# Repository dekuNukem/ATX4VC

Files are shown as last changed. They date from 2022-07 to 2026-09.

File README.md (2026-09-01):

# ATX4VC: ATX Power on Retro Computers!

[Buy ATX4VC](https://www.tindie.com/products/dekuNukem/atx4vc-atx-power-on-retro-computers/) | [Discord](https://discord.gg/T9uuFudg7j) | [User Manual](#user-manual) | [Table of Contents](#Table-of-Contents)

ATX4VC lets you **use ATX power supply on vintage computers**.

* Plug in ATX PSU on one end
* Get 12V, 5V, 3.3V, -12V, -5V out the other!

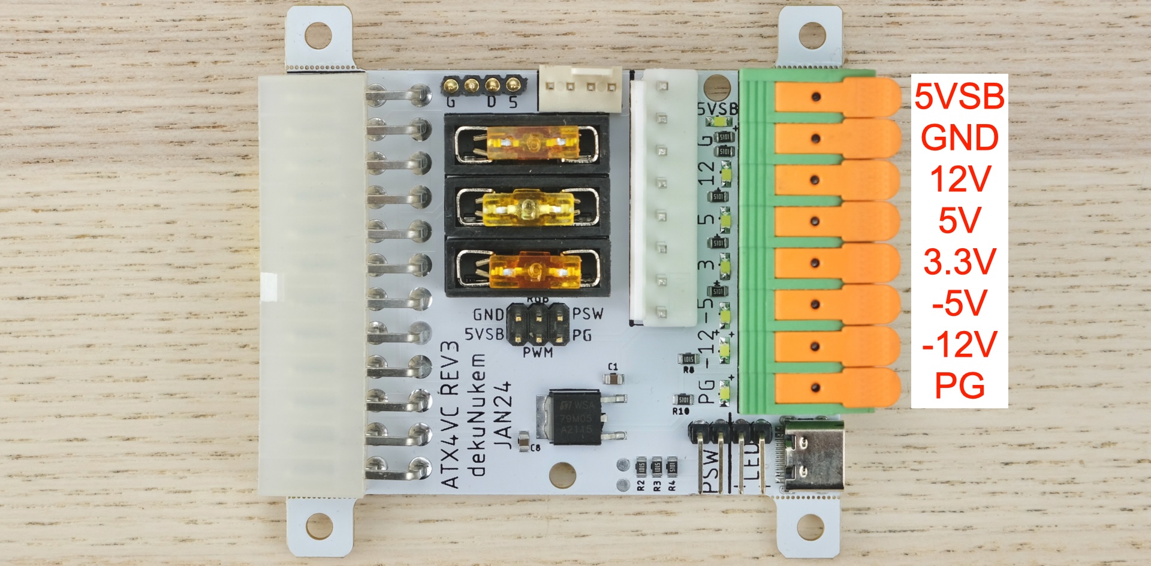
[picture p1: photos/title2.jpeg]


Features:

* All common voltage rails: +12V, +5V, +3.3V, -5V, -12V.
	* Also `5V Standby` and `Power-Good`
* Toolless Lever-Actuated Terminal Block
* USB-C Power Output
* 2x PC Fan Headers

You can use ATX4VC to:

* Replace retro computer PSUs
* Test and diagnose vintage hardware
* As general-purpose multi-voltage bench PSU

## Get ATX4VC

[Click me to get one!](https://www.tindie.com/products/dekuNukem/atx4vc-atx-power-on-retro-computers/)

## PicoRC

Also [check out PicoRC](https://picorc.com) for **device-specific** and **lower-cost** PicoPSU adaptors.

## Showcase

Here ATX4VC replaces the dead PSU in my IBM 5155 Portable PC, providing +12, +5, -12, and -5V.

Note the significant simplification and space/weight saving.

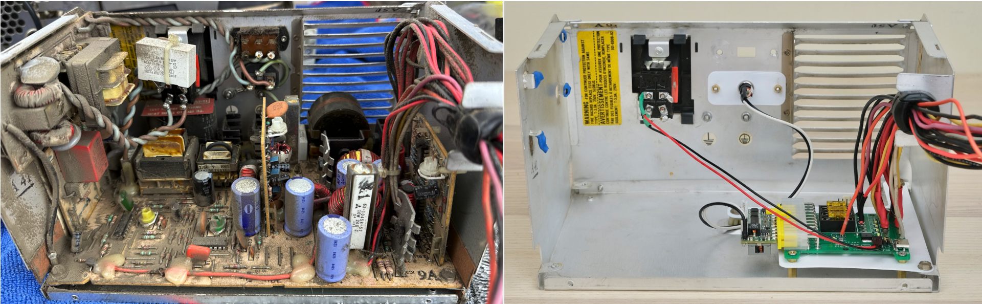
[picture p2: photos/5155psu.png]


It also works as a **multi-voltage bench PSU** for testing and diagnostics.

Here it powers a Macintosh Plus motherboard with +12, +5, and -12V.

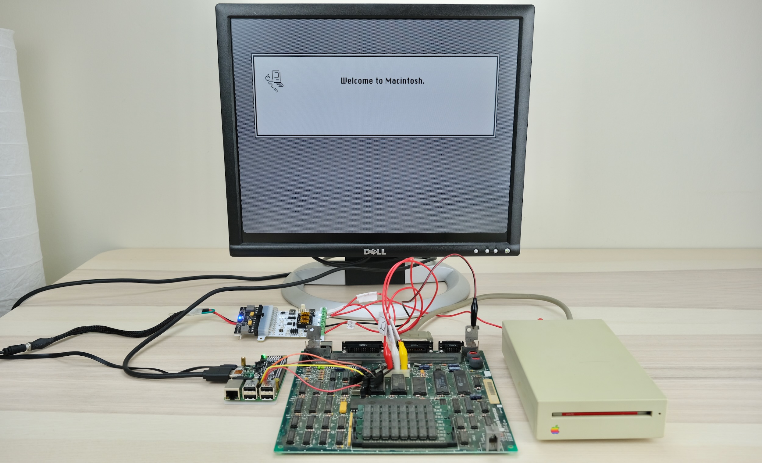
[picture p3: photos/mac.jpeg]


## Why

Power supplies are a major failure point of old computers today.

Those early PSUs are heavy, inefficient, and (slightly) explosive! After 40 odd years, many are not working, or worse might cause damage with out-of-spec voltages.

ATX4VC is designed to replace them with much more reliable modern ATX PSUs, and help test and diagnose vintage computers.

## User Manual

### ATX vs Pico PSU

ATX4VC works with **any ATX PSU**.

Although for **permanent retrofitting**, a **PicoPSU** is recommended due to its compact size.

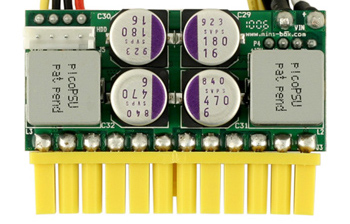
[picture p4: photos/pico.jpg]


* [Official website](https://www.mini-box.com/DC-DC) and [distributors](https://www.mini-box.com/site/resellers.html)
    * The cheapest **80W** one should be plenty for most
    * The **160W** variant is recommended if using many expansion cards and/or **spinning hard drive**
* Avoid **generic clones**
    * They over-rate and are of low quality
* A power brick with **12V DC** and **center positive** 5.5x2.5mm barrel jack is also needed.
    * They are very popular and you might already have one
    * Make sure it has enough wattage

### Quick Start

* Don't connect any load yet!

1. Plug in ATX connector
2. On **Power Mode** switch, select **Soft Power** (left position).
3. Press the button

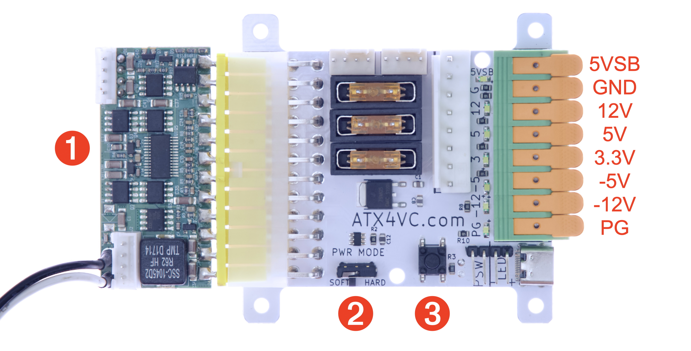
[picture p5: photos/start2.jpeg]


PSU should turn on, voltage rail LEDs should light up. 

That's the gist of it! **Please do keep reading** for more info.

### Power Modes

* Soft Power
    * **Short press** once to turn on
    * Short press again to turn off
    * Suitable for **momentary push buttons**
* Hard Power
    * **Hold down** to power on
    * **Release** to power off
    * Suitable for **latching buttons / flip switches**
    * Connected directly to ATX **PS_ON** Signal

### External Power Button and Power LED

You can also attach an **external power button** and **power LED** to the headers below:

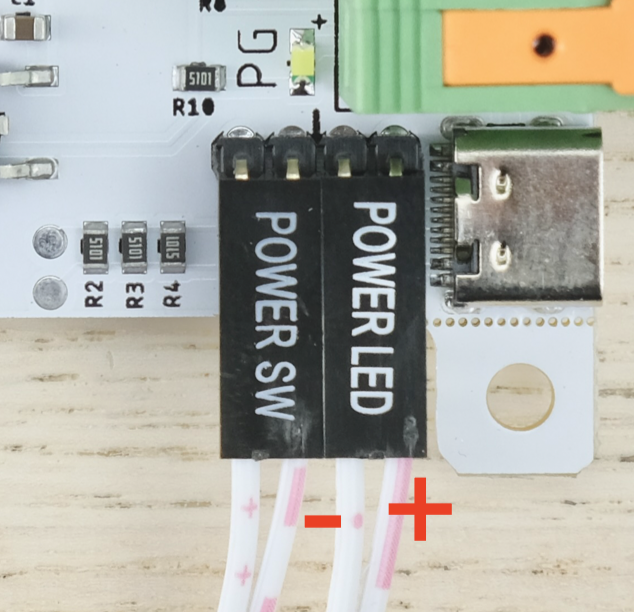
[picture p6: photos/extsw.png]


* Note LED polarity
* LED header has built-in **330 Ohm** resistor 
* Select suitable power mode
    * Soft Power: Momentary Pushbuttons
    * Hard Power: Latching Buttons / Flip Switches

### Power Connection

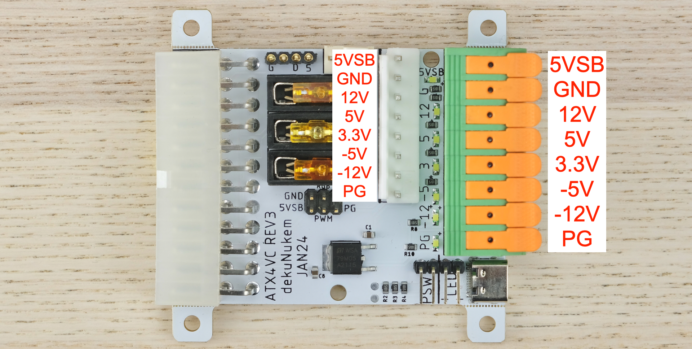
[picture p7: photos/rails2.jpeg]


* See photo for power rails
    * For aux output harness, use **8P JST VH 3.96** female connector.
* 5VSB = 5V Standby
    * Available even when PSU is off
* Power Good Signal
    * 5V when all rails are stable
    * 0V otherwise

To connect a wire:

* Strip the insulation about 12mm / 0.5in.
* Lift handle, insert, push back down.

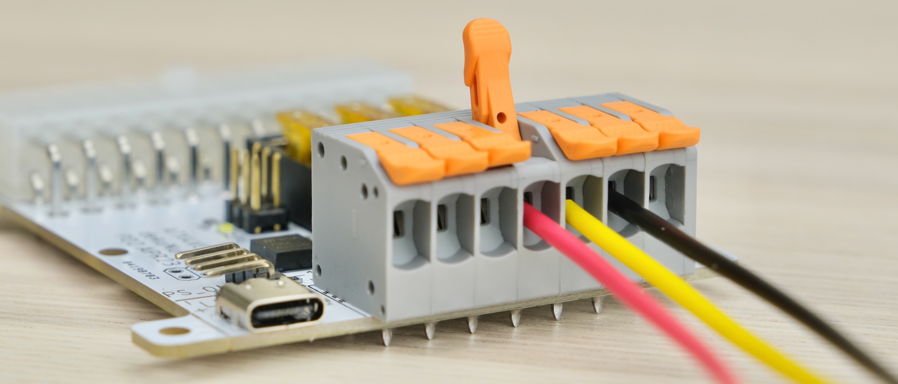
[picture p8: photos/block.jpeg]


Also, make sure the conductor is thick enough!

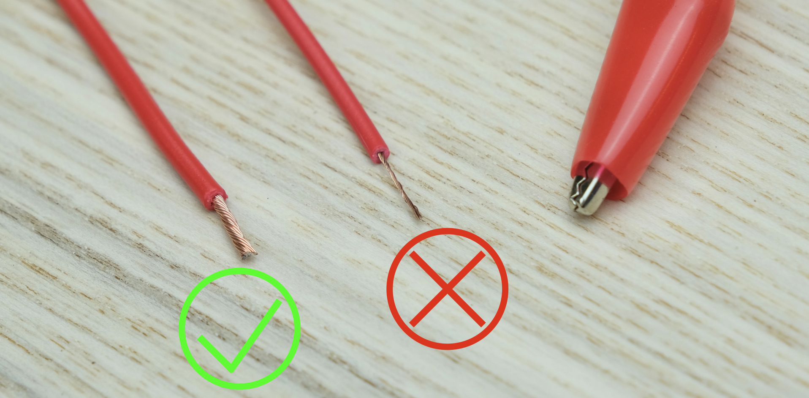
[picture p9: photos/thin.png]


Label the rails, vinyl stickers are available on the [product page](https://www.tindie.com/products/dekuNukem/atx4vc-atx-power-on-retro-computers/):

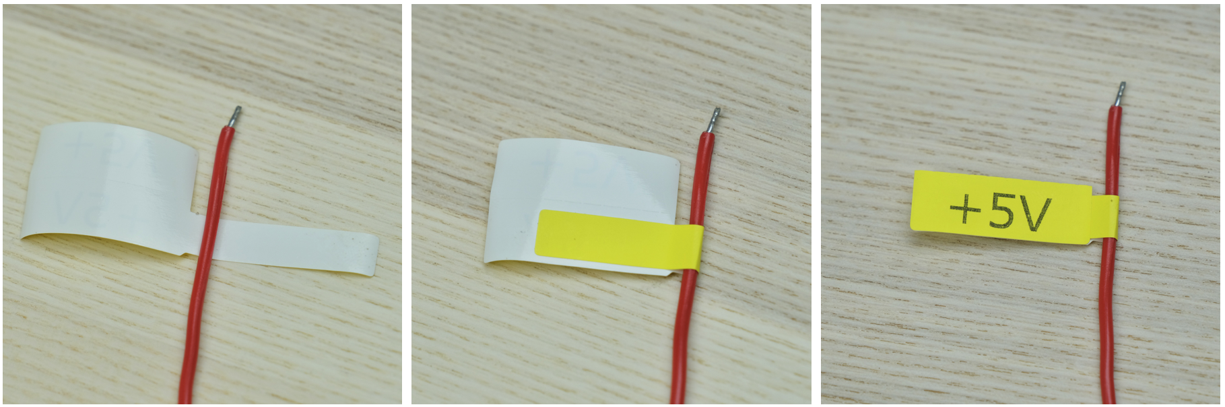
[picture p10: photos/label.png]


### Pre-flight Checks

Before powering up:

* Double check the **correct voltage terminal** is used
* Check for **dead shorts** between each voltage rail and GND, and between themselves!

Once powered up:

* Check voltage readings on each rail

Remember that ATX4VC **DOES NOT** monitor or condition voltage rails, so ensure the PSU itself is of good quality and trustworthy!

### Current Limit

* **`5 AMPS MAX`** OVER **ANY SINGLE RAIL**
* **`7 AMPS MAX`** **TOTAL CURRENT** OVER ALL RAILS

If more is needed, **tap the power directly** from a Molex connector.

See your PSU label or datasheet to see how much current it can provide:

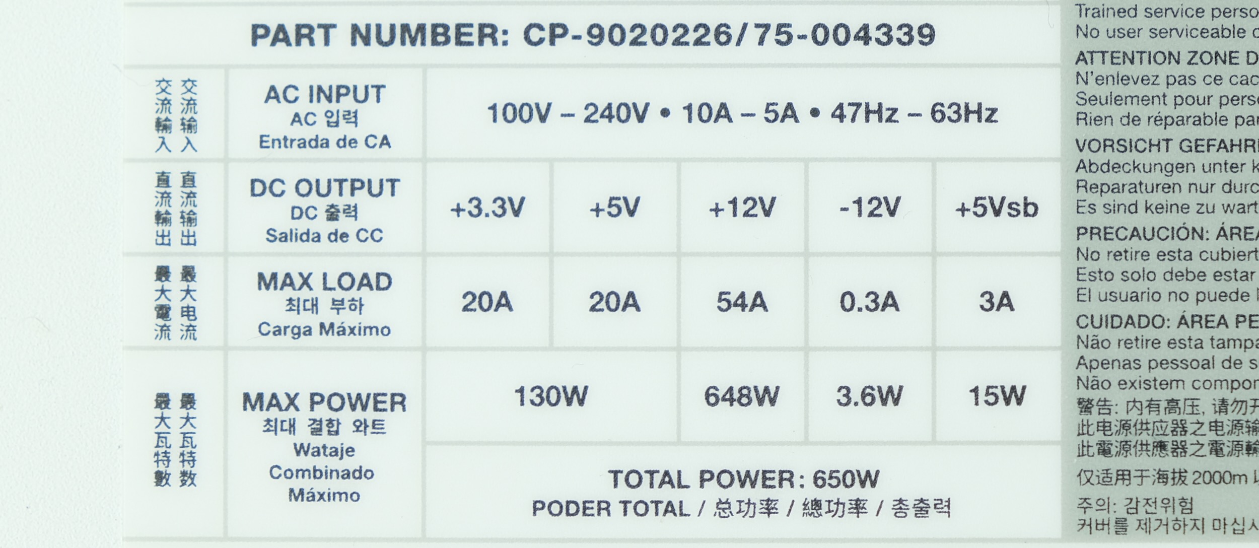
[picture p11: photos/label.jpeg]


### Fuses

* USE FUSES RATED **5A OR LESS**
* **DO NOT BYPASS FUSES**

ATX4VC uses common **automotive fuses**.

Regular, Mini, and Low-profile Mini all work.

Simply push into the holder.

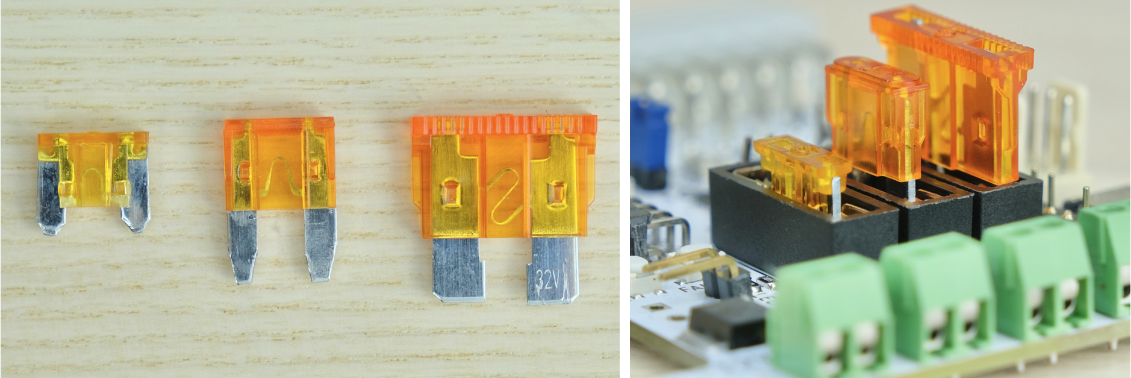
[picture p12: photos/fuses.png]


### Fan Headers

Two PC Fan headers are available. You can plug in any regular **12V PC fan**, both 3-Pin and 4-Pin.

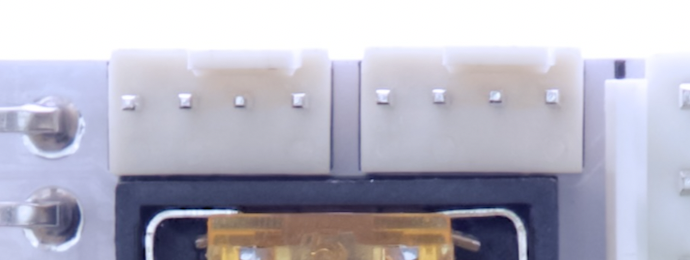
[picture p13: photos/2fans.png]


### USB-C Power Output

An USB-C port is available for **powering external devices**.

* **OUTPUT ONLY**, **DO NOT BACKFEED** with another powered device.

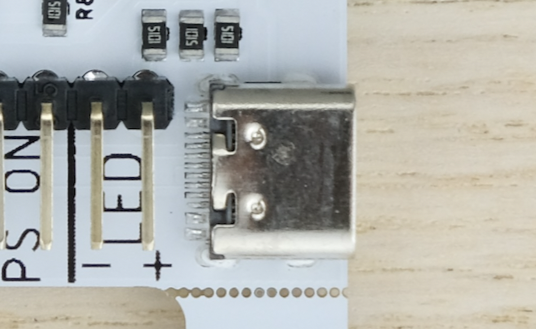
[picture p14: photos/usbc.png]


## Questions or Comments?

Feel free to ask in official [Discord Chatroom](https://discord.gg/T9uuFudg7j), raise a [Github issue](https://github.com/dekuNukem/ATX4VC/issues), or email `dekunukem` `gmail.com`!

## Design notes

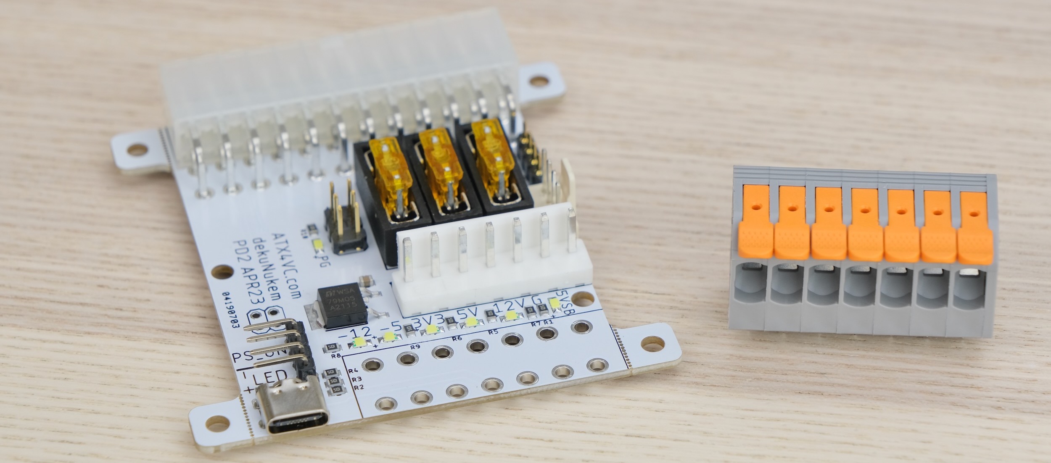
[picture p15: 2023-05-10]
photos/noblock.jpeg

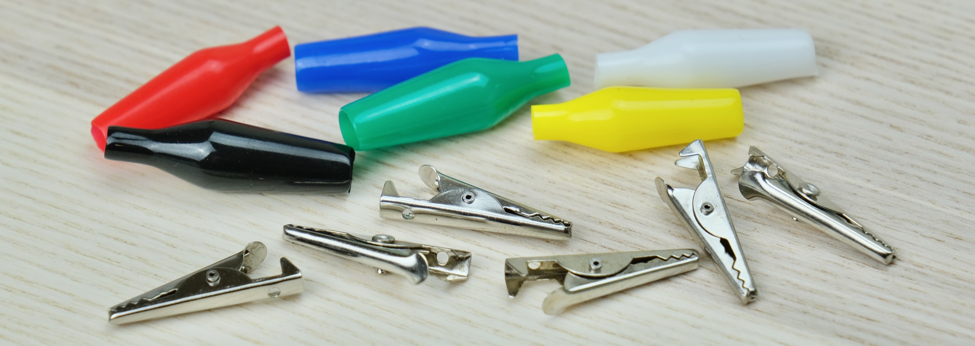
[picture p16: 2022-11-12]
photos/clips.jpeg

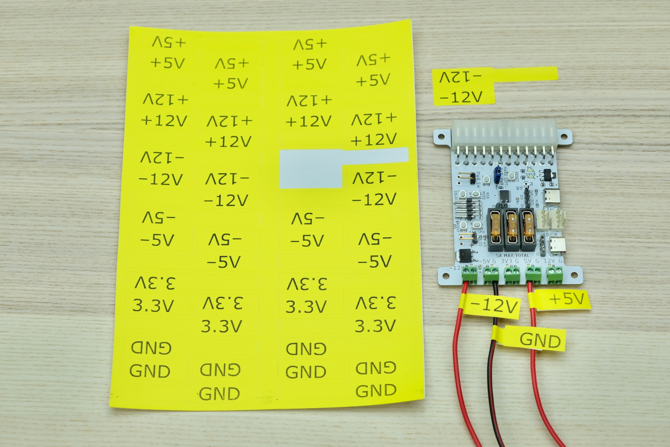
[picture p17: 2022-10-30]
photos/stickers.jpeg

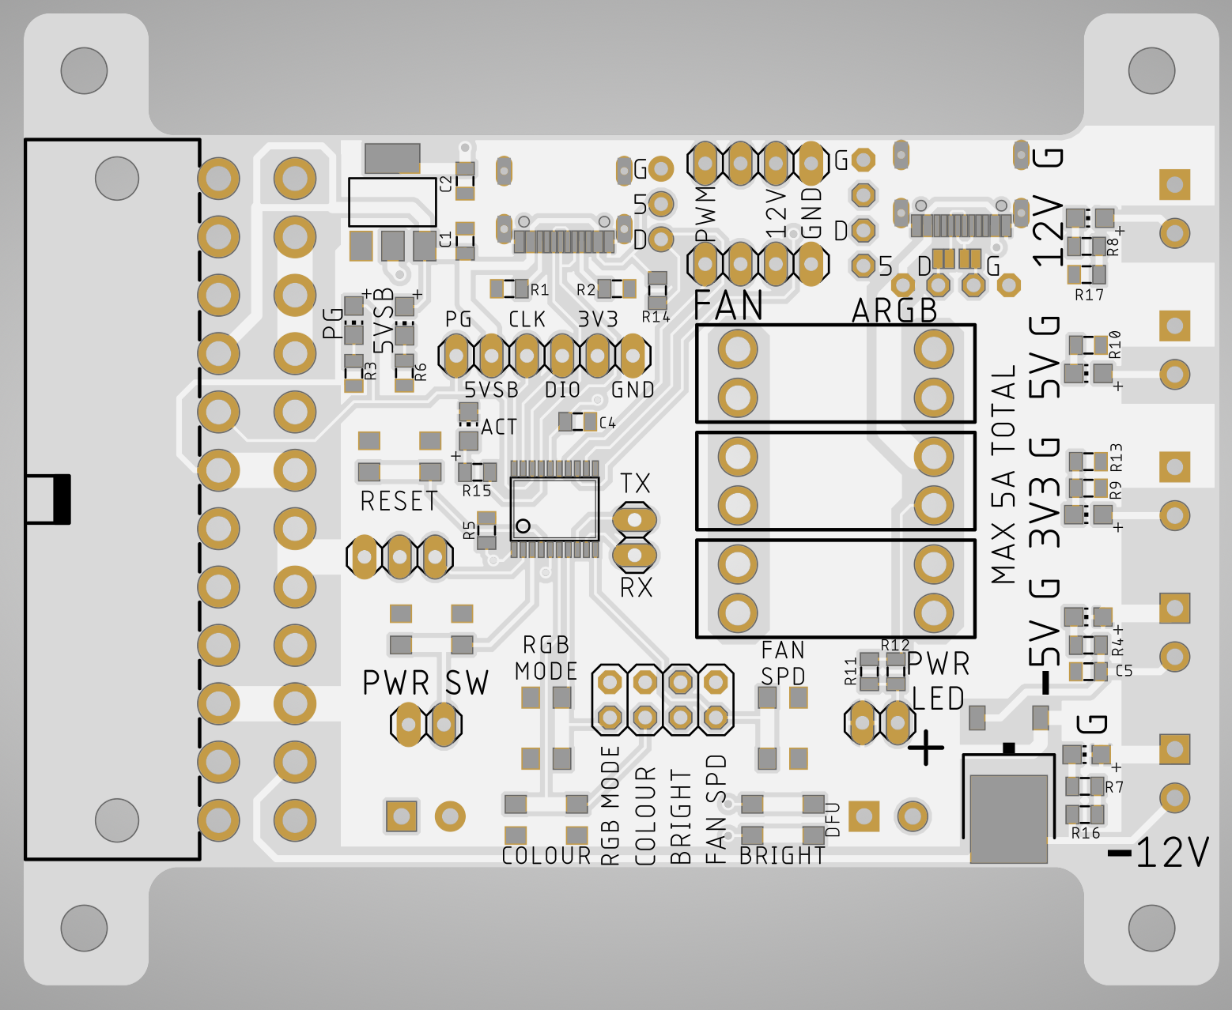
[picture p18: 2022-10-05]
photos/dp.png

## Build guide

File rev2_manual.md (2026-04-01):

# ATX4VC: ATX Power on Retro Computers!

[Buy ATX4VC](https://www.tindie.com/products/dekuNukem/atx4vc-atx-power-on-retro-computers/) | [Discord](https://discord.gg/T9uuFudg7j) | [User Manual](#user-manual) | [Table of Contents](#Table-of-Contents)

ATX4VC lets you **use ATX power supply on vintage computers**.

* Plug in ATX PSU on one end
* Get 12V, 5V, 3.3V, -12V, -5V out the other!



Features:

* All common voltage rails: +12V, +5V, +3.3V, -5V, -12V.
	* Also `5V Standby` and `Power-Good`
* Tool-less Lever-Actuated Terminal Block
* USB-C and Auxiliary Power Output
* PC Fan Header

You can use ATX4VC to:

* Replace retro computer PSUs
* Test and diagnose vintage hardware
* As general-purpose multi-voltage bench PSU

## Get ATX4VC

[Click me to get one!](https://www.tindie.com/products/dekuNukem/atx4vc-atx-power-on-retro-computers/)

## PicoRC

Also [Check out PicoRC](https://github.com/dekuNukem/PicoRC) for **device-specific** and **lower-cost** PicoPSU adaptors.

## Showcase

Here ATX4VC replaces the dead PSU in my IBM 5155 Portable PC, providing +12, +5, -12, and -5V.

Note the significant simplification and space/weight saving.



It also works as a multi-voltage bench PSU for testing and diagnostics.

Here it powers a Macintosh Plus motherboard with +12, +5, and -12V.



## Why / Project Goals

Power supplies are a major failure point of old computers today.

Those early PSUs are heavy, inefficient, hot, and (slightly) explosive! After 40 odd years, many are not working, or worse might cause damage with out-of-spec voltages.

ATX4VC is designed to replace them with much more reliable modern ATX PSUs, and help test and diagnose vintage computers.

## Table of Contents

- [Pico PSU](#get-a-pico-psu)
- [Quick Start](#quick-start)
- [Power Button](#power-button)
- [Power Connection](#power-connection)
- [Pre-flight Checks](#pre-flight-checks)
- [Current Limit](#current-limit)
- [Fuses](#fuses)
- [Fan Headers](#fan-headers)
- [USB-C Power Output](#usb-c-power-output)

## User Manual

### ATX vs Pico PSU

ATX4VC works with **any ATX PSU**.

Although for **permanent retrofitting**, a **PicoPSU** is recommended due to its compact size.



* [Official website](https://www.mini-box.com/DC-DC) and [distributors](https://www.mini-box.com/site/resellers.html)
    * The cheapest **80W** one should be plenty for most
    * The **160W** variant is recommended if using many expansion cards and/or **spinning hard drive**
* Avoid **generic clones**
    * They over-rate and are of low quality
* A power brick with **12V DC** and **center positive** 5.5x2.5mm barrel jack is also needed.
    * They are very popular and you might already have one
    * Make sure it has enough wattage

### Quick Start

* Plug in ATX connector
* Plug in Power Button (left two pins)



Press the button. PSU should turn on, voltage rail LEDs should light up. 

That's the gist of it! **Please do keep reading** for more info.

### Power Button and LED

The power button should be latching type (aka NOT momentary).

You can also hook up a Power LED (right two pins, note polarity, resistor NOT needed).

### Power Connection



* Pinout is the same on terminal block and auxiliary connector.
    * For aux output harness, use **8P VH 3.96** female connector.
* 5VSB = 5V Standby
    * Available even when PSU is off
* Power Good Signal
    * 5V when all rails are stable
    * 0V otherwise

To connect a wire:

* Strip the insulation about 12mm / 0.5in.
* Lift handle, insert, push back down.



Also, make sure the conductor is thick enough!



Label the rails, vinyl stickers are available on the [product page](https://www.tindie.com/products/dekuNukem/atx4vc-atx-power-on-retro-computers/):



### Pre-flight Checks

Before powering up:

* Double check the **correct voltage terminal** is used
* Check for **dead shorts** between each voltage rail and GND, and between themselves!

Once powered up:

* Check voltage readings on each rail

Remember that ATX4VC **DOES NOT** monitor or condition PSU voltage outputs, ensure the PSU itself is of good quality and trustworthy!

### Current Limit

* **`5 AMPS MAX`** OVER **ANY SINGLE RAIL**
* **`7 AMPS MAX`** **TOTAL CURRENT** OVER ALL RAILS

If more is needed, **tap the power directly** from a Molex connector.

See your PSU label or datasheet to see how much current it can provide:



### Fuses

* USE FUSES RATED **5A OR LESS**
* **DO NOT BYPASS FUSES**

ATX4VC uses common **automotive fuses**.

Regular, Mini, and Low-profile Mini all work.

Simply push into the holder.



### Fan Headers

A PC Fan header is available. You can plug in any standard 12V PC fan, both 3-Pin and 4-Pin.

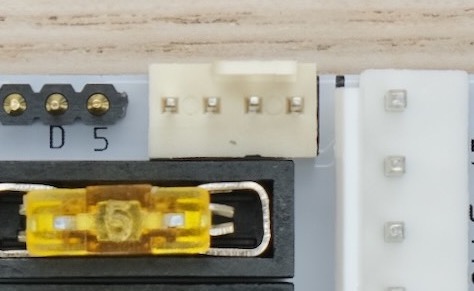
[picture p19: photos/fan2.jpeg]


By default it will run at full speed.

PWM speed control and temperature probe is supported on optional [MCU daughterboard](#mcu-daughterboard).

### USB-C Power Output

USB-C connectors are available for powering external devices.

The port on ATX4VC itself is on regular 5V rail.

The port on MCU daughterboard is on 5V standby. Lower current but always available.

Those ports are **output only**, don't try to backfeed with another powered device.

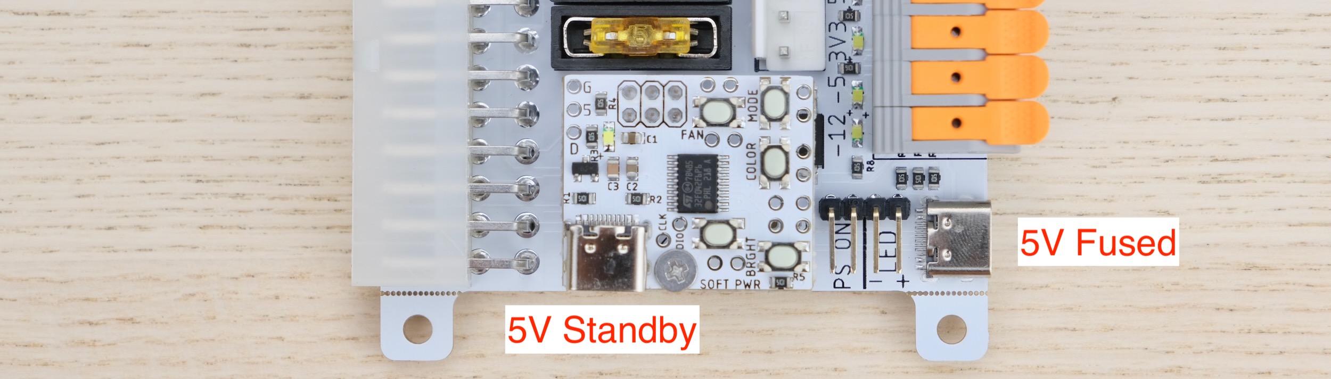
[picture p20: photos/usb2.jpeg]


## MCU Daughterboard

The optional MCU daughterboard adds many new features:

* **Soft power** with momentary buttons
* Addressable RGB (**ARGB**) lighting. Adjustable brightness, animation, and color.
* DS18B20 **Temperature Probe** support
* PWM **fan speed control**
* 5V Standby USB-C power output

### Installation

The MCU board should come with two screws and a standoff:

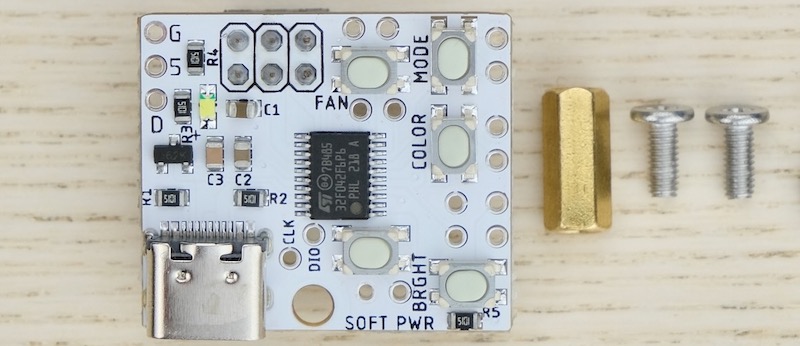
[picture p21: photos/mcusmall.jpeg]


* Put one screw from bottom side
* Install and tighten the standoff
* Plug in the MCU board
* Secure it in place with the other screw

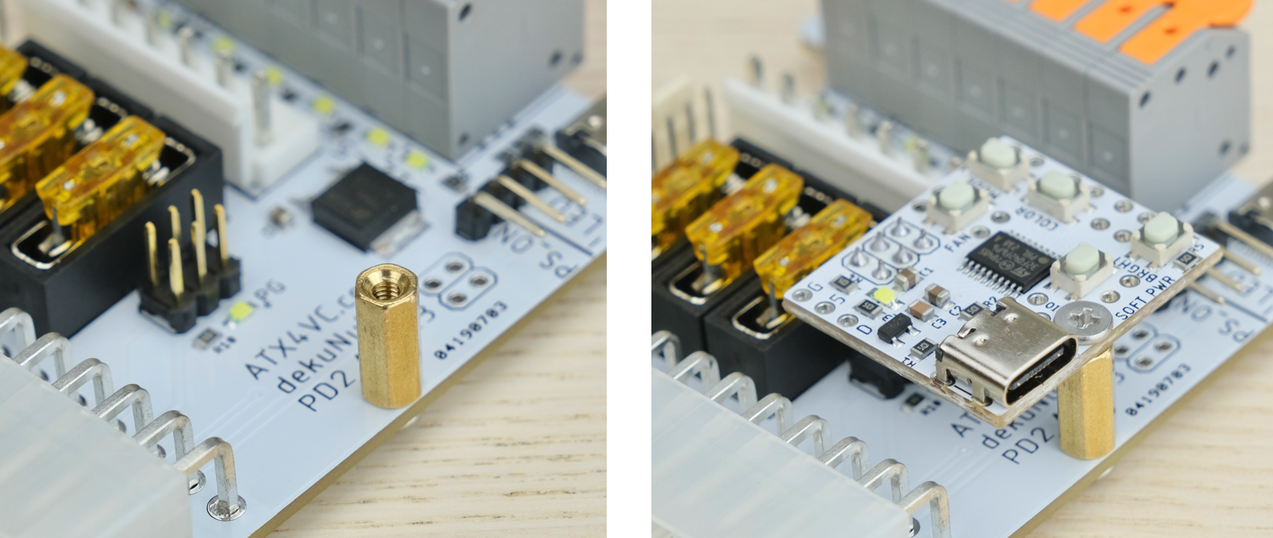
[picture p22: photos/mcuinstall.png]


### Soft Power

Press the soft power button to turn on, press again to turn off.

You can also solder a header for an external button.

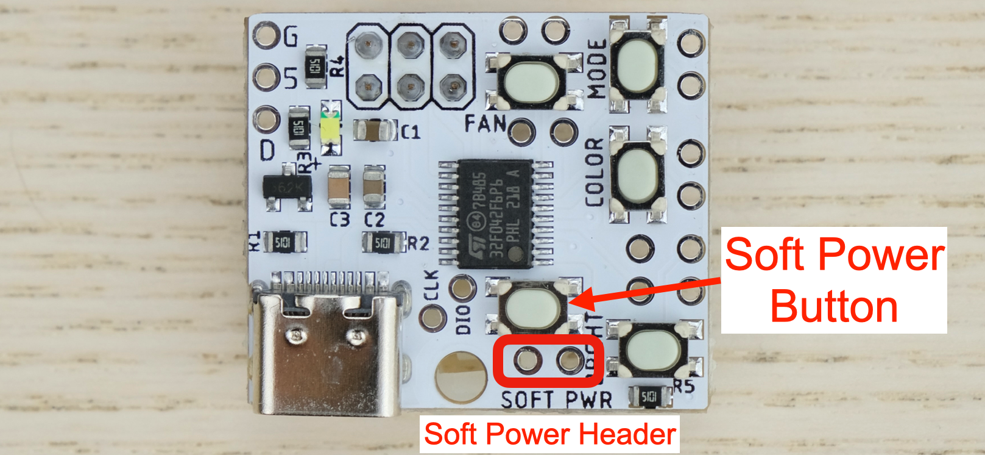
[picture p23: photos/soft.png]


### ARGB animation

Plug device into the ARGB header.

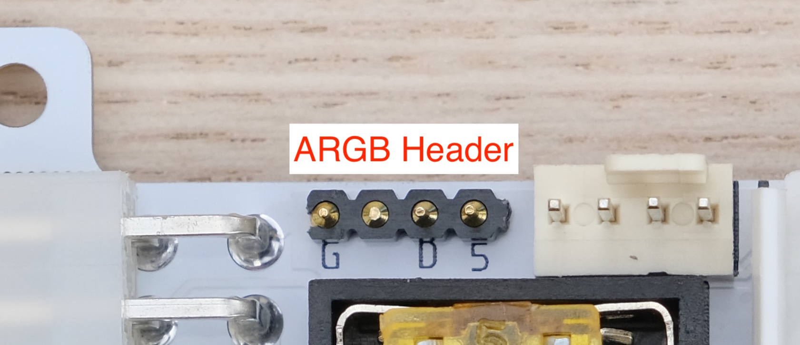
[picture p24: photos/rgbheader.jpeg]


Use **RGB Mode**, **Color**, and **Brightness** button to adjust settings. Headers are available for external buttons.

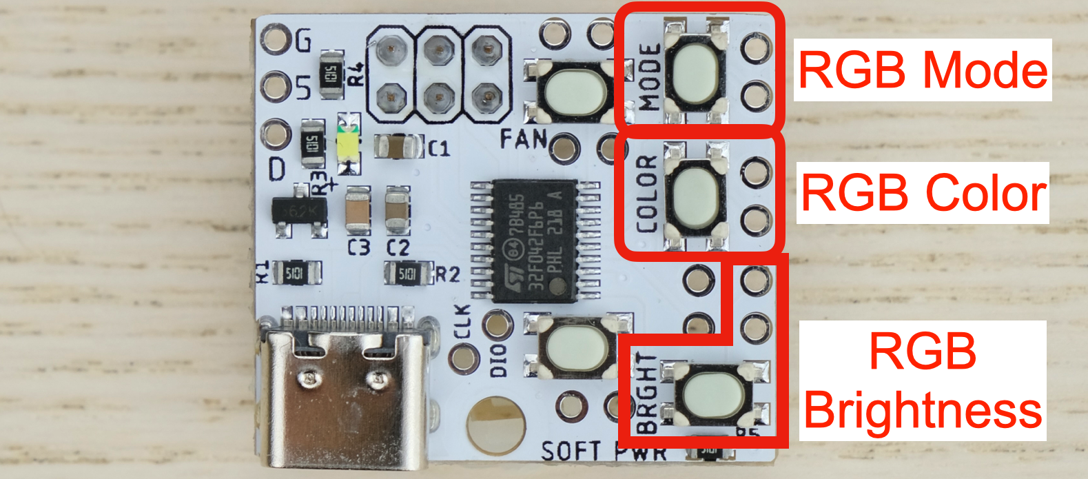
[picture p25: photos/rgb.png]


### Fan Speed

Press `FAN SPD` button to cycle through different speeds:

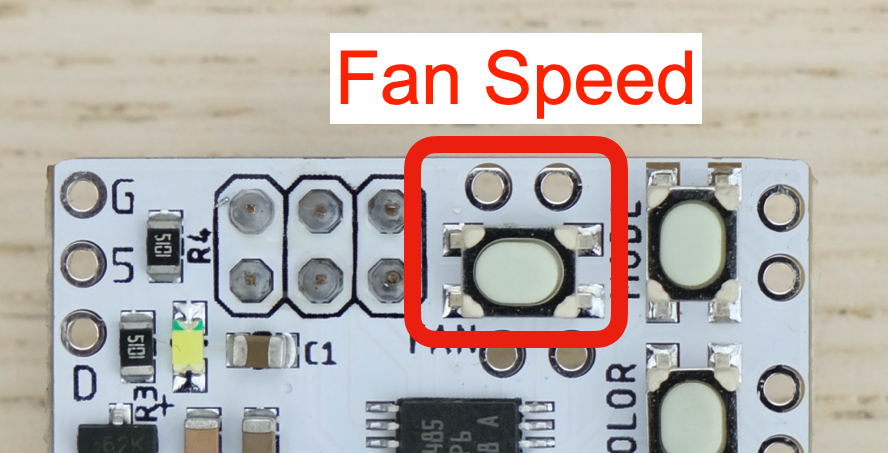
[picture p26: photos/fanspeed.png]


### Temperature Probe

ATX4VC supports the DS18B20 temperature sensor. They are inexpensive and very popular in Arduino projects.

The cheap ones are almost certainly counterfeits! They'll still work, but readings are noisier and less accurate.

Try a reputable distributor like [Sparkfun](https://www.sparkfun.com/products/11050), [Adafruit](https://www.adafruit.com/product/381), Mouser, or Digikey.

Connect the headers. Usually VCC is red, GND is black, DATA is yellow.

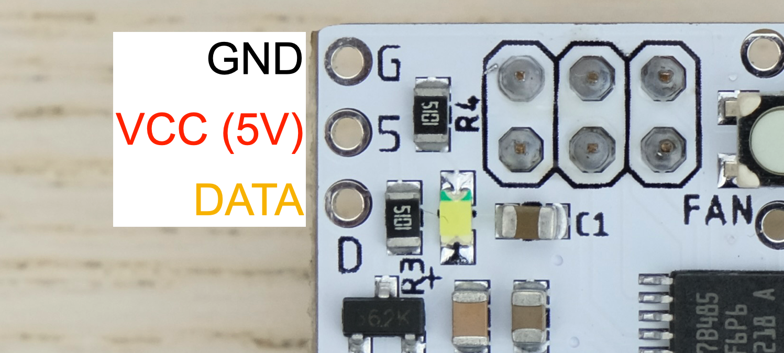
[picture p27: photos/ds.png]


Press **FAN SPD** button until the user LED `slowly blinks 5 times`. Now fan speed will depend on the temperature reading.

The fan starts to speed up at 25°C, and reaches full speed at 50°C. If probe is not detected, it will run at full speed.

You can use a heat gun and air duster to test it.

## Questions or Comments?

Feel free to ask in official [Discord Chatroom](https://discord.gg/T9uuFudg7j), raise a [Github issue](https://github.com/dekuNukem/ATX4VC/issues), or email `dekunukem` `gmail.com`!

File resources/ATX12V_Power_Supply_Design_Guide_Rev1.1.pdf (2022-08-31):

# ATX / ATX12V Power Supply Design Guide

Version 1.1

ATX/ATX12V Power Supply Design Guide
Version 1.1

IMPORTANT INFORMATION AND DISCLAIMERS

1. INTEL CORPORATION (AND ANY CONTRIBUTOR) MAKES NO WARRANTIES WITH REGARD TO THIS DOCUMENT AND IN PARTICULAR DOES NOT WARRANT OR REPRESENT THAT THIS DOCUMENT OR ANY PRODUCTS MADE IN CONFORMANCE WITH IT WILL WORK IN THE INTENDED MANNER. NOR DOES INTEL (OR ANY CONTRIBUTOR) ASSUME RESPONSIBILITY FOR ANY ERRORS THAT THE DOCUMENT MAY CONTAIN OR HAVE ANY LIABILITIES OR OBLIGATIONS FOR DAMAGES INCLUDING, BUT NOT LIMITED TO, SPECIAL, INCIDENTAL, INDIRECT, PUNITIVE, OR CONSEQUENTIAL DAMAGES WHETHER ARISING FROM OR IN CONNECTION WITH THE USE OF THIS DOCUMENT IN ANY WAY.
2. NO REPRESENTATIONS OR WARRANTIES ARE MADE THAT ANY PRODUCT BASED IN WHOLE OR IN PART ON THE ABOVE DOCUMENT WILL BE FREE FROM DEFECTS OR SAFE FOR USE FOR ITS INTENDED PURPOSE. ANY PERSON MAKING, USING OR SELLING SUCH PRODUCT DOES SO AT HIS OR HER OWN RISK.
3. THE USER OF THIS DOCUMENT HEREBY EXPRESSLY ACKNOWLEDGES THAT THE DOCUMENT IS PROVIDED AS IS, AND THAT INTEL CORPORATION (AND ANY CONTRIBUTOR) MAKES NO REPRESENTATIONS, EXTENDS NO WARRANTIES OF ANY KIND, EITHER EXPRESS OR IMPLIED, ORAL OR WRITTEN, INCLUDING ANY WARRANTY OF MERCHANTABILITY OR FITNESS FOR A PARTICULAR PURPOSE, OR WARRANTY OR REPRESENTATION THAT THE DOCUMENT OR ANY PRODUCT OR TECHNOLOGY UTILIZING THE DOCUMENT OR ANY SUBSET OF THE DOCUMENT WILL BE FREE FROM ANY CLAIMS OF INFRINGEMENT OF ANY INTELLECTUAL PROPERTY, INCLUDING PATENTS, COPYRIGHT AND TRADE SECRETS NOR DOES INTEL (OR ANY CONTRIBUTOR) ASSUME ANY OTHER RESPONSIBILITIES WHATSOEVER WITH RESPECT TO THE DOCUMENT OR SUCH PRODUCTS.
4. NO LICENSE, EXPRESS OR IMPLIED, BY ESTOPPEL OR OTHERWISE, TO ANY INTELLECTUAL PROPERTY RIGHTS IS GRANTED HEREIN.

Copyright 2000 Intel Corporation. All rights reserved.

Version 1.1
† Third-party brands and names are the property of their respective owners.

Revision History

Version | Summary of Changes | Date
1.0 | Initial Release | Feb. 2000
1.1 | Increase 3.3 V current; add more explanation for power sharing; do minor edits and format fixes | Aug. 2000

# Contents

4.5.3. Auxiliary Power Connector for Configurations with +3.3 VDC Output > 18 A
6.2. Input Line Current Harmonic Content and Line Flicker Required for Sales

### Figures

Figure 1. Differential Noise Test Setup | | 15
Figure 2. Power Supply Timing | | 17
Figure 3. PS_ON# Signal Characteristics | | 19
Figure 4. Power Supply Dimensions for Chassis in Which the P/S Does Not Cool Processor | | 23
Figure 5. Power Supply Dimensions for Chassis in Which the P/S Cools the Processor | | 24
Figure 6. ATX and ATX12V Power Supply Connectors | | 27

### Tables

Table 1. Power Supply Feature Summary, ATX versus ATX12V | | 7
Table 2. AC Input Line Requirements | | 9
Table 3. DC Output Voltage Regulation | | 10
Table 4. Typical Power Distribution for a 160 W ATX Configuration | | 11
Table 5. Typical Power Distribution for a 200 W ATX Configuration | | 12
Table 6. Typical Power Distribution for a 250 W ATX Configuration | | 12
Table 7. Typical Power Distribution for a 300 W ATX Configuration | | 12
Table 8. Typical Power Distribution for a 200 W ATX12V Configuration | | 13
Table 9. Typical Power Distribution for a 250 W ATX12V Configuration | | 13
Table 10. Typical Power Distribution for a 300 W ATX12V Configuration | | 14
Table 11. DC Output Noise/Ripple | | 15
Table 12. DC Output Transient Step Sizes | | 16
Table 13. Output Capacitive Loads | | 16
Table 14. PWR_OK Signal Characteristics | | 18
Table 15. PS_ON# Signal Characteristics | | 18
Table 16. Overvoltage Protection | | 20

# 1. Introduction

## 1.1. Scope

This document provides design suggestions and reference specifications for a family of power supplies that comply with the ATX Specification, Version 2.03*
for motherboards
and chassis. It includes supplementary information not expressly detailed in the ATX Specification, such as information about the physical form factor of the power supply, cooling requirements, connector configuration, and pertinent electrical and signal timing specifications.
This document is provided as a convenience only and is not intended to replace the user’s independent design and validation activity. It should not be inferred that all ATX or ATX12V power supplies must conform exactly to the content of this document. Neither are the design specifics described herein intended to support all possible system configurations, because system power supply needs vary widely depending on factors such as the application (that is, for desktop, workstation, or server), intended ambient environment (temperature, line voltage), or motherboard power requirements.

## 1.2. New for ATX12V as Compared with ATX Power Supply

This section briefly summarizes the major changes made to this document that now includes the ATX12V power supply. An earlier design guide covered only the ATX power supply. There are also a few changes from Version 1.0 to 1.1 (increased 3.3 V current, more explanation for power sharing).

### 1.2.1. ATX12V

A new superset of the original ATX power supply has been defined. Named “ATX12V,” this new power supply is comprised of a standard ATX unit plus the following enhancements:
- Increased +12 VDC output capability. Motherboard components with unique voltage requirements are increasingly expected to be powered via DC/DC converters off the +12 VDC power supply output. This trend is due primarily to the higher power conversion and transmission efficiencies of +12 VDC relative to +5 VDC or +3.3 VDC. ATX12V power supplies should be designed to accommodate these increased +12 VDC current requirements and to address associated issues such as cross-regulation, capacitive loading, transient surge tolerance, cable voltage drop, and cooling.

*
2.03 is the current version of the ATX Specification as of this writing. Future references to the ATX Specification in this document imply version 2.03 or later, as applicable.

- Power Connectors. To enable the delivery of more +12 VDC current to the motherboard, a new 4-pin receptacle/header combination—the +12 V power connector—has been defined. The presence of the +12 V power connector indicates that a power supply is ATX12V; the absence of the +12 V power connector indicates that a supply is ATX. To allow for greater than 3.3 V current, the Aux Power Connector is recommended for ATX and ATX12V power supplies with 3.3 V current > 18 A. See Sections 3.2.3.2 and 4.5 for details on the +12 V and AUX power connector.
ATX12V power supplies are intended to be downward compatible with ATX power supplies. Consequently, it is required that an ATX12V power supply be able to provide the same typical +5 VDC and +3.3 VDC maximum continuous output currents as an ATX supply of the same total output power. To minimize cost, this may be accomplished via a load sharing arrangement, whereby the individual +12 VDC, +5 VDC, and +3.3 VDC output currents may trade off against each other but the combined total output power is constrained to not exceed a limit specified by the power supply designer. Such an approach can effectively support both +5 VDC- or +12 VDC-centric motherboards.
The standard ATX power supply definition will be maintained in parallel with ATX12V— despite the downward compatibility of ATX12V—because both offer distinct advantages to the industry:
- An ATX power supply supports motherboards that rely on DC/DC conversion from +5 VDC or +3.3 VDC only. This limitation and an initial volume advantage make it more attractive for focussed, cost-sensitive system platforms.
- An ATX12V power supply supports motherboards that rely on DC/DC conversion from either +12 VDC, +5 VDC, or +3.3 VDC, yielding more application flexibility for future platforms.

### 1.2.2. Increased +5 VSB Current

Trends in PC system power management solutions (for example, “Instantly Available PC,” “Suspend-to-RAM”) are driving a need for increased +5 VSB current capability for all ATX-family power supplies. The previous +5 VSB output requirement is being raised to 1.0 amps minimum, with 2.0 amps preferred. Recommendations for momentary peak current have also been added to enable USB "wake on" devices. See Section 3.3.3 for details.
Table 1. Power Supply Feature Summary, ATX versus ATX12V
ATX | ATX12V
+12 V power connector No | Yes
+5 VSB current | 1.0 amps 1.5 Peak (required)
2.0 amps 2.5 Peak (recommended)

1.0 amps 1.5 Peak (required)
2.0 amps 2.5 Peak (recommended)

# 2. Applicable Documents

The latest revision in effect of the following documents forms a part of this document to the extent specified.

Document title | Description
AB13-94-146 | European Association of Consumer Electronics Manufacturers (EACEM) Hazardous Substance List / Certification
ANSI C62.41-1991 | IEEE Recommended Practice on Surge Voltages in Low-Voltage AC Circuits
ANSI C62.45-1992 | IEEE Guide on Surge Testing for Equipment Connected to Low-Voltage AC Power Circuits
MIL-STD-105K | Quality Control
MIL-STD-217F | Reliability Predictions for Electronic Equipment
MIL-C-5541 | Chemical Conversion Coatings on Aluminum and Aluminum Alloys
CSA C22.2 No.234, Level 3 | Safety of Component Power Supplies (Intended for use with Electronic Data Processing Equipment and Office Machines)
CAN/CSA C22.2 No.950-95, 3rd edition | Safety of Information Technology Equipment Including Electrical Business Equipment
UL 1950, 3rd edition, without D3 Deviation | Safety of Information Technology Equipment Including Electrical Business Equipment
IEC 60950 plus A1, A2, A3, A4 | Safety of Information Technology Equipment Including Business Equipment
EN 60950 plus A1, A2, A3, A4 | Safety of Information Technology Equipment Including Business Equipment
EMKO-TSE (74-SEC) 207/94 | Nordic national requirement in addition to EN 60950
CISPR 22:1997 3rd edition EN 55022:1998 | Limits and Methods of Measurements of Radio Interference Characteristics of Information Technology Equipment, Class B
ANSI C63.4 – 1992 | American National Standard for Methods of Measurement of Radio-Noise Emissions from Low-Voltage Electrical and Electronic Equipment in the Range of 9 kHz to 40 GHz for EMI testing
EN 55024:1998 | Information technology equipment—Immunity characteristics—Limits and methods of measurement
EN 61000-3-2 | Electromagnetic compatibility (EMC)—Part 3: Limits—Section 2: Limits for harmonic current emissions, Class D
IEC 61000-4- | Electromagnetic compatibility (EMC) for industrial-process measurement and control equipment—Part 4: Testing and measurement techniques Section -2: Electrostatic discharge Section -3: Radiated, radio-frequency, electromagnetic field Section -4: Electrical fast transient / burst Section -5: Surge Section -6: Conducted disturbances, induced by radio-frequency fields Section -8: Power frequency magnetic fields Section -11: Voltage dips, short interruptions, and voltage variations
Japan Electric Association | Guidelines for the Suppression of Harmonics in Appliances and General Use Equipment
IEC Publication 417 | International Graphic Symbol Standard
ISO Standard 7000 | Graphic Symbols for Use on Equipment
CFR 47, Part 15, Subpart B | FCC Rules

# 3. Electrical

The electrical requirements that follow are to be met over the environmental ranges specified in Section 5 unless otherwise noted.

## 3.1. AC Input

Table 2 lists AC input voltage and frequency requirements for continuous operation. The power supply shall be capable of supplying full-rated output power over two input voltage ranges rated 100-127 VAC and 200-240 VAC rms nominal. The correct input range for use in a given environment may be either switch-selectable or autoranging. The power supply shall automatically recover from AC power loss. The power supply must be able to start up under peak loading at 90 VAC.
Table 2. AC Input Line Requirements
Parameter | Min. | Nom. ⁽¹⁾ | Max. | Unit
Vin (115 VAC) | 90 | 115 | 135 | VACrms
Vin (230 VAC) | 180 | 230 | 265 | VACrms
Vin Frequency | 47 | -- | 63 | Hz
(1) Nominal voltages for test purposes are considered to be within ±1.0 V of nominal.

### 3.1.1. Input Overcurrent Protection

The power supply shall incorporate primary fusing for input overcurrent protection to prevent damage to the power supply and meet product safety requirements. Fuses should be slow-blow–type or equivalent to prevent nuisance trips.

### 3.1.2. Inrush Current Limiting

Maximum inrush current from power-on (with power on at any point on the AC sine) and including, but not limited to, three line cycles, shall be limited to a level below the surge rating of the input line cord, AC switch if present, bridge rectifier, fuse, and EMI filter components. Repetitive ON/OFF cycling of the AC input voltage should not damage the power supply or cause the input fuse to blow.

### 3.1.3. Input Undervoltage

The power supply shall contain protection circuitry such that the application of an input voltage below the minimum specified in Section 3.1, Table 2, shall not cause damage to the power supply.

### 3.1.4. Immunity

At a minimum, a system and power supply typically must pass testing per the limits and methods described in EN 55024 prior to sale in many parts of the world. Additional requirements may depend on the design, product end use, target geography, customer, and other variables. Consult your company’s Product Safety and Regulations department for more details.

### 3.1.5. Catastrophic Failure Protection

Should a component failure occur, the power supply should not exhibit any of the following:
- Flame
- Excessive smoke
- Charred PCB
- Fused PCB conductor
- Startling noise
- Emission of molten material

## 3.2. DC Output

### 3.2.1. DC Voltage Regulation

The DC output voltages shall remain within the regulation ranges shown in Table 3 when measured at the load end of the output connectors under all line, load, and environmental conditions. The voltage regulation limits shall be maintained under continuous operation for a period of time equal to or greater than the MTBF specified in Section 7.2 at any steady state temperature and operating conditions specified in Section 5.
Table 3. DC Output Voltage Regulation
Output | Range | Min. | Nom. | Max. | Unit
+12VDC (1) | ±5% | +11.40 | +12.00 | +12.60 | Volts
+5VDC | ±5% | +4.75 | +5.00 | +5.25 | Volts
+3.3VDC | ±5% | +3.14 | +3.30 | +3.47 | Volts
-5VDC | ±10% | -4.50 | -5.00 | -5.50 | Volts
-12VDC | ±10% | -10.80 | -12.00 | -13.20 | Volts
+5VSB | ±5% | +4.75 | +5.00 | +5.25 | Volts
(1) At +12 VDC peak loading, regulation at the +12 VDC output can go to ± 10%.

### 3.2.2. Remote Sensing

The +3.3 VDC output should have provisions for remote sensing to compensate for excessive cable drops. The default sense should be connected to pin 11 of the main power connector. The power supply should draw no more than 10 mA through the remote sense line to keep DC offset voltages to a minimum.

### 3.2.3. Typical Power Distribution

DC output power requirements and distributions will vary widely based on specific system options and implementation. Significant dependencies include the quantity and types of processors, memory, add-in card slots, and peripheral bays, as well as support for advanced graphics or other features. It is ultimately the responsibility of the designer to derive a power budget for a given target product and market.
Tables 4 through 10 provide sample power distributions and cross-loading diagrams as a reference only. The tabular data summarizes maximum and minimum loadings on each output, regardless of cross-regulation. The diagrams show typical assumptions for cross-loading: The area within each plotted perimeter represents the power usage of a motherboard and system platform. At a minimum, the power supply must have the capability to provide power for the area inside the plotted area. The power supply may provide additional margin for the area outside the perimeter. In each graph, the vertical line on the right side shows the recomended combined power from 3.3 V and 5 V; the upper horizontal line is the recommended 12 V power; and the total power is the power expected from all rails for any system configuration. The power supply will share power between the 5 V, 3.3 V, and 12 V to provide the maximum rated power under the possible loading conditions shown in each graph. It should not be inferred that all power supplies must conform to these tables, nor that a power supply designed to meet the information in the tables will work in all system configurations.

### 3.2.3.1. ATX Configurations

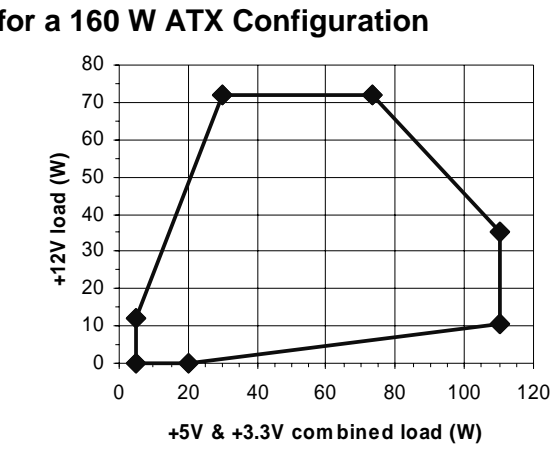
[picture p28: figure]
+5V & +3.3V com bined load (W); +12V load (W)

Table 4. Typical Power Distribution for a 160 W ATX Configuration

Output

Min.
Current
(amps)

Max.
Current
(amps)

Peak
Current
(amps)
+12 VDC | 0.0 | 6.0 | 8.0
+5 VDC | 1.0 | 18.0
+3.3 VDC | 0.3 | 14.0
-5 VDC | 0.0 | 0.3
-12 VDC | 0.0 | 0.8
+5 VSB | 0.0 | 1.5 | 2.5

See graph at right for power sharing.

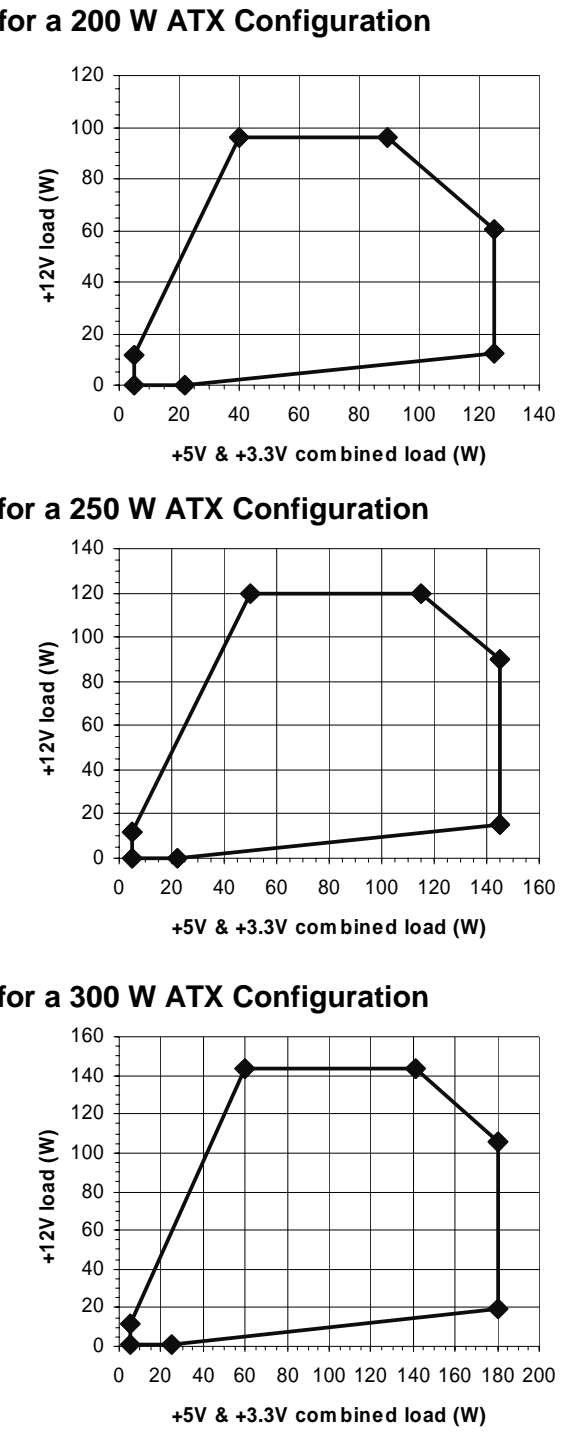
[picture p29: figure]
+5V & +3.3V com bined load (W); +12V load (W)

Table 5. Typical Power Distribution for a 200 W ATX Configuration

Output

Min.
Current
(amps)

Max.
Current
(amps)

Peak
Current
(amps)
+12 VDC | 0.0 | 8.0 | 10.0
+5 VDC | 1.0 | 21.0
+3.3 VDC | 0.3 | 14.0
-5 VDC | 0.0 | 0.3
-12 VDC | 0.0 | 0.8
+5 VSB | 0.0 | 1.5 | 2.5

See graph at right for power sharing.
Table 6. Typical Power Distribution for a 250 W ATX Configuration

Output

Min.
Current
(amps)

Max.
Current
(amps)

Peak
Current
(amps)
+12 VDC | 0.0 | 10.0 | 12.0
+5 VDC | 1.0 | 25.0
+3.3 VDC | 0.3 | 16.0
-5 VDC | 0.0 | 0.3
-12 VDC | 0.0 | 0.8
+5 VSB | 0.0 | 1.5 | 2.5

See graph at right for power sharing.
Table 7. Typical Power Distribution for a 300 W ATX Configuration

Output

Min.
Current
(amps)

Max.
Current
(amps)

Peak
Current
(amps)
+12 VDC | 0.0 | 12.0 | 14.0
+5 VDC | 1.0 | 30.0
+3.3 VDC | 0.3 | 20.0
-5 VDC | 0.0 | 0.3
-12 VDC | 0.0 | 0.8
+5 VSB | 0.0 | 1.5 | 2.5

See graph at right for power sharing.

### 3.2.3.2. ATX12V Configurations

ATX12V power supplies—with their additional 2x2 +12V & Aux power connectors—are intended for applications where the motherboard demand for current exceeds the ATX main power connector capability of ~6 A per contact. In general, the +12 V power connector should not be implemented on any power supply with a total +12 VDC continuous output capability of less than 10 A.

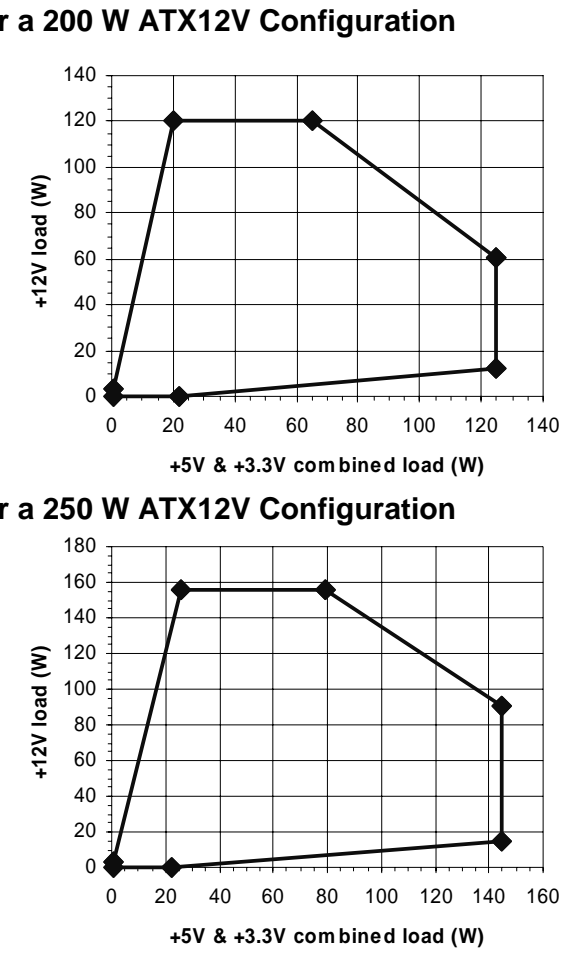
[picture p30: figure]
+5V & +3.3V com bined load (W); +12V load (W)

Table 8. Typical Power Distribution for a 200 W ATX12V Configuration

Output

Min.
Current
(amps)

Max.
Current
(amps)

Peak
Current
(amps)
+12 VDC | 0.0 | 10.0 | 12.0
+5 VDC | 0.1 | 21.0
+3.3 VDC | 0.3 | 14.0
-5 VDC | 0.0 | 0.3
-12 VDC | 0.0 | 0.8
+5 VSB | 0.0 | 1.5 | 2.5

See graph at right for power sharing.
Table 9. Typical Power Distribution for a 250 W ATX12V Configuration

Output

Min.
Current
(amps)

Max.
Current
(amps)

Peak
Current
(amps)
+12 VDC | 0.0 | 13.0 | 16.0
+5 VDC | 0.1 | 25.0
+3.3 VDC | 0.3 | 20.0
-5 VDC | 0.0 | 0.3
-12 VDC | 0.0 | 0.8
+5 VSB | 0.0 | 1.5 | 2.5

See graph at right for power sharing.

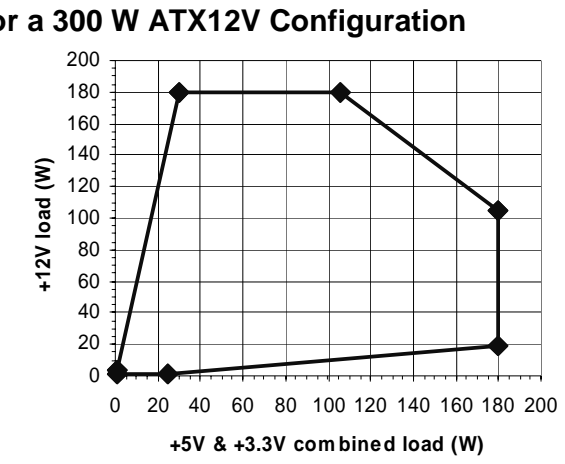
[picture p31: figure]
+5V & +3.3V com bined load (W); +12V load (W)

Table 10. Typical Power Distribution for a 300 W ATX12V Configuration

Output

Min.
Current
(amps)

Max.
Current
(amps)

Peak
Current
(amps)
+12 VDC | 0.0 | 15.0 | 18.0
+5 VDC | 0.1 | 30.0
+3.3 VDC | 0.3 | 28.0
-5 VDC | 0.0 | 0.3
-12 VDC | 0.0 | 0.8
+5 VSB | 0.0 | 2.0 | 2.5

See graph at right for power sharing.

### 3.2.4. Power Limit

Under short-circuit or overload conditions, no output shall exceed 240 VA under any conditions including single component fault conditions, per IEC 60950 requirements.

### 3.2.5. Efficiency

### 3.2.5.1. General

The power supply should be a minimum of 68% efficient under maximum rated load. The efficiency of the power supply should be met over the AC input range defined in Table 2, under the load conditions defined in Section 3.2.3, and under the temperature and operating conditions defined in Section 5.

### 3.2.5.2. Energy Star

The “Energy Star” efficiency requirements of the power supply depend on the intended system configuration. In the low-power Energy Star state, the AC input power is limited to 30 W or 15% of the rated maximum DC output power for the configuration, whichever is greater. For example, in a 160 W system configuration, the Energy Star input power limit is 160 W × 0.15 = 24 W ⇒ 30 W; for a 300 W configuration, 300 W × 0.15 = 45 W. While a minimum power supply efficiency of 56% is often recommended at Energy Star operating levels, compliance to the guideline will also depend on the system’s DC power consumption. In cases where the system Energy Star power consumption for each DC output is known, the system designer should provide this information to assist the power supply designer.

### 3.2.5.3. Blue Angel, RAL-UZ 78

The +5VSB standby supply efficiency should be a minimum of 50% at 500 mA output. Standby efficiency is measured with the main outputs off and with PS_ON# high. To meet Blue Angel requirements, the AC input power shall not exceed 5 W when the main outputs are in the “DC disabled” state with 500 mA load on +5VSB and a 230 VAC/50 Hz input.

### 3.2.6. Output Ripple/Noise

The output ripple/noise requirements listed in Table 11 should be met throughout the load ranges specified in Section 3.2.3 and under all input voltage conditions as specified in Section 3.1.
Ripple and noise are defined as periodic or random signals over a frequency band of 10 Hz to 20 MHz. Measurements shall be made with an oscilloscope with 20 MHz bandwidth. Outputs should be bypassed at the connector with a 0.1 µF ceramic disk capacitor and a 10 µF electrolytic capacitor to simulate system loading. See Figure 1.
Table 11. DC Output Noise/Ripple

Output

Max. Ripple & Noise
(mVpp)
+12 VDC | 120
+5 VDC | 50
+3.3 VDC | 50
-5 VDC | 100

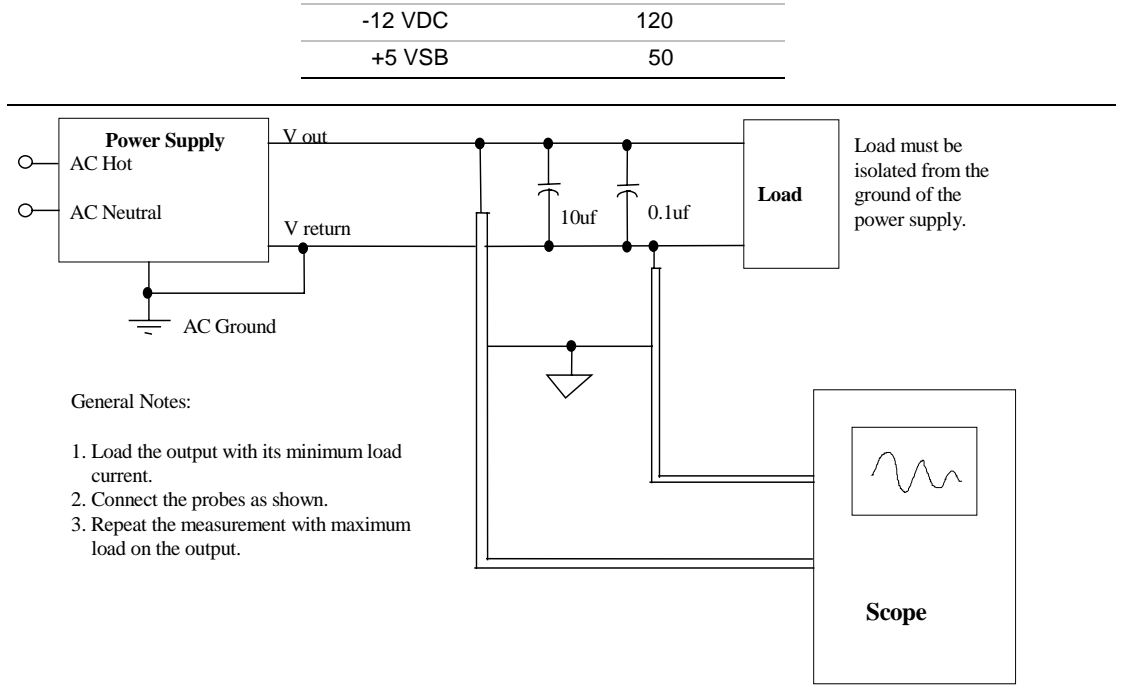
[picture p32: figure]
-12 VDC; +5 VSB; Scope; Load; V out; V return; Power Supply AC Hot; AC Neutral; AC Ground; General Notes:; current. 2. Connect the probes as shown. 3. Repeat the measurement with maximum load on the output.; Load must be isolated from the ground of the; power supply. 10uf

Scope Note:

Use Tektronix TDS460 Oscilloscope or equivalent and a P6046 probe or equivalent.

Filter Note:

0.1uf - Kemet, C1206C104K5RAC or equivalent 10uf - United Chemi-con, 293D106X0025D2T or equivalent

1. Load the output with its minimum load

Figure 1. Differential Noise Test Setup

### 3.2.7. Output Transient Response

Table 12 summarizes the expected output transient step sizes for each output. The transient load slew rate is = 1.0 A/µs.
Table 12. DC Output Transient Step Sizes

Output

Max. step size
(% of rated output amps per Sec 3.2.3) ⁽¹⁾

Max. step size
(amps)
+12 VDC | 50%
+5 VDC | 30%
+3.3 VDC | 30%
-5 VDC | 0.1 A
-12 VDC | 0.1 A
+5 VSB | 0.1 A
(1) For example, for a rated +5 VDC output of 18 A, the transient step would be 30% × 18 A = 5.4 A
Output voltages should remain within the regulation limits of Section 3.2.1, and the power supply should be stable when subjected to load transients per Table 12 from any steady state load, including any or all of the following conditions:
- Simultaneous load steps on the +12 VDC, +5 VDC, and +3.3 VDC outputs
(all steps occurring in the same direction)
- Load-changing repetition rate of 50 Hz to 10 kHz
- AC input range per Section 3.1
- Capacitive loading per Table 13

### 3.2.8. Capacitive Load

The power supply should be able to power up and operate normally with the following capacitances simultaneously present on the DC outputs.
Table 13. Output Capacitive Loads
Output | ATX Capacitive load (µF) | ATX12V Capacitive load (µF)
+12 VDC | 1,000 | 20,000
+5 VDC | 10,000 | 10,000
+3.3 VDC | 6,000 | 6,000
-5 VDC | 350 | 350
-12 VDC | 350 | 350
+5 VSB | 350 | 350

### 3.2.9. Closed-loop Stability

The power supply shall be unconditionally stable under all line/load/transient load conditions including capacitive loads specified in Section 3.2.8. A minimum of 45 degrees phase margin and 10 dB gain margin is recommended at both the maximum and minimum loads.

### 3.2.10. +5 VDC / +3.3 VDC Power Sequencing

The +12 VDC and +5 VDC output levels must be equal to or greater than the +3.3 VDC output at all times during power-up and normal operation. The time between the +12 VDC or +5 VDC output reaching its minimum in-regulation level and +3.3 VDC reaching its minimum in-regulation level must be ≤ 20 ms.

### 3.2.11. Voltage Hold-up Time

The power supply should maintain output regulation per Section 3.2.1 despite a loss of input power at the low-end nominal range—115 VAC / 57 Hz or 230 VAC / 47 Hz—at maximum continuous output load as applicable for a minimum of 17 ms.

## 3.3. Timing / Housekeeping / Control

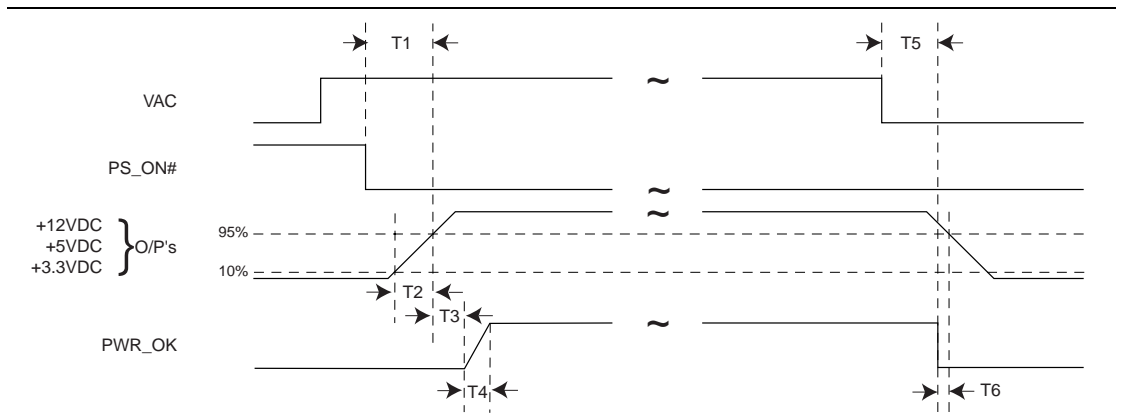
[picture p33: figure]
PWR_OK; +12VDC +5VDC; +3.3VDC }O/P's; VAC

PWR_OK Sense Level = 95% of nominal timing_3_5_12b
Figure 2. Power Supply Timing

Notes: T1 is defined in Section 3.3.4. T2 is defined in Section 3.3.5. T3, T4, T5, and T6 are defined in Table 14

### 3.3.1. PWR_OK

PWR_OK is a “power good” signal. It should be asserted high by the power supply to indicate that the +12 VDC, +5VDC, and +3.3VDC outputs are above the undervoltage thresholds listed in Section 3.2.1 and that sufficient mains energy is stored by the converter to guarantee continuous power operation within specification for at least the duration specified in Section 3.2.11, “Voltage Hold-up Time.” Conversely, PWR_OK should be deasserted to a low state when any of the +12 VDC, +5 VDC, or +3.3 VDC output voltages falls below its undervoltage threshold, or when mains power has been removed for a time sufficiently long such that power supply operation cannot be guaranteed beyond the power-down warning time. The electrical and timing characteristics of the PWR_OK signal are given in Table 14 and in Figure 2.

Table 14. PWR_OK Signal Characteristics

Signal Type | +5 V TTL compatible
Logic level low | < 0.4 V while sinking 4 mA
Logic level high | Between 2.4 V and 5 V output while sourcing 200 µA
High-state output impedance | 1 kΩ from output to common
PWR_OK delay | 100 ms < T3 < 500 ms
PWR_OK risetime | T4 ≤ 10 ms
AC loss to PWR_OK hold-up time T5 ≥ 16 ms
Power-down warning | T6 ≥ 1 ms

### 3.3.2. PS_ON#

PS_ON# is an active-low, TTL-compatible signal that allows a motherboard to remotely control the power supply in conjunction with features such as soft on/off, Wake on LAN†, or wake-on-modem. When PS_ON# is pulled to TTL low, the power supply should turn on the five main DC output rails: +12VDC, +5VDC, +3.3VDC, -5VDC, and -12VDC. When PS_ON# is pulled to TTL high or open-circuited, the DC output rails should not deliver current and should be held at zero potential with respect to ground. PS_ON# has no effect on the +5VSB output, which is always enabled whenever the AC power is present. Table 15 lists PS_ON# signal characteristics.
The power supply shall provide an internal pull-up to TTL high. The power supply shall also provide debounce circuitry on PS_ON# to prevent it from oscillating on/off at startup when activated by a mechanical switch. The DC output enable circuitry must be SELV-compliant.
Table 15. PS_ON# Signal Characteristics
| Min. | Max.
VIL, Input Low Voltage | 0.0 V | 0.8 V
IIL, Input Low Current (Vin = 0.4 V) | | -1.6 mA
VIH, Input High Voltage (Iin = -200 µA) | 2.0 V
VIH open circuit, Iin = 0 | | 5.25 V

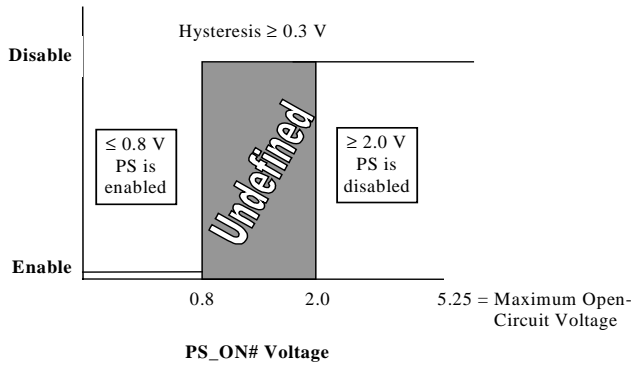
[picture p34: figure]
Enable; Disable; PS_ON# Voltage; 5.25 = Maximum Open-; Circuit Voltage; ≥ 2.0 V PS is disabled; ≤ 0.8 V PS is enabled; Hysteresis ≥ 0.3 V

Figure 3. PS_ON# Signal Characteristics

### 3.3.3. +5 VSB

+5 VSB is a standby supply output that is active whenever the AC power is present. It provides a power source for circuits that must remain operational when the five main DC output rails are in a disabled state. Example uses include soft power control, Wake on LAN, wake-on-modem, intrusion detection, or suspend state activities.
The +5 VSB output should be capable of delivering a minimum of 1.0 A at +5 V ± 5% to external circuits. Because trends indicate a growing demand for standby power, it is recommended that designs be scalable to 2.0 A to meet future needs. The power supply must be able to provide the required power during a "wake up" event. If an external USB device generates the event, there may be peak currents as high as 2.5A lasting no more than 500mS.
Overcurrent protection is required on the +5 VSB output regardless of the output current rating. This ensures the power supply will not be damaged if external circuits draw more current than the supply can provide.

### 3.3.4. Power-on Time

The power-on time is defined as the time from when PS_ON# is pulled low to when the +12 VDC, +5 VDC, and +3.3 VDC outputs are within the regulation ranges specified in Section 3.2.1. The power-on time shall be less than 500 ms (T1 < 500 ms).
+5 VSB shall have a power-on time of two seconds maximum after application of valid AC voltages.

### 3.3.5. Risetime

The output voltages shall rise from ≤10% of nominal to within the regulation ranges specified in Section 3.2.1 within 0.1 ms to 20 ms (0.1 ms ≤ T2 ≤ 20 ms).
There must be a smooth and continuous ramp of each DC output voltage from 10% to 90% of its final set-point within the regulation band, while loaded as specified in Section 3.2.3.

The smooth turn-on requires that, during the 10% to 90% portion of the rise time, the slope of the turn-on waveform must be positive and have a value of between 0 V/ms and [Vout,nominal / 0.1] V/ms. Also, for any 5 ms segment of the 10% to 90% risetime waveform, a straight line drawn between the end points of the waveform segment must have a slope ≥ [Vout,nominal / 20] V/ms.

### 3.3.6. Overshoot at Turn-on / Turn-off

The output voltage overshoot upon the application or removal of the input voltage, or the assertion/deassertion of PS_ON#, under the conditions specified in Section 3.1, shall be less than 10% above the nominal voltage. No voltage of opposite polarity shall be present on any output during turn-on or turn-off.

### 3.3.7. Reset after Shutdown

If the power supply latches into a shutdown state because of a fault condition on its outputs, the power supply shall return to normal operation only after the fault has been removed and the PS_ON# (or AC input) has been cycled OFF/ON with a minimum OFF time of
1 second.

### 3.3.8. +5 VSB at AC Power-down

After AC power is removed, the +5 VSB standby voltage output should remain at its steady state value for the minimum hold-up time specified in Section 3.2.11 until the output begins to decrease in voltage. The decrease shall be monotonic in nature, dropping to
0.0 V. There shall be no other perturbations of this voltage at or following removal of AC power.

## 3.4. Output Protection

### 3.4.1. Overvoltage Protection

The overvoltage sense circuitry and reference shall reside in packages that are separate and distinct from the regulator control circuitry and reference. No single point fault shall be able to cause a sustained overvoltage condition on any or all outputs. The supply shall provide latch-mode overvoltage protection as defined in Table 16.
Table 16. Overvoltage Protection
Output | Min. | Nom. | Max. | Unit
+12 VDC | 13.4 | 15.0 | 15.6 | Volts
+5 VDC | 5.74 | 6.3 | 7.0 | Volts
+3.3 VDC | 3.76 | 4.2 | 4.3 | Volts

### 3.4.2. Short-circuit Protection

An output short circuit is defined as any output impedance of less than 0.1 ohms. The power supply shall shut down and latch off for shorting the +3.3 VDC, +5 VDC, or
+12 VDC rails to return or any other rail. Shorts between main output rails and +5 VSB shall not cause any damage to the power supply. The power supply shall either shut down and latch off or fold back for shorting the negative rails. +5 VSB must be capable of being shorted indefinitely, but when the short is removed, the power supply shall recover automatically or by cycling PS_ON#. The power supply shall be capable of withstanding a continuous short-circuit to the output without damage or overstress to the unit (for example, to components, PCB traces, connectors) under the input conditions specified in Section 3.1. The maximum short-circuit energy in any output shall not exceed 240 VA, per IEC 60950 requirements.

### 3.4.3. No-load Operation

No damage or hazardous condition should occur with all the DC output connectors disconnected from the load. The power supply may latch into the shutdown state.

### 3.4.4. Overcurrent Protection

Overload currents applied to each tested output rail will cause the output to trip before reaching or exceeding 240 VA. For testing purposes, the overload currents should be ramped at a minimum rate of 10 A/s starting from full load.

### 3.4.5. Overtemperature Protection

The power supply may include an overtemperature protection sensor, which can trip and shut down the power supply at a preset temperature point. Such an overheated condition is typically the result of internal current overloading or a cooling fan failure. If the protection circuit is nonlatching, then it should have hysteresis built in to avoid intermittent tripping.

### 3.4.6. Output Bypass

The output return may be connected to the power supply chassis. The return will be connected to the system chassis by the system components.

# 4. Mechanical

## 4.1. Labeling / Marking

The following is a noninclusive list of suggested markings for each power supply unit. Product regulation stipulations for sale into various geographies may impose additional labeling requirements.
- Manufacturer information: manufacturer’s name, part number, and lot date code, etc., in human-readable text and/or bar code formats
- Nominal AC input operating voltages (100-127 VAC and 200-240 VAC) and current rating certified by all applicable safety agencies (Section 8)
- DC output voltages and current ratings
- Access warning text (“Do not remove this cover. Trained service personnel only. No user serviceable components inside.”) in English, German, Spanish, French, Chinese, and Japanese with universal warning markings

## 4.2. Physical Dimensions

The supply shall be enclosed and meet the physical outline shown in either Figure 4 or 5, as applicable.

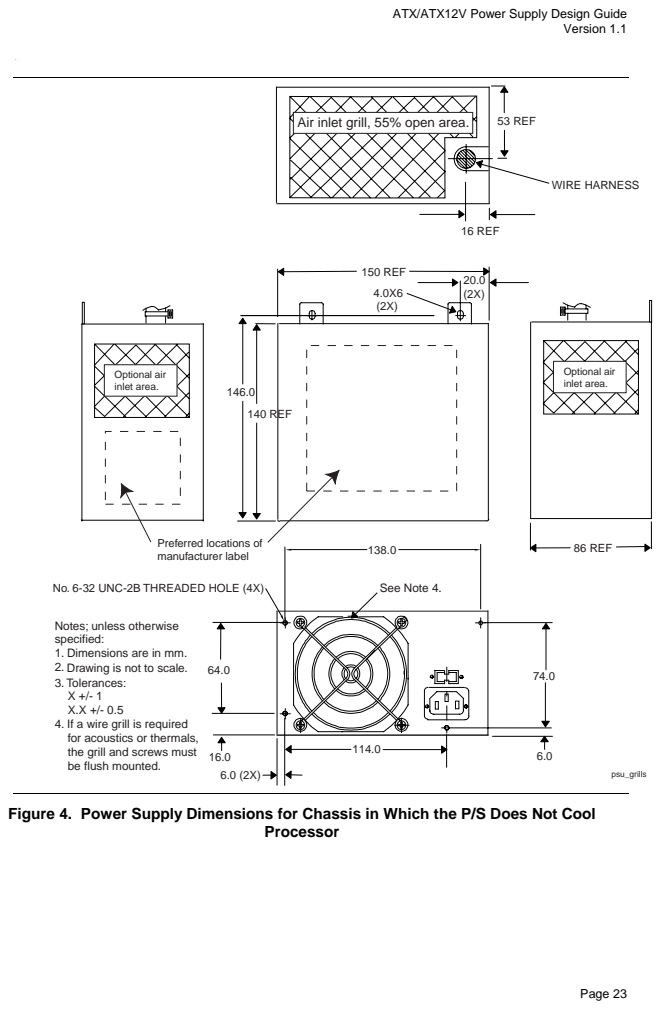
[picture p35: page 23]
Optional air inlet area.; 53 REF; WIRE HARNESS; 16 REF; 150 REF; 140 REF; 86 REF; See Note 4.; psu_grills; Processor

Air inlet grill, 55% open area.

Preferred locations of
manufacturer label

No. 6-32 UNC-2B THREADED HOLE (4X)

Notes; unless otherwise
specified:
1. Dimensions are in mm.
2. Drawing is not to scale.
3. Tolerances:
4. If a wire grill is required
for acoustics or thermals,
the grill and screws must
be flush mounted.

Figure 4. Power Supply Dimensions for Chassis in Which the P/S Does Not Cool

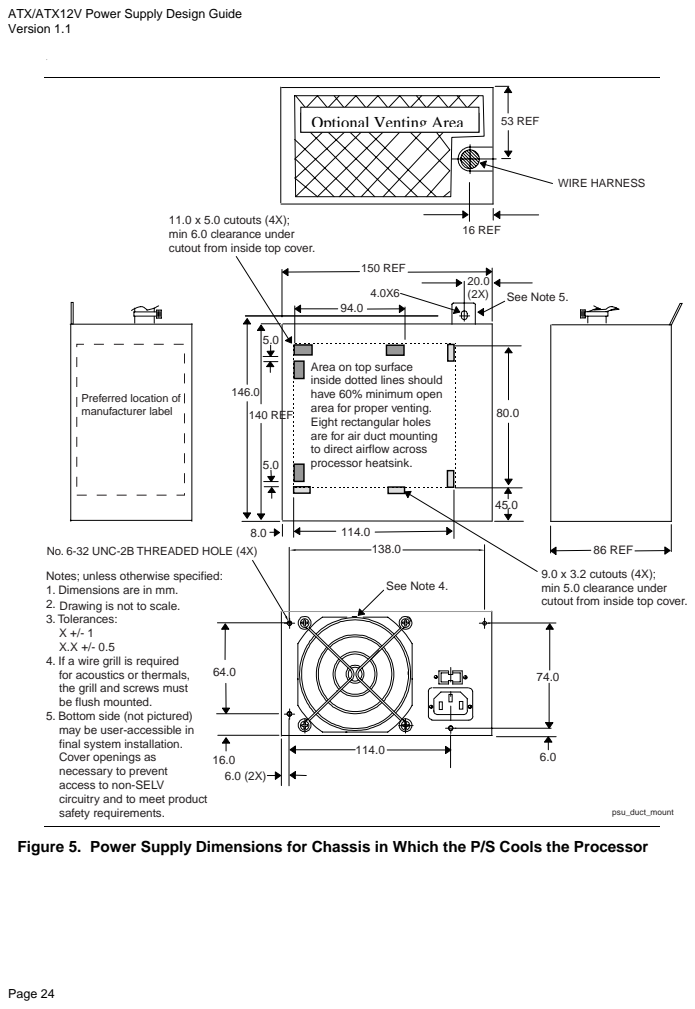
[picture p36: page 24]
53 REF; WIRE HARNESS; 16 REF; 150 REF; See Note 5.; 140 REF; 86 REF; See Note 4.; psu_duct_mount

Optional Venting Area

11.0 x 5.0 cutouts (4X);
min 6.0 clearance under
cutout from inside top cover.

Area on top surface
inside dotted lines should
have 60% minimum open
area for proper venting.
Eight rectangular holes
are for air duct mounting
to direct airflow across
processor heatsink.

Preferred location of
manufacturer label

No. 6-32 UNC-2B THREADED HOLE (4X)
Notes; unless otherwise specified:
1. Dimensions are in mm.
2. Drawing is not to scale.
3. Tolerances:
4. If a wire grill is required
for acoustics or thermals,
the grill and screws must
be flush mounted.
5. Bottom side (not pictured)
may be user-accessible in
final system installation.
Cover openings as
necessary to prevent
access to non-SELV
circuitry and to meet product
safety requirements.
Figure 5. Power Supply Dimensions for Chassis in Which the P/S Cools the Processor

9.0 x 3.2 cutouts (4X);
min 5.0 clearance under

## 4.3. Airflow / Fan

The ATX Specification allows for numerous (and often confusing) possibilities for power supply fan location, direction, speed, and venting. The designer’s choice of a power supply cooling solution depends in part on the targeted end-use system application(s). At a minimum, the power supply design must ensure its own reliable and safe operation.
Fan location/direction. In general, exhausting air from the system chassis enclosure via a power supply fan at the rear panel is the preferred, most common, and most widely applicable system-level airflow solution. Other solutions are permitted, however, and some system/chassis designers may choose to use other solutions to meet specific system cooling requirements.
Fan size/speed. An 80 mm or larger axial fan is typically needed to provide enough cooling airflow through an average ATX system. Exact CFM requirements vary by application and end-use environment, but 25-35 CFM is typical for the fan itself.
For consumer or other noise-sensitive applications, it is recommended that a thermally sensitive fan speed control circuit be used to balance system-level thermal and acoustic performance. The circuit typically senses the temperature of the secondary heatsink and/or incoming ambient air and adjusts the fan speed as necessary to keep power supply and system component temperatures within specification. Both the power supply and system designers should be aware of the dependencies of the power supply and system temperatures on the control circuit response curve and fan size and should specify them very carefully.
The power supply fan should be turned off when PS_ON# is deasserted (high). In this state, any remaining active power supply circuitry must rely only on passive convection for cooling.
Venting. In general, more venting in a power supply case yields reduced airflow impedance and improved cooling performance. Intake and exhaust vents should be as large, open, and unobstructed as possible so as not to impede airflow or generate excessive acoustic noise. In particular, avoid placing objects within 0.5 inches of the intake or exhaust of the fan itself. A flush-mount wire fan grill can be used instead of a stamped metal vent for improved airflow and reduced acoustic noise.
There are three caveats to the venting guidelines above:
- Openings must be sufficiently designed to meet the safety requirements described in Section 8.
- Larger openings yield decreased EMI-shielding performance (see Section 6).
- Venting in inappropriate locations can detrimentally allow airflow to bypass those areas where it is needed.

The ATX Specification offers two options for venting between the power supply and the system interior:
- The venting shown in Figure 4 provides the most effective channeled airflow for the power supply itself, with little regard for directly cooling any system components. This venting method is nearly always used in conjunction with a fan that exhausts out the rear of the power supply.
- The venting shown in Figure 5 allows designers to more directly couple the power supply airflow to system components such as the processor or motherboard core, potentially cooling all critical components with a single fan. Both the power supply fan location and direction may vary in this case. The trade-off is usually one of reduced system cost versus narrower design applicability.

## 4.4. AC Connector

The AC input receptacle should be an IEC 320 type or equivalent. In lieu of a dedicated switch, the IEC 320 receptacle may be considered the mains disconnect.

## 4.5. DC Connectors

Figure 6 shows pinouts and profiles for typical ATX power supply DC harness connectors. Listed or recognized component appliance wiring material (AVLV2), CN, rated min 85 °C, 300 VDC shall be used for all output wiring.
There are no specific requirements for output wire harness lengths, as these are largely a function of the intended end-use chassis, motherboard, and peripherals. Ideally, wires should be short to minimize electrical/airflow impedance and simplify manufacturing, yet they should be long enough to make all necessary connections without any wire tension (which can cause disconnections during shipping and handling). Recommended minimum harness lengths for general-use power supplies are 280 mm for the +12 V power connector and 250 mm for all other wire harnesses. Measurements are made from the exit port of the power supply case to the wire side of the first connector on the harness.

NOTE
Details of the 2x3 “Optional Power Connector” mentioned in the ATX 2.03 Specification are omitted from this design guide until such time as the signals on that connector are more rigidly defined.

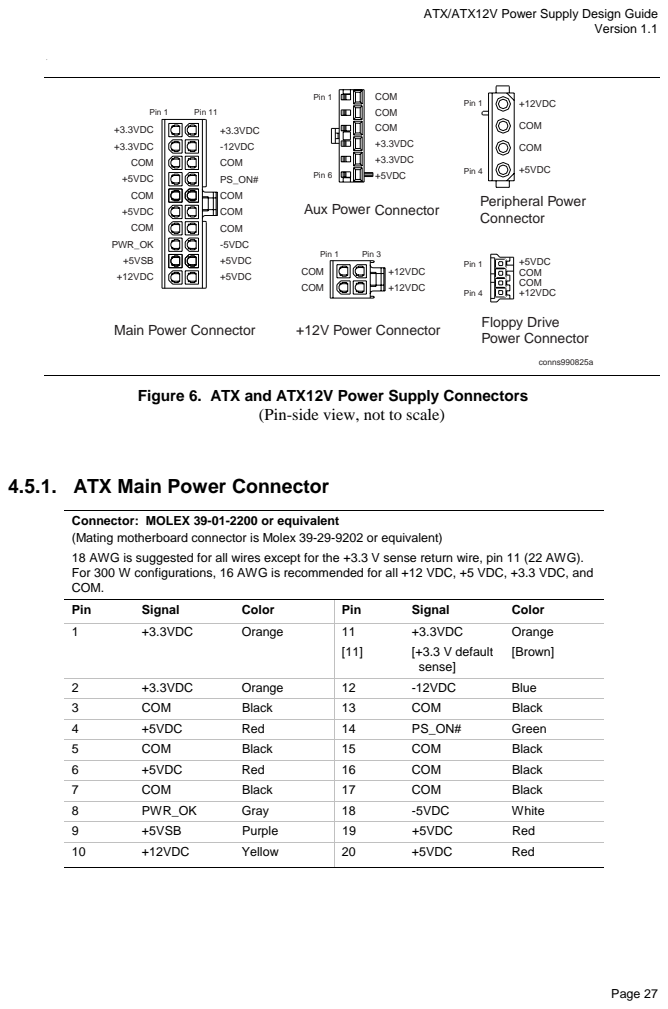
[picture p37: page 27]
+3.3VDC; COM +5VDC COM +5VDC COM PWR_OK +5VSB +12VDC; +3.3VDC -12VDC COM PS_ON# COM COM COM -5VDC +5VDC +5VDC; Pin 1; Pin 11; COM COM COM +3.3VDC +3.3VDC; Pin 6; +5VDC; +12VDC; COM; Peripheral Power Connector; Floppy Drive Power Connector; +5VDC COM COM +12VDC; Pin 4; conns990825a; +12V Power Connector; Pin 3; Pin; Signal; Color; Orange; +3.3VDC [+3.3 V default sense]; Orange [Brown]; -12VDC; Blue; Black; Red; Green; PWR_OK; Gray; -5VDC; White; +5VSB; Purple; Yellow

Aux Power Connector

Main Power Connector

Figure 6. ATX and ATX12V Power Supply Connectors

(Pin-side view, not to scale)

4.5.1. ATX Main Power Connector

Connector: MOLEX 39-01-2200 or equivalent
(Mating motherboard connector is Molex 39-29-9202 or equivalent)
18 AWG is suggested for all wires except for the +3.3 V sense return wire, pin 11 (22 AWG).
For 300 W configurations, 16 AWG is recommended for all +12 VDC, +5 VDC, +3.3 VDC, and
COM.

### 4.5.2. +12 V Power Connector (for ATX12V Configurations Only)

Connector: MOLEX 39-01-2040 or equivalent
(Mating motherboard connector is Molex 39-29-9042 or equivalent)
Pin | Signal | 20 AWG Wire | Pin | Signal | 20 AWG Wire
1 | COM | Black | 3 | +12VDC | Yellow
2 | COM | Black | 4 | +12VDC | Yellow

### 4.5.3. Auxiliary Power Connector for Configurations with +3.3 VDC Output > 18 A or +5 V Output > 24 A

Connector: MOLEX 90331-0010 (keyed pin
6) or equivalent
Pin | Signal | 16 AWG Wire
1 | COM | Black
2 | COM | Black
3 | COM | Black
4 | +3.3VDC | Orange
5 | +3.3VDC | Orange
6 | +5VDC | Red

### 4.5.4. Peripheral Connector(s)

Connector: AMP 1-480424-0 or MOLEX 8981-04P or equivalent.
Contacts: AMP 61314-1 or equivalent.
Pin | Signal | 18 AWG Wire
1 | +12VDC | Yellow
2 | COM | Black
3 | COM | Black
4 | +5VDC | Red

### 4.5.5. Floppy Drive Connector

Connector: AMP 171822-4 or equivalent
Pin | Signal | 20 AWG Wire
1 | +5VDC | Red
2 | COM | Black
3 | COM | Black
4 | +12VDC | Yellow

# 5. Environmental

The following subsections define recommended environmental specifications and test parameters, based on the typical conditions to which an ATX and ATX12V power supply may be subjected during operation or shipment.

## 5.1. Temperature

Operating ambient | +10 °C to +50 °C
| (At full load, with a maximum temperature rate of change of 5 °C/10 minutes, but no more than 10 °C/hr.)
Nonoperating ambient | -40 °C to +70 °C
| (Maximum temperature rate of change of 20 °C/hr.)

## 5.2. Thermal Shock (Shipping)

Nonoperating | -40 °C to +70 °C 15 °C/min ≤ dT/dt ≤ 30 °C/min Tested for 50 cycles; Duration of exposure to temperature extremes for each half cycle shall be 30 minutes.

## 5.3. Humidity

Operating | To 85% relative humidity (noncondensing)
Nonoperating | To 95% relative humidity (noncondensing)
| Note: 95% RH is achieved with a dry bulb temperature of 55 °C and a wet bulb temperature of 54 °C.

## 5.4. Altitude

Operating | To 10,000 ft
Nonoperating | To 50,000 ft

## 5.5. Mechanical Shock

Nonoperating | 50 g, trapezoidal input; velocity change ≥ 170 in/s
| Three drops on each of six faces are applied to each sample.

## 5.6. Random Vibration

Nonoperating | 0.01 g²/Hz at 5 Hz, sloping to 0.02 g²/Hz at 20 Hz, and maintaining 0.02 g²/Hz from 20 Hz to 500 Hz. The area under the PSD curve is 3.13 gRMS. The duration shall be 10 minutes per axis for all three axes on all samples.

## 5.7. Acoustics

Acoustic requirements will be set by the final computer OEM system-level requirements.

# 6. Electromagnetic Compatibility

The following subsections outline sample product regulations requirements for a typical power supply. Actual requirements will depend on the design, product end use, target geography, and other variables. Consult your company’s Product Safety and Regulations department for more details.

## 6.1. EMI

The power supply shall comply with CISPR 22, Class B, for both conducted and radiated emissions with a 4 dB margin. Tests shall be conducted using a shielded DC output cable to a shielded load. The load shall be adjusted as follows for three tests: No load on each output; 50% load on each output; and 100% load on each output. Tests will be performed at 100 VAC 50 Hz, 120 VAC 60 Hz, and 220 VAC 50 Hz power.

## 6.2. Input Line Current Harmonic Content and Line Flicker Required for Sales in Europe and Japan

For sales in Japan or Europe, the power supply shall meet the requirements of EN 61000-3-2 Class D, and EN 61000-3-3, and the Guidelines for the Suppression of Harmonics in Appliances and General Use Equipment Class D for harmonic line current content at full-rated power.

## 6.3. Magnetic Leakage Fields

A PFC choke magnetic leakage field should not cause any interference with a high-resolution computer monitor placed next to or on top of the end-use chassis.

# 7. Reliability

## 7.1. Component Derating

The following component derating guidelines are recommended:
- Semiconductor junction temperatures shall not exceed 110 °C with an ambient of 50 °C.
- Inductor case temperature shall not exceed safety agency requirements.
- Capacitor case temperature shall not exceed 95% of rated temperature.
- Component voltage and current derating shall be > 10% at 50 °C.
- Magnetic saturation of any transformer will not be allowed under any line, load, startup, or transient condition including 100% transients on the five main outputs or +5 VSB.

## 7.2. Mean Time Between Failures (MTBF)

The MTBF of the power supply can be calculated with the Part-Stress Analysis method of MIL-HDBK-217F using the quality factors listed in MIL-HDBK-217F. A target calculated MTBF of the power supply is greater than 100,000 hours under the following conditions:
- Full-rated load
- 120 VAC input
- Ground benign
- 25 °C ambient
A target calculated MTBF of the power supply is greater than 30,000 hours under the following conditions:
- Full-rated load
- 120 VAC input
- Ground benign
- 50 °C ambient

# 8. Safety

The following subsections outline sample product regulations requirements for a typical power supply. Actual requirements will depend on the design, product end use, target geography, and other variables. Consult your company’s Product Safety and Regulations department for more details.

## 8.1. North America

The power supply must be certified by an NRTL (Nationally Recognized Testing Laboratory) for use in the USA and Canada under the following conditions:
- The supply must be Recognized for use in Information Technology Equipment including Electrical Business Equipment per UL 1950 / CAN/CSA C22.2 No. 950-95, 3rd edition, without D3 deviations. The certification must include external enclosure testing for the AC receptacle side of the power supply (see Figures 4 and 5).
- The supply must have a full complement of tests conducted as part of the certification, such as input current, leakage current, hi-pot, temperature, energy discharge test, transformer output characterization test (open-circuit voltage, short-circuit current, and maximum VA output), and abnormal testing (to include stalled-fan tests and voltage-select–switch mismatch).
- The enclosure must meet fire enclosure mechanical test requirements per clauses 2.9.1 and 4.2 of the above-mentioned standard.
Production hi-pot testing must be included as a part of the certification and indicated as such in the certification report.
There must not be unusual or difficult conditions of acceptability such as mandatory additional cooling or power derating. The insulation system shall not have temperatures exceeding their rating when tested in the end product.
The certification mark shall be marked on each power supply.
The power supply must be evaluated for operator-accessible secondary outputs (reinforced insulation) that meet the requirements for SELV and do not exceed 240 VA under any condition of loading.
The proper polarity between the AC input receptacle and any printed wiring boards connections must be maintained (that is, brown=line, blue=neutral, green=earth/chassis). Failure of any single component in the fan-speed control circuit shall not cause the internal component temperatures to exceed the abnormal fault condition temperatures per IEC 60950.

## 8.2. International

The vendor must provide a complete CB certificate and test report to IEC 950, 2nd edition + A1, A2, A3, and A4. The CB report must include ALL CB member country national deviations. CB report must include evaluation to EN60 950, + A1, A2, A3, A4 and EMKO-TSE (74-SEC) 207/94.
All evaluations and certifications must be for reinforced insulation between primary and secondary circuits.

## 8.3. Proscribed Materials

Cadmium should not be used in painting or plating.
No quaternary salt electrolytic capacitors shall be used.
Mercury shall not be used.
The use of CFCs or HFCs shall not be used in the design or manufacturing process.

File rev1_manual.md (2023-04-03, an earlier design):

# ATX4VC: ATX Power on Retro Computers!

[Buy ATX4VC](https://www.tindie.com/products/dekuNukem/atx4vc-atx-power-on-retro-computers/) | [Discord](https://discord.gg/T9uuFudg7j) | [User Manual](#user-manual) | [Table of Contents](#Table-of-Contents)

ATX4VC lets you **use ATX power supply on vintage computers**.

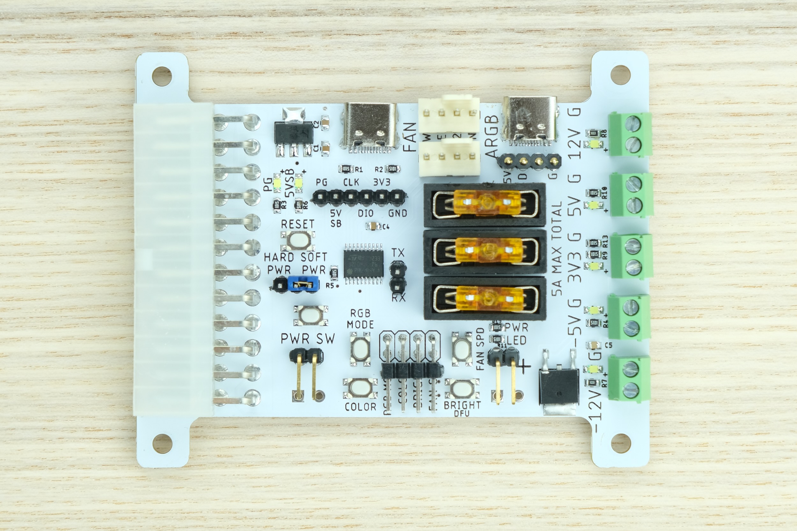
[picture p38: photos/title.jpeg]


It has:

* All common voltages: +12V, +5V, +3.3V, -5V, -12V.

* Power button and LED headers

* PC fan headers with PWM and temp probe support

* Addressable RGB (ARGB) header

* USB-C power output

ATX4VC can be used to:

* Replace retro computer PSUs

* Add cooling and lighting upgrades

* Test and diagnose vintage hardware

* As general-purpose multi-voltage bench PSU

## Get ATX4VC

[Click me to get one on Tindie!](https://www.tindie.com/products/dekuNukem/atx4vc-atx-power-on-retro-computers/)

## PicoRC

Also [Check out PicoRC](https://github.com/dekuNukem/PicoRC) for **device-specific** and **lower-cost** PicoPSU adaptors.

Available for Apple II, Macintosh 128K/Plus, Macintosh SE SE/30, and more.

## Showcase

**Pico ATX PSU** is a perfect match due to its compact size. 

Here it replaces the failed PSU in my Osborne 1, providing +12 and +5V.

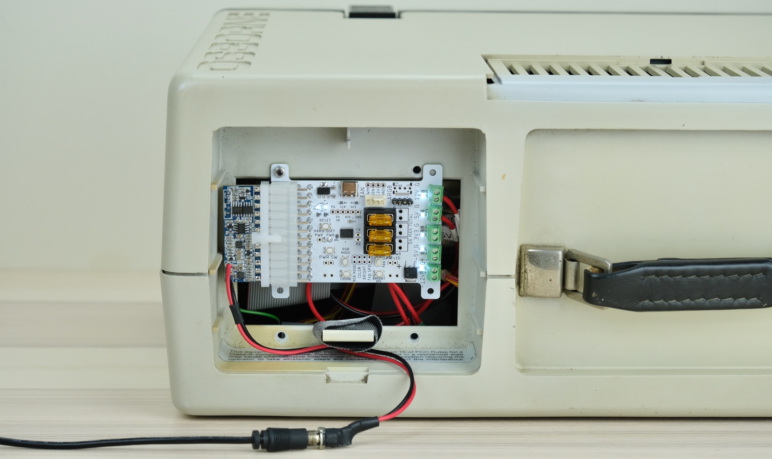
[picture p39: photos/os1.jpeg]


It also works as a multi-voltage bench PSU for testing and diagnostics.

Here it powers a Macintosh Plus motherboard with +12, +5, and -12V.



## Why / Project Goals

Power supplies are a major failure point of old computers today. Those early PSUs are heavy, inefficient, hot, and (slightly) explosive! After 40 odd years, many are not working, or worse might cause damage with out-of-spec voltages.

ATX4VC is designed to replace them with much more reliable modern ATX PSUs, and help test and diagnose vintage computers.

## Table of Contents

[Quick Start Guide](#Quick-Start)

[Power Button and Power LED](#Power-Button-and-Power-LED)

[Power Connection](#Power-Connection)

[Current Limit](#Current-Limit)

[Fuses](#Fuses)

[Fan Headers](#Fan-Headers)

[Temperature Probe](#Temperature-Probe)

[Addressable RGB (ARGB)](#Addressable-RGB-ARGB)

[USB-C Power Output](#USB-C-Power-Output)

[Dimension Drawings](#Dimension-Drawings)

[Hard Power](#Hard-Power)

[RGBA over USB](#RGBA-over-USB)

[Additional Headers](#Additional-Headers)

[USB Firmware Update](#USB-Firmware-Update)

## User Manual

### Get a Pico PSU

ATX4VC works with **any standard ATX PSU**, but a PicoPSU is recommended due to its compact size.



* [Official website](https://www.mini-box.com/DC-DC) and [distributors](https://www.mini-box.com/site/resellers.html). Even the cheapest 80W one should be plenty.

* You can also find generic ones on eBay/Amazon/Aliexpress by searching `Pico ATX`. They are *not that* cheap, so I strongly suggest supporting the high-quality official products.

* A power brick with **12V DC** and **center positive** 5.5x2.5mm barrel jack is needed.

* They are very popular and you might already have one. Make sure it has enough wattage.

Remember that this solution is **only as good as your PicoPSU and 12V Brick**, so don't skimp on them!

### Quick Start

* Make sure the jumper is in "soft power" setting (right 2 pins), or no jumper at all.

* Plug in ATX connector

* Press the power button

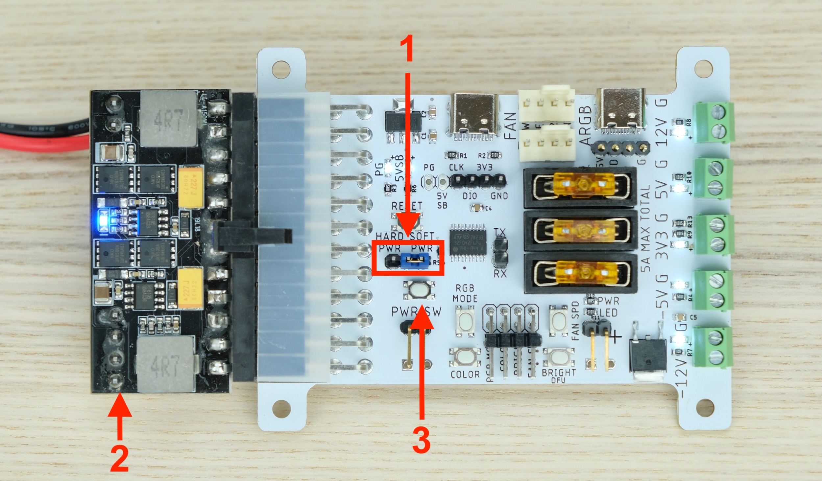
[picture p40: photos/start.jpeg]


The PSU should turn on, all voltage rail LEDs should light up. 

That's the gist of it! But **please do keep reading** for the complete info.

### Power Button and Power LED

You can use the built-in power button, or connect an external button to the header.

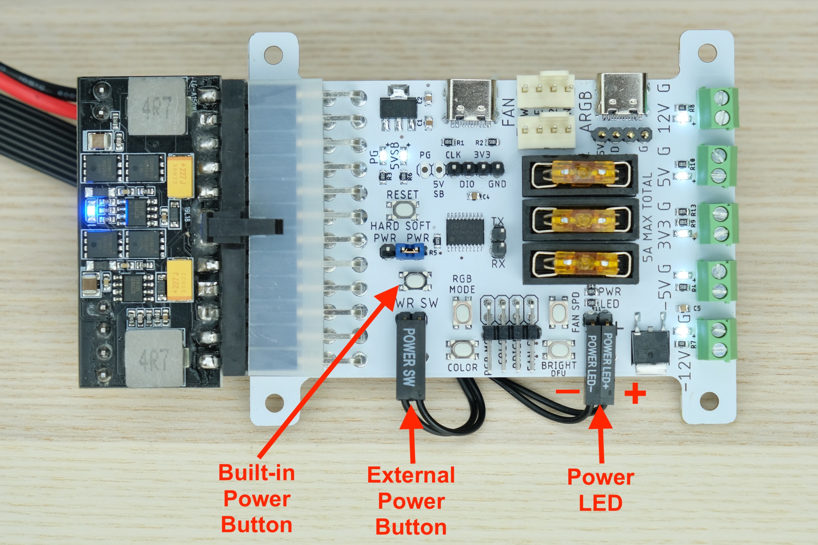
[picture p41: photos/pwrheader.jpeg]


You can also add an external power LED. Be ware of polarity. **No need for external resistors**. A 2.5K resistor is built-in.

### Power Connection

Observe the voltage on each terminal block.

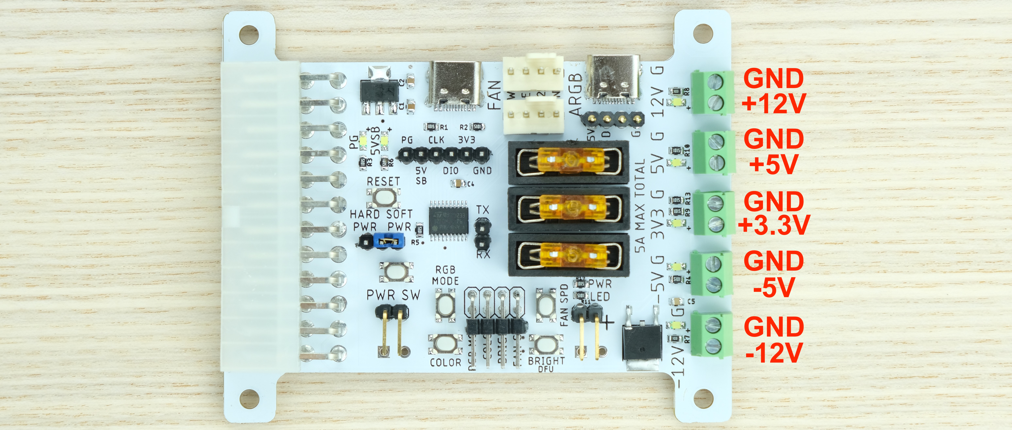
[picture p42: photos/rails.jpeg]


* Strip the insulation

* Loosen screw

* Insert into hole

* **Hold the terminal block steady** while tightening it back up

* Don't leave conductor exposed to prevent shorts.

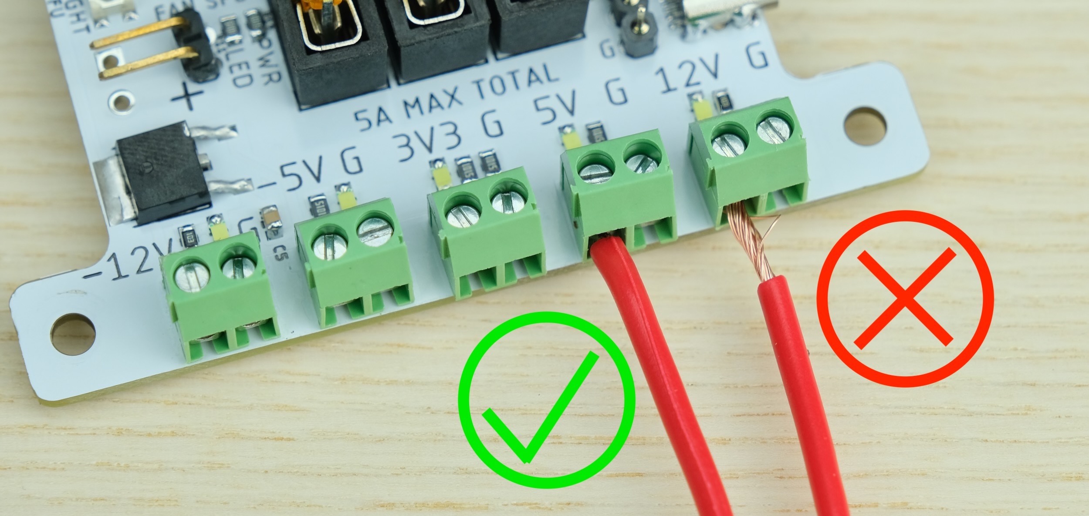
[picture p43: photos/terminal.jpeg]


Also, make sure the conductor is thick enough!



Label the rails, vinyl stickers are available in the [product page](https://www.tindie.com/products/dekuNukem/atx4vc-atx-power-on-retro-computers/):



### Pre-flight Checks

Before powering up:

* Double check the **correct voltage terminal** is used

* Check for **dead shorts** between each voltage rail and GND, and between themselves!

Once powered up:

* Check voltage readings on each rail

Remember that ATX4VC **DOES NOT** monitor or condition PSU voltage outputs, so make sure the PSU itself is of good quality and trustworthy!

### Current Limit

* **`5 AMPS MAX`** OVER **ANY SINGLE RAIL**

* **`7 AMPS MAX`** **TOTAL CURRENT** OVER ALL RAILS

If more is needed, **tap the power directly** from a Molex connector.

See your PSU label or datasheet to see how much current it can provide:



### Fuses

+12V, +5V, and +3.3V are fused.

* USE FUSES RATED **5A OR LESS**

* **DO NOT BYPASS FUSES**

ATX4VC uses common car fuses. Regular, Mini, and low-profile Mini all will work. Simply push into the holder.



Negative rails are not fused because they are low-current (around 200mA), and built-in protection is adequate.

### Fan Headers

Two PWM Fan headers are available. You can plug in standard 12V PC fans, both 3-Pin and 4-Pin.

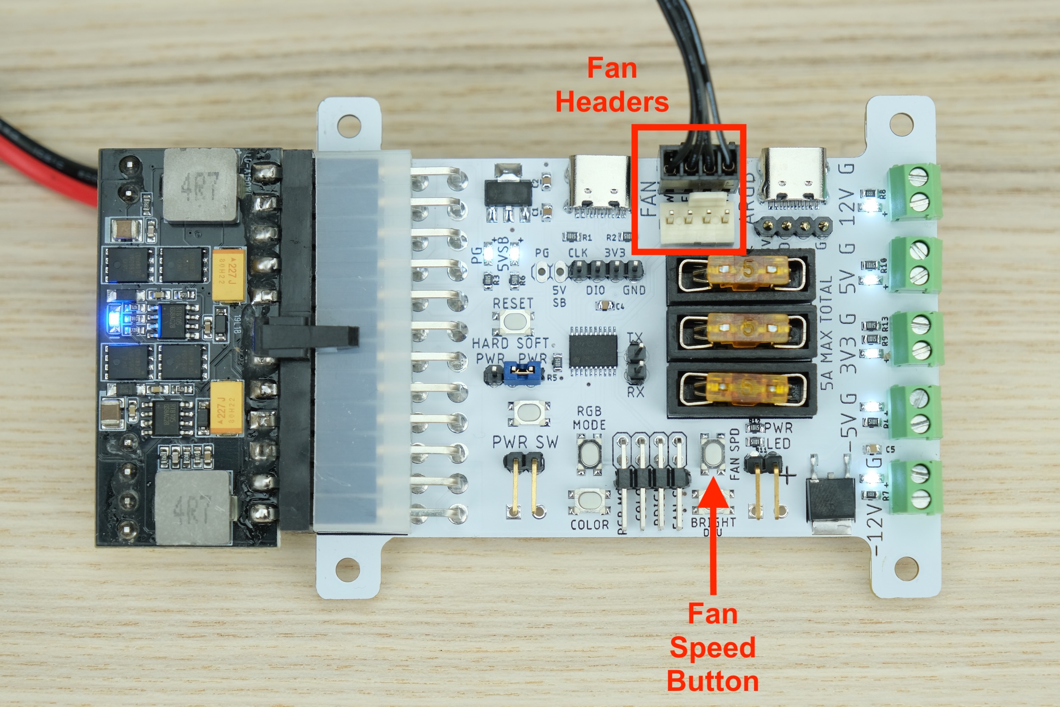
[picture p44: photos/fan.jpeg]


Press `FAN SPD` button to cycle through different speeds:

| Fan Speed (%) | Note |
|:---:|:---:|
| 0 | May or may not stop depending on fan itself |
| 20 | |
| 40 | |
| 55 | |
| 65 | |
| 80 | |
| 90 | |
| 100 | 3 fast blinks |
| Auto | 5 slow blinks |

Speed control only available on 4-Pin fans. 3-Pin fan will always run at full speed.

### Temperature Probe

ATX4VC supports the DS18B20 temperature sensor. They are inexpensive and very popular in Arduino projects.

The cheap ones on ebay are almost certainly counterfeits! They'll still work, but readings are noisier and less accurate.

Try a reputable distributor like [Sparkfun](https://www.sparkfun.com/products/11050), [Adafruit](https://www.adafruit.com/product/381), Mouser, or Digikey.

Connect the headers. Usually VCC is red, GND is black, DATA is yellow.

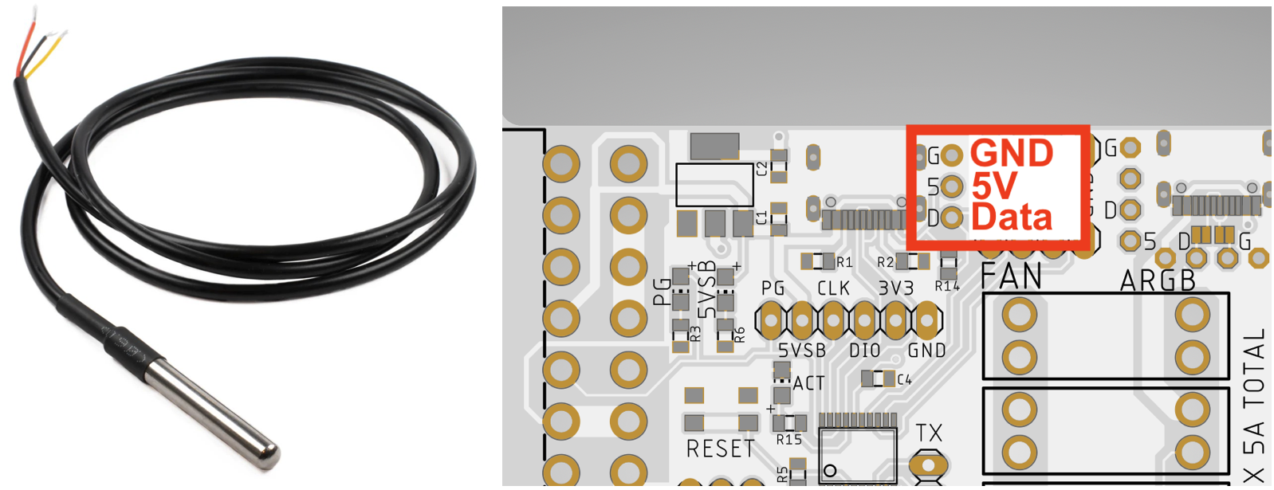
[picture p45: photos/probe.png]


Press **FAN SPD** button until the user LED `slowly blinks 5 times`. Now fan speed will depend on the temperature reading.

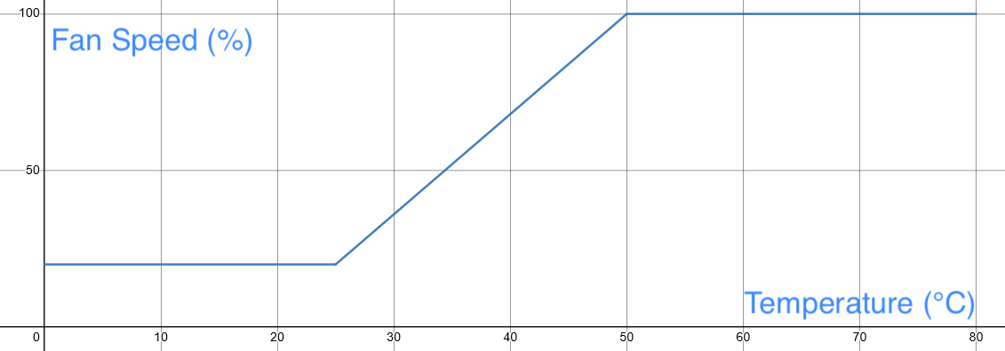
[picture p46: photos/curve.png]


The fan starts to speed up at 25°C, and reaches full speed at 50°C. If probe is not detected, it will run at full speed.

You can use a heat gun and air duster to test out the probe.

### Addressable RGB (ARGB)

Two standard ARGB headers are available. Simply plug them in. Up to 100 ARGB LEDs are supported.

Use **RGB MODE** button to change animation type, **BRIGHT** and **COLOUR** button to adjust brightness and colour.

Hold the button to cycle through faster.

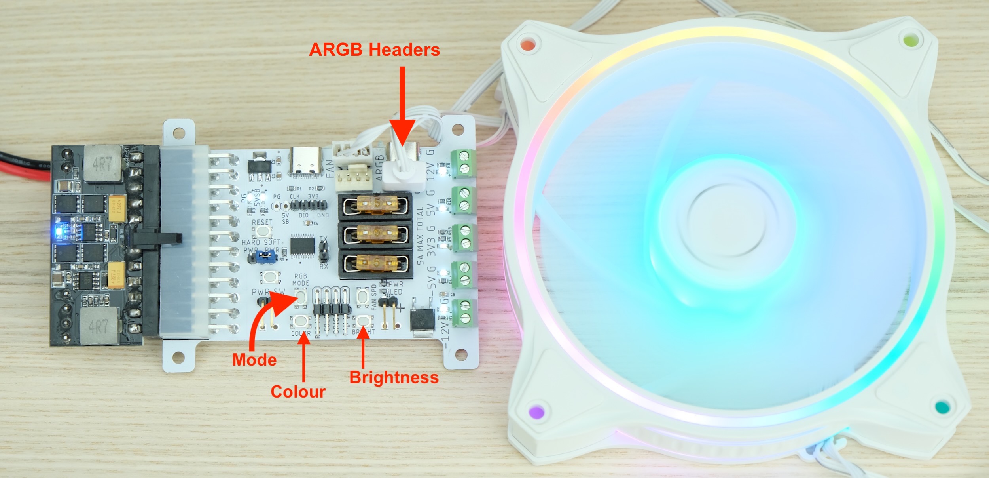
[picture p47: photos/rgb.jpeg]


### USB-C Power Output

Two USB-C connectors are available for powering external devices.

The left port provides 5V Standby, which is active even when PSU is off. Although max current is limited (typically 1 to 2 Amps)

The right port is on regular 5V rail. It can provide more current, but only available when PSU is on.

Those ports are **output only**, don't try to backfeed them with another powered device.

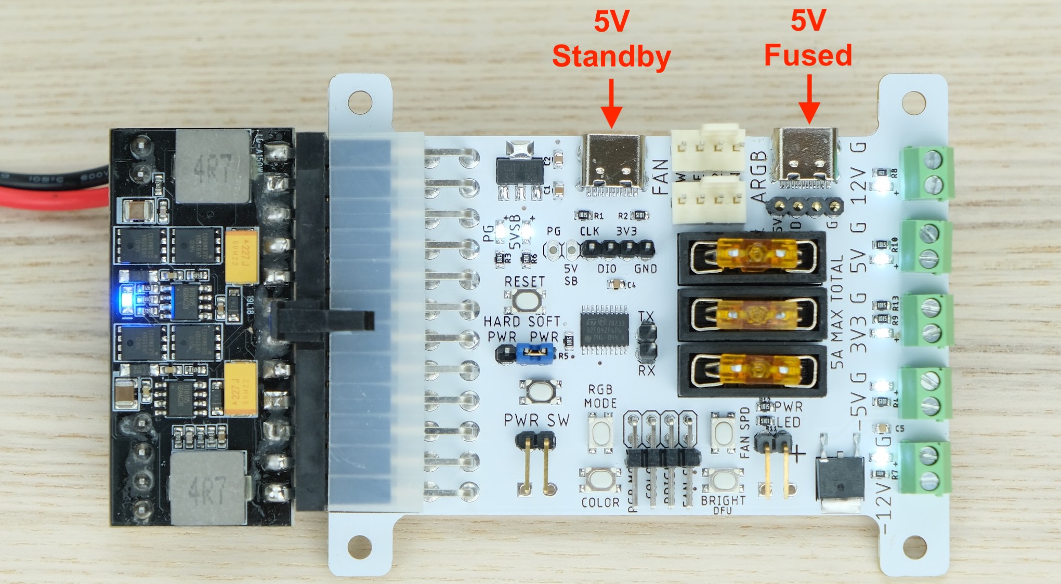
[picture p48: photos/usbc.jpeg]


### Dimension Drawings

ATX4VC is compatible with **2.5 inch PC drive bay**, and is compact enough to fit in most vintage computers.

Use M3 screws and nuts. Dimension drawing below:

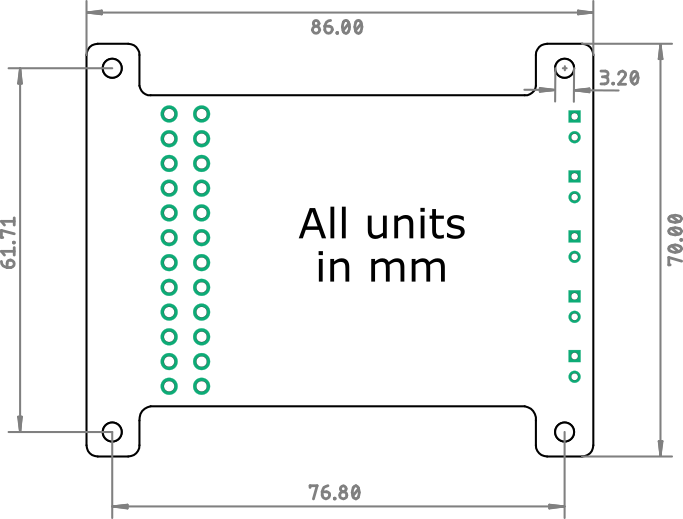
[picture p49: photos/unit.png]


## Additional Features

### Hard Power

Move the jumper to the left for hard power.

This shorts PS_ON pin to GND, and turns on PSU immediately when plugged in.

You can also wire up a toggle / latching switch to the left two pins to control the PSU directly.

### Button Header

External momentary buttons can be connected to adjust various settings:

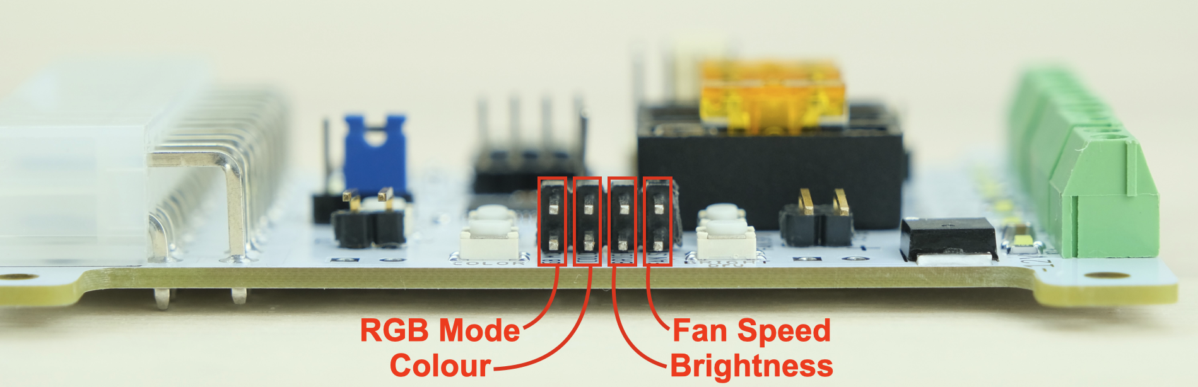
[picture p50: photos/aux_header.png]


### Additional Headers

A few more signals are available on headers.

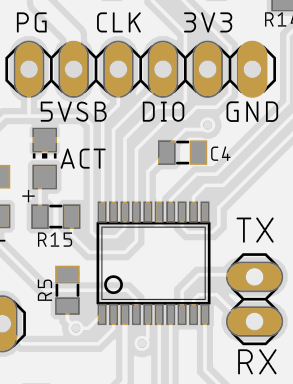
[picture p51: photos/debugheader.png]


|  Pin | Function | Note |
|:----:|:---:|---|
|  PG  | Power Good  | High (+5V) when output is correct and stable |
| 5VSB | 5V Standby  | Available when PSU is off, max current 2A usually|
|  CLK | SWCLK | For microcontroller (MCU) programming |
|  DIO | SWDIO | For MCU programming 			  |
|  3V3 | 3.3V Power  | Regulated from 5VSB for MCU power, 500mA max |
|  GND | Ground | |
|  TX  | UART Transmit | Prints some debugging messages @ 115200bps |
|  RX  | Unused | |

## USB Firmware Update

TURN OFF AND UNPLUG ATX PSU BEFORE STARTING.

Under construction ...

## Table of Contents (again)

[Quick Start Guide](#Quick-Start)

[Power Button and Power LED](#Power-Button-and-Power-LED)

[Power Connection](#Power-Connection)

[Current Limit](#Current-Limit)

[Fuses](#Fuses)

[Fan Headers](#Fan-Headers)

[Temperature Probe](#Temperature-Probe)

[Addressable RGB (ARGB)](#Addressable-RGB-ARGB)

[USB-C Power Output](#USB-C-Power-Output)

[Dimension Drawings](#Dimension-Drawings)

[Hard Power](#Hard-Power)

[RGBA over USB](#RGBA-over-USB)

[Additional Headers](#Additional-Headers)

[USB Firmware Update](#USB-Firmware-Update)

## Questions or Comments?

Feel free to ask in official [Discord Chatroom](https://discord.gg/T9uuFudg7j), raise a [Github issue](https://github.com/dekuNukem/ATX4VC/issues), or email `dekunukem` `gmail.com`!

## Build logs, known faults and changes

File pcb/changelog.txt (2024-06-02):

PT0
July 18 2022
Initial release

PT1
July 25 2022
added labels on debug header
cleaned up power OK and power on header

PT2
reduced footprint while keeping the screw holes location, so it will still fit into a 2.5 inch bay with openings for cables
changed to having one fan header and one ARGB header
added pots for changing fan speed, rgb brightness and rgb colour/speed

PT3
added terminal blocks for power LED and power button
moved on-board power button
adjusted silkscreen
removed pots and added buttons and headers instead
added restrict over 7905
added USB-C connector for ARGB

PT4
removed copper pour near terminals
power sense now uses PG signal
brightness button is shared with DFU button
added UART TX and RX header
added restrict under the fuse holder
rerouted signals around fuse holder
increased space between fuses
moved fan and ARGB header closer to edge
increased ARGB trace width
removed pullups on ARGB USB port
moved reset button slightly
power LED now runs on 5V
adjusted power LED and 3V3 LED resistance
big overhaul on current carrying trace, increased width, removed copper pour to improve isolation, added more restrict near fuses, rearranged top layer to allow max return current
added dual headers for fan and ARGB
switched fuse to car fuse, more modular and commonly available

PT5

fixed 3-in-1 fuse holder footprint
removed mini fuse holder
cleaned up PCB

PD1

Added header for DS18b21 1-wire temperature sensor 
added a indicator LED
moved ARGB header outside USBC footprint
removed thermals on GND
adjusted trace width
added jumper pad on 5V USBC data lines
double checked component values
wired to soft power by default, no need for header

PD1 V2
made more space for 2nd ARGB header
changed amp rating silkscreen
moved soft power and hard power silkscreen back to top

PD2

added additional 3.69mm power connector
moved power rail LED to the side
added fuse blow detect with 74lvc chip
rearranged components

PT6 20230404
added breakoff tabs
added in-board mounting holes
moved MCU to its own daughterboard
reduced PCB size
new lever terminal block
added 5VSB to terminal block

PT7 upcoming

Power Good in its own terminal block?
use 8 position terminal block and aux connector?

2024 revision
removed daughterboard
on-board soft power IC
voltage rail marking on bottom silkscreen

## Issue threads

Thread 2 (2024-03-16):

Can't use MCU daughterboard with MOLEX auxiliary power connector.

JohnDCartwright, 2024-03-16:
I was disappointed to find that on the 2 ATX4VCs that I have purchased the MCU daughter board overlaps the MOLEX auxiliary power connector, so both can not be used at the same time.
I had to mount the MCU daughterboards away from the ATX4VCs using a six pin extender cable.
Looking at the photo in the user manual, the MCU daughterboard does not overlap the auxiliary connector, so something has changed on the latest production!

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

dekuNukem, 2024-03-16:
Yeah the new revision of ATX4VC added POWER_GOOD signal to the terminal block, but I didnt notice that the daughterboard is now blocking the header!

I'm planning to design a new matching daughterboard as well, but in the meantime I'm happy to give you a refund for the daughterboard. Feel free to let me know the tindie order number.

JohnDCartwright, 2024-03-16:
My Tinder order number is Order #460717, but refund not necessary thanks, I have got round the problem by mounting the daughterboard separately. Just wanted to let you know about the problem.
Would be interested to learn about the new daughterboard when it arrives. 🙂

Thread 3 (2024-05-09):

Request:  have a look at adapting the ATX4VC for the Powermac G4

someyob, 2024-05-09:
The power supply in these Powermacs are known to fail, so I expect there will be a market for them.  They are non-standard ATX-style.

There are a few wrinkles regarding Standby/Trickle power, as described here:  http://atxg4.com/gige-da.html

I have the ATX4VC, recently received, with the daughter board that gives you the soft power button.

I have built a wiring harness as described there, with the two diodes, and wired it to the ATX4VC, and so far haven't had the luck to get a rise out of the machine.  There may still be something else wrong with my G4, or in the manner I'm hooking up the ATX4VC, or in the manner of soft-powering.

If you would like more detail about my setup, I will happily oblige.

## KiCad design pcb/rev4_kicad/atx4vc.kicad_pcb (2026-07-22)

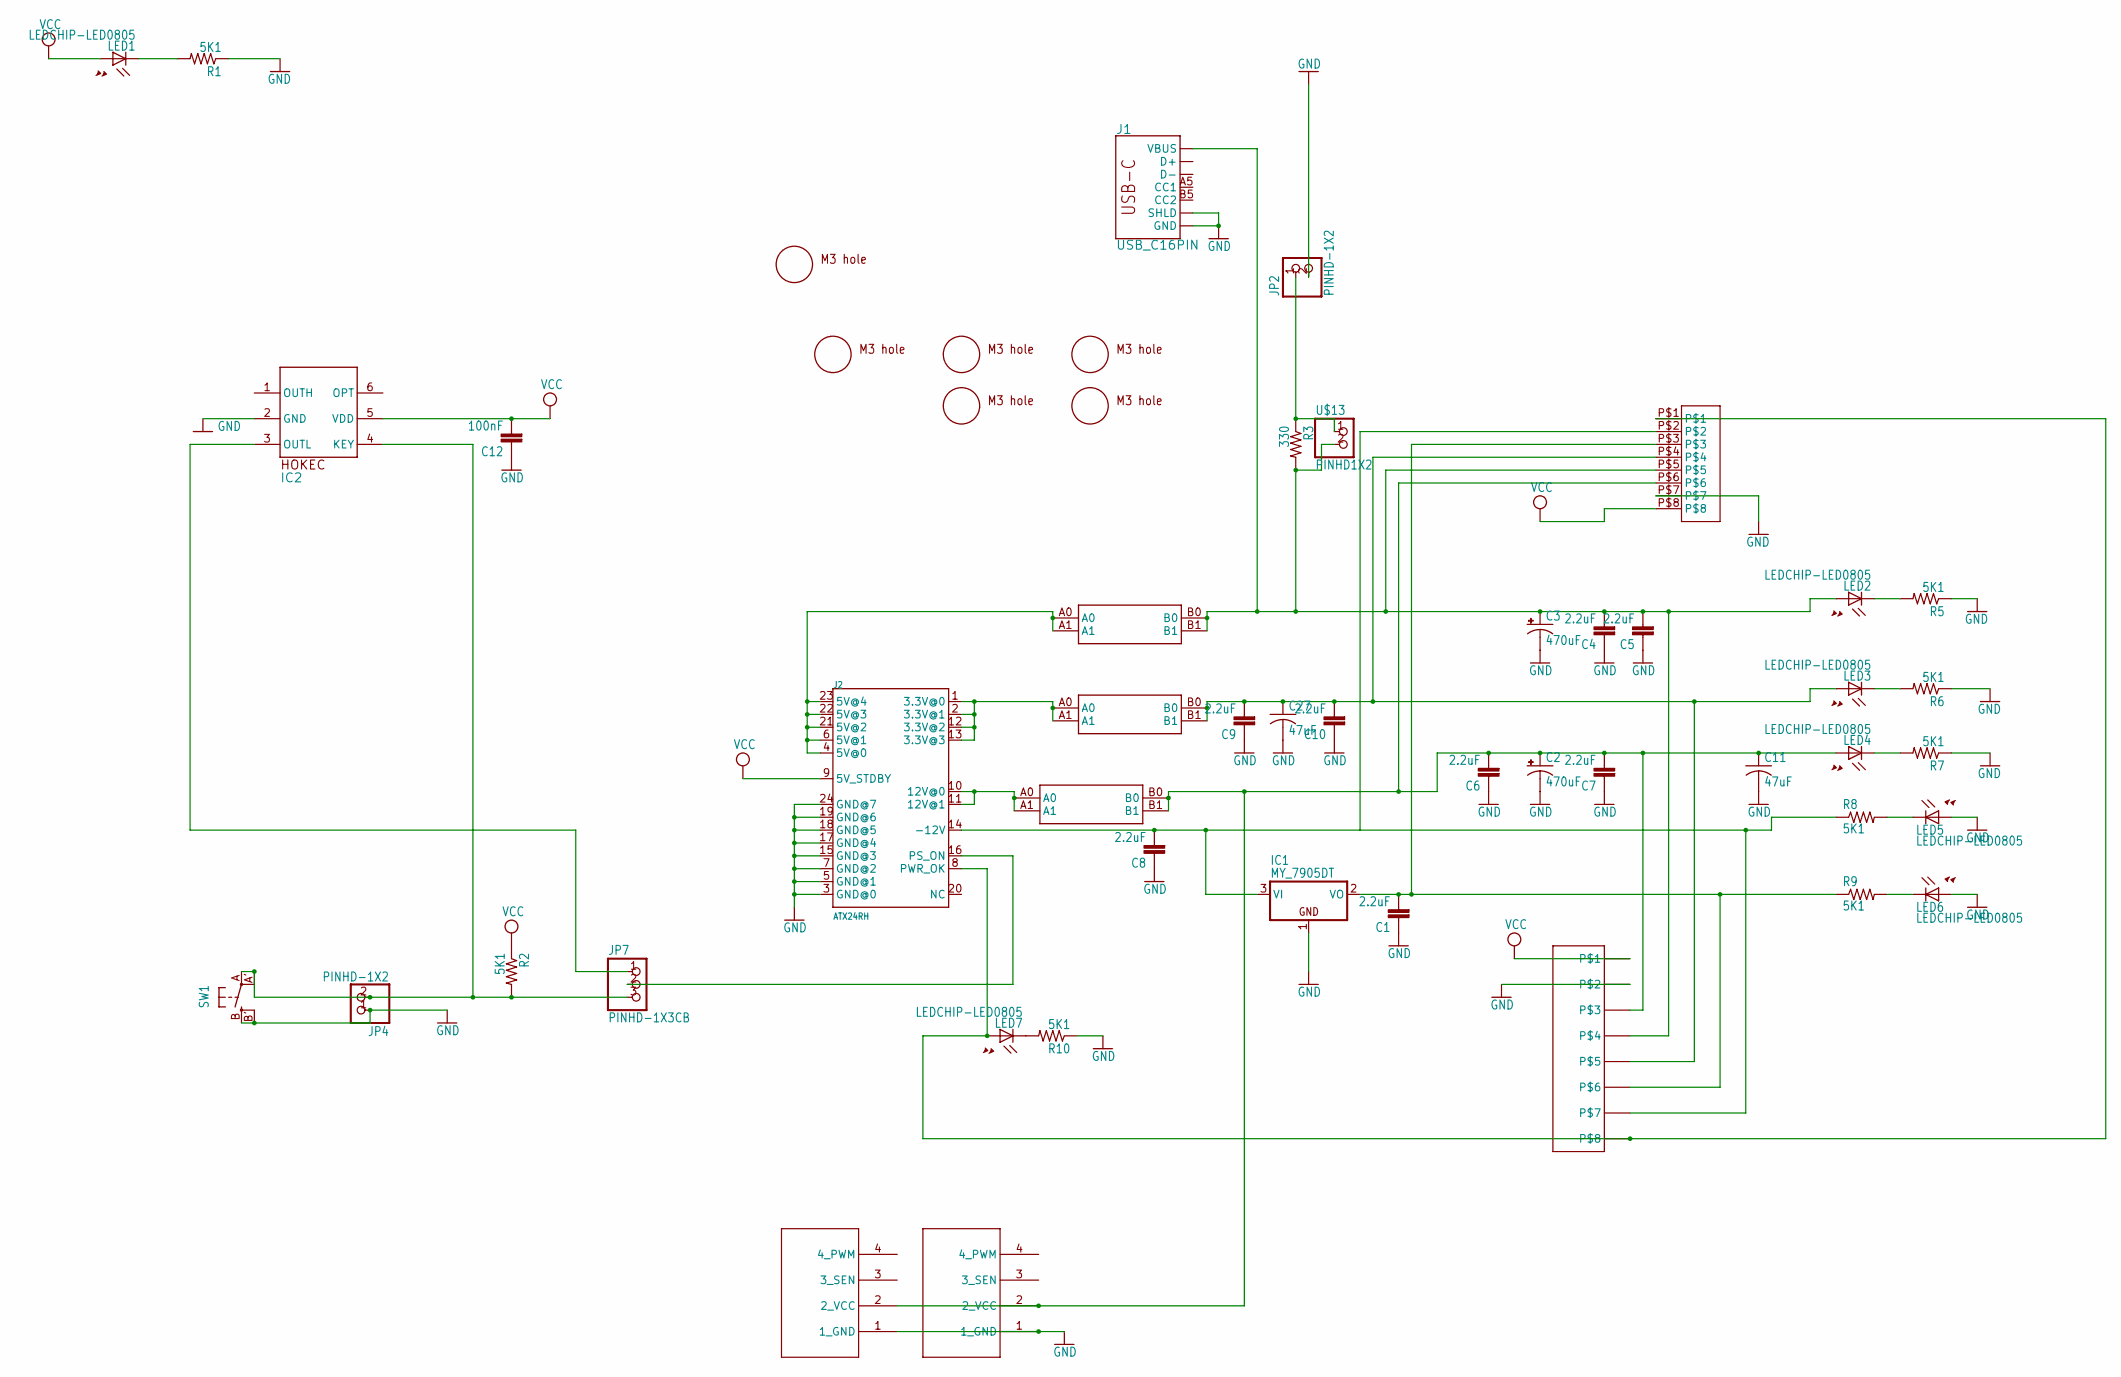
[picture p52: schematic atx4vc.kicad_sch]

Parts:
C1, C4, C5, C6, C7, C8, C9, C10: 2.2uF; 0805$1
C2, C3: 470uF; SMC_D
C11, C27: 47uF; C1210
C12: 100nF; 0805$1
IC1: MY_7905DT; ADAFRUIT_TO252
IC2: MAX486X/SOT; SOT23-6
J1: USB_C16PIN; USB-C-16P
J2: ATX24RH; ATX24_RIGHT_ANGLE
JP1, JP5: 4PIN_FAN; 1X04
JP2, JP4: PINHD-1X2; 1X02
JP7: PINHD-1X3CB; 1X03-CLEANBIG
LED1, LED2, LED3, LED4, LED5, LED6, LED7: LEDCHIP-LED0805; CHIP-LED0805
R1, R2, R5, R6, R7, R8, R9, R10: 5K1; 0805
R3: 330; 0805
SW1: SPST_TACT-EVQQ2; EVQ-Q2
U$1, U$2, U$3, U$4, U$5, U$6: M3_MOUNTING_HOLE; M3_MOUNTING_HOLE_PACK
U$7: 396_CONN_VH396_8P; 396_CONN_396_8P
U$9, U$10, U$11: CAR_FUSE_HOLDER3IN1; FUSE_HOLDER_3IN1
U$12: DG2204R-5.0-8DG2204-8; DG2204R-8
U$13: PINHD1X2; 1X02

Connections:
GND: C1.1, C2.-, C3.-, C4.1, C5.1, C6.1, C7.1, C8.1, C9.1, C10.1, C11.2, C12.1, C27.2, IC1.1 (GND), IC2.2 (GND), J1.GND, J1.GND2 (GND), J1.SHLD1 (SHLD), J1.SHLD2 (SHLD), J1.SHLD3 (SHLD), J1.SHLD4 (SHLD), J1.SHLD5 (SHLD), J1.SHLD6 (SHLD), J1.SHLD7 (SHLD), J1.SHLD8 (SHLD), J2.3 (GND@0), J2.5 (GND@1), J2.7 (GND@2), J2.15 (GND@3), J2.17 (GND@4), J2.18 (GND@5), J2.19 (GND@6), J2.24 (GND@7), JP1.1 (1_GND), JP2.2, JP4.1, JP5.1 (1_GND), LED5.A, LED6.A, R1.1, R5.1, R6.1, R7.1, R10.1, SW1.B (S), SW1.B' (S1), U$7.P$7, U$12.P$3, U$12.P$4
unnamed: C3.+, C4.2, C5.2, J1.VBUS1 (VBUS), J1.VBUS2 (VBUS), LED2.A, R3.2, U$7.P$5, U$9.B0, U$9.B1, U$12.P$7, U$12.P$8, U$13.2
unnamed: C9.2, C10.2, C27.1, LED3.A, U$7.P$4, U$10.B0, U$10.B1, U$12.P$9, U$12.P$10
unnamed: C8.2, IC1.3 (VI), J2.14 (-12V), R8.1, U$7.P$2, U$12.P$13, U$12.P$14
unnamed: C1.2, IC1.2 (VO), R9.1, U$7.P$3, U$12.P$11, U$12.P$12
unnamed: IC2.4 (KEY), JP4.2, JP7.3, R2.2, SW1.A, SW1.A' (P1)
unnamed: IC2.3 (OUTL), JP7.1
unnamed: J1.A6 (D+), J1.B6 (D+)
unnamed: J1.A7 (D-), J1.B7 (D-)
unnamed: J2.1 (3.3V@0), J2.2 (3.3V@1), J2.12 (3.3V@2), J2.13 (3.3V@3), U$10.A0, U$10.A1
unnamed: J2.4 (5V@0), J2.6 (5V@1), J2.21 (5V@2), J2.22 (5V@3), J2.23 (5V@4), U$9.A0, U$9.A1
unnamed: J2.10 (12V@0), J2.11 (12V@1), U$11.A0, U$11.A1
unnamed: J2.16 (PS_ON), JP7.2
unnamed: J2.8 (PWR_OK), LED7.A, U$7.P$1, U$12.P$15, U$12.P$16
unnamed: C2.+, C6.2, C7.2, C11.1, JP1.2 (2_VCC), JP5.2 (2_VCC), LED4.A, U$7.P$6, U$11.B0, U$11.B1, U$12.P$5, U$12.P$6
unnamed: JP2.1, R3.1, U$13.1
unnamed: LED1.C, R1.2
unnamed: LED2.C, R5.2
unnamed: LED3.C, R6.2
unnamed: LED4.C, R7.2
unnamed: LED5.C, R8.2
unnamed: LED6.C, R9.2
unnamed: LED7.C, R10.2
VCC: C12.2, IC2.5 (VDD), J2.9 (5V_STDBY), LED1.A, R2.1, U$7.P$8, U$12.P$1, U$12.P$2

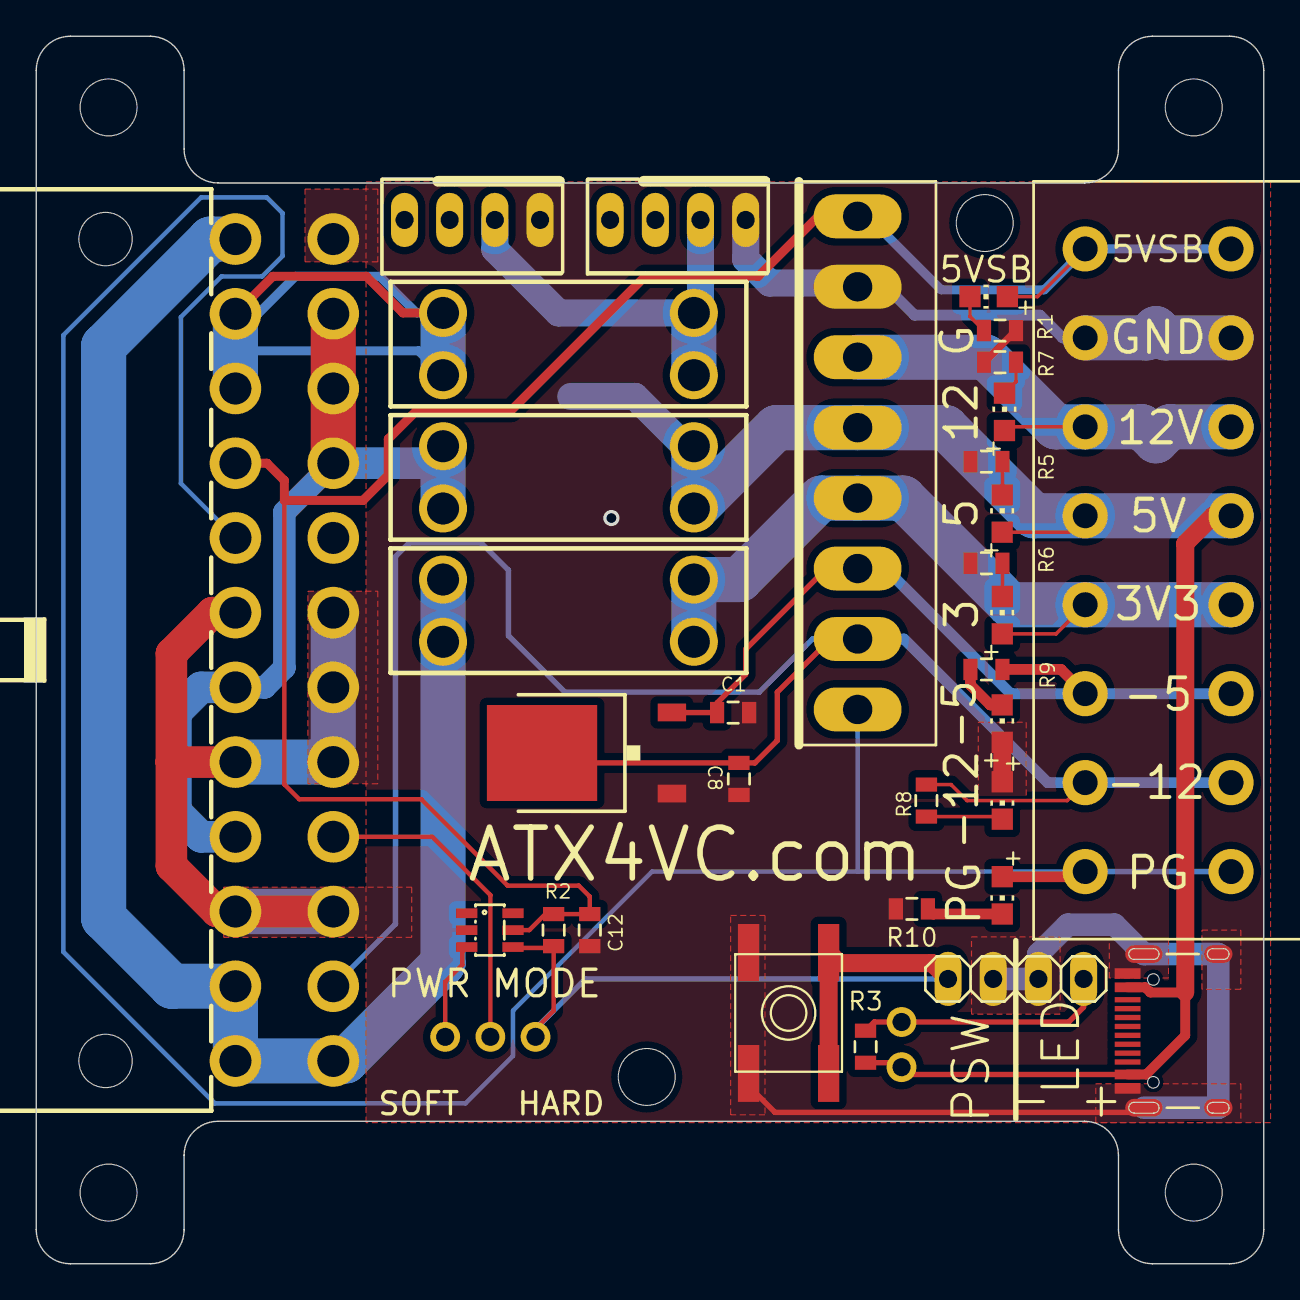
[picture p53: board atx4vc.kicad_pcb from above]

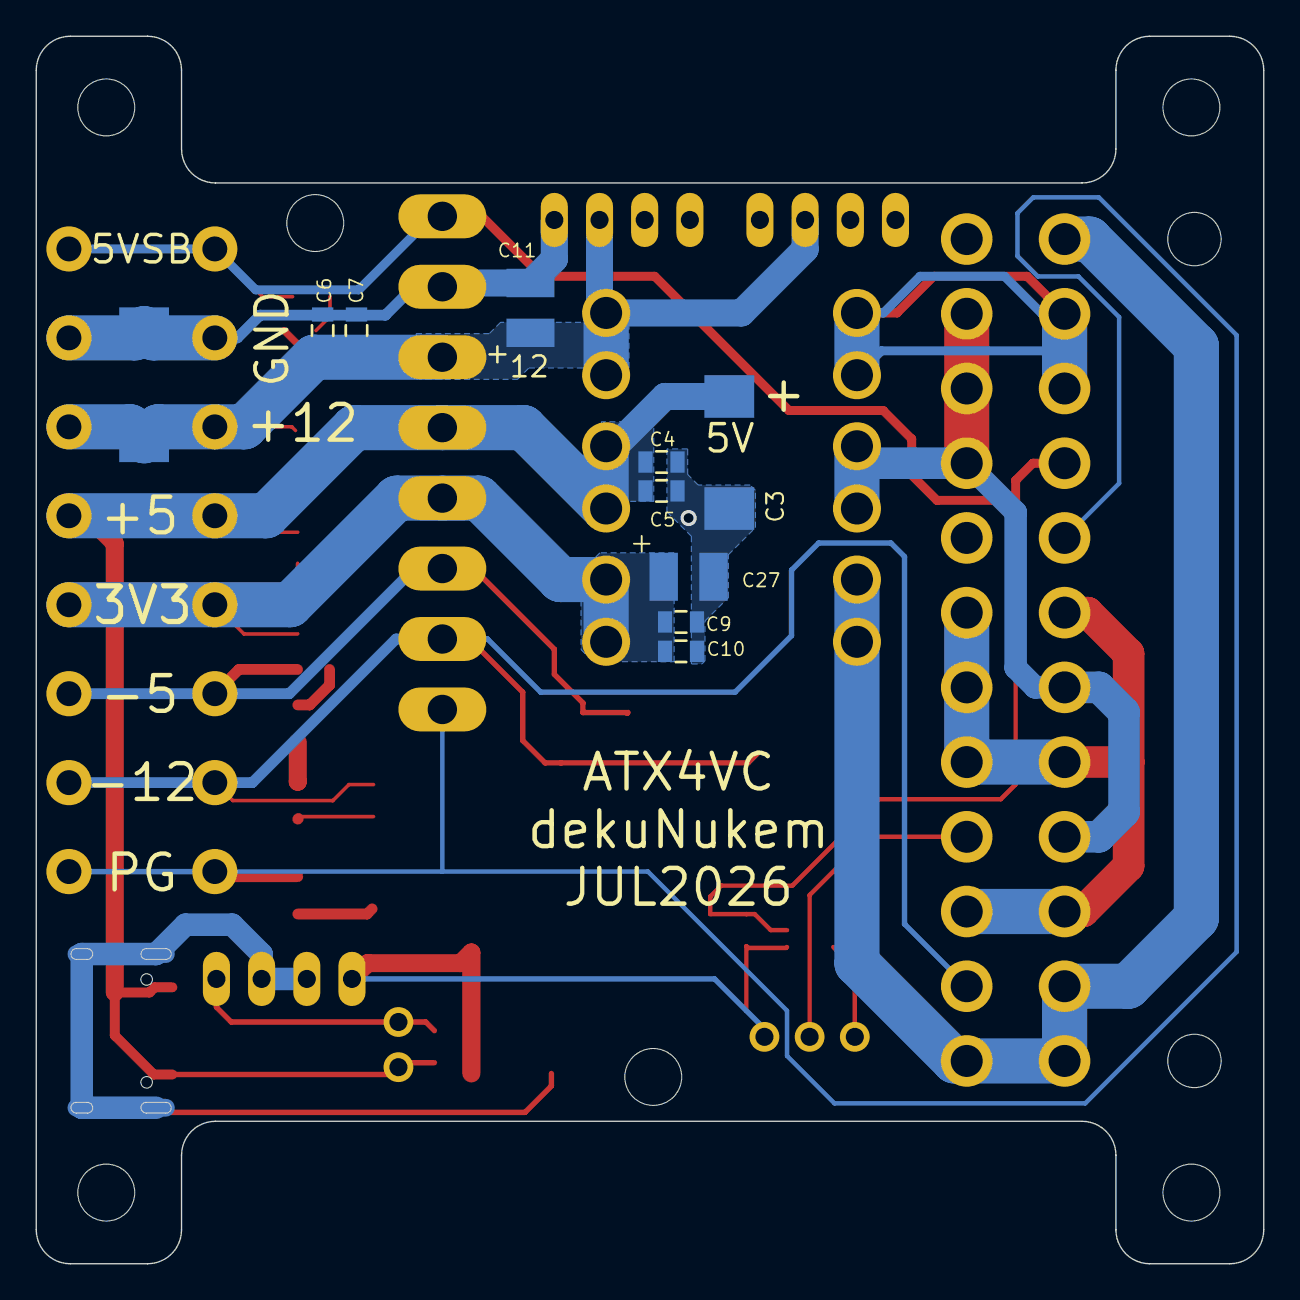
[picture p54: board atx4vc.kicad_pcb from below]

Board: 2 copper layers, 69.0 x 69.0 mm, 51 parts (10 on the bottom side), 24 nets.

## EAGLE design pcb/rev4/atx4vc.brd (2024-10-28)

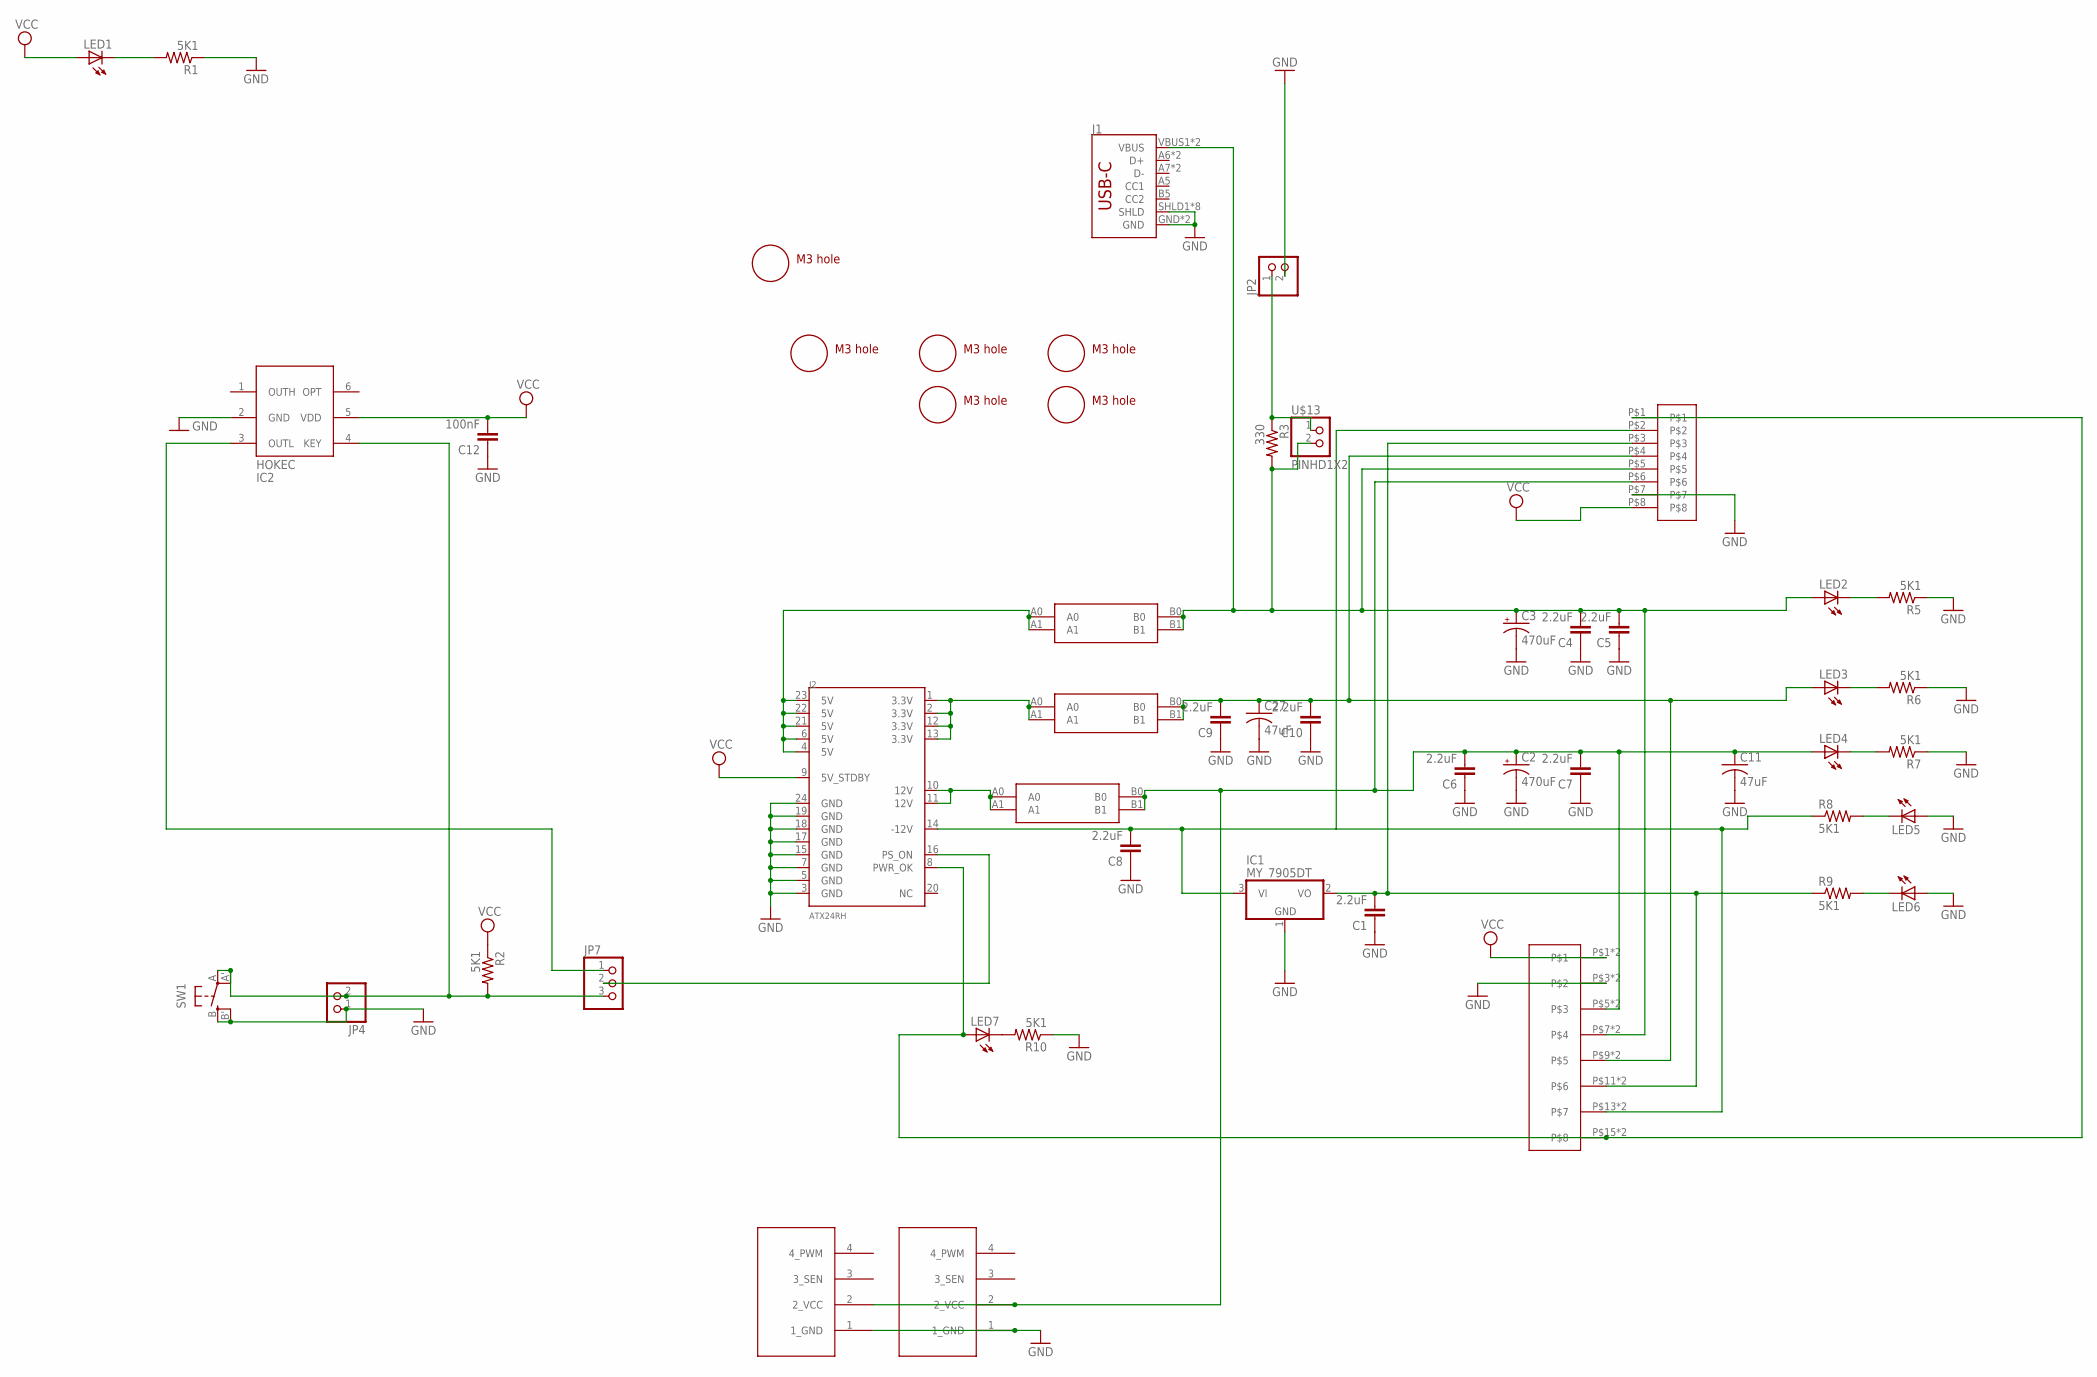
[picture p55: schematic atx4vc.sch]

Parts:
C1, C4, C5, C6, C7, C8, C9, C10: 2.2uF; 0805$1
C2, C3: 470uF; SMC_D
C11, C27: 47uF; C1210
C12: 100nF; 0805$1
IC1: MY_7905DT; ADAFRUIT_TO252
IC2: MAX486X/SOT; SOT23-6
J1: USB_C16PIN; USB-C-16P
J2: ATX24RH; ATX24_RIGHT_ANGLE
JP1, JP5: 4PIN_FAN; 1X04
JP2, JP4: PINHD-1X2; 1X02
JP7: PINHD-1X3CB; 1X03-CLEANBIG
LED1, LED2, LED3, LED4, LED5, LED6, LED7: LEDCHIP-LED0805; CHIP-LED0805
R1, R2, R5, R6, R7, R8, R9, R10: 5K1; 0805
R3: 330; 0805
SW1: SPST_TACT-EVQQ2; EVQ-Q2
U$1, U$2, U$3, U$4, U$5, U$6: M3_MOUNTING_HOLE; M3_MOUNTING_HOLE_PACK
U$7: 396_CONN_VH396_8P; 396_CONN_396_8P
U$9, U$10, U$11: CAR_FUSE_HOLDER3IN1; FUSE_HOLDER_3IN1
U$12: DG2204R-5.0-8DG2204-8; DG2204R-8
U$13: PINHD1X2; 1X02

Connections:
-5V: C1.2, IC1.2 (VO), R9.1, U$7.P$3, U$12.P$11, U$12.P$12
-12V: C8.2, IC1.3 (VI), J2.14 (-12V), R8.1, U$7.P$2, U$12.P$13, U$12.P$14
F3V3: C9.2, C10.2, C27.1, LED3.A, U$7.P$4, U$10.B0, U$10.B1, U$12.P$9, U$12.P$10
F5V: C3.+, C4.2, C5.2, J1.VBUS1 (VBUS), J1.VBUS2 (VBUS), LED2.A, R3.2, U$7.P$5, U$9.B0, U$9.B1, U$12.P$7, U$12.P$8, U$13.2
F12V: C2.+, C6.2, C7.2, C11.1, JP1.2 (2_VCC), JP5.2 (2_VCC), LED4.A, U$7.P$6, U$11.B0, U$11.B1, U$12.P$5, U$12.P$6
GND: C1.1, C2.-, C3.-, C4.1, C5.1, C6.1, C7.1, C8.1, C9.1, C10.1, C11.2, C12.1, C27.2, IC1.1 (GND), IC2.2 (GND), J1.GND, J1.GND2 (GND), J1.SHLD1 (SHLD), J1.SHLD2 (SHLD), J1.SHLD3 (SHLD), J1.SHLD4 (SHLD), J1.SHLD5 (SHLD), J1.SHLD6 (SHLD), J1.SHLD7 (SHLD), J1.SHLD8 (SHLD), J2.3 (GND), J2.5 (GND), J2.7 (GND), J2.15 (GND), J2.17 (GND), J2.18 (GND), J2.19 (GND), J2.24 (GND), JP1.1 (1_GND), JP2.2, JP4.1, JP5.1 (1_GND), LED5.A, LED6.A, R1.1, R5.1, R6.1, R7.1, R10.1, SW1.B (S), SW1.B' (S1), U$7.P$7, U$12.P$3, U$12.P$4
unnamed: LED7.C, R10.2
unnamed: LED6.C, R9.2
unnamed: IC2.3 (OUTL), JP7.1
unnamed: LED5.C, R8.2
unnamed: LED4.C, R7.2
unnamed: J2.4 (5V), J2.6 (5V), J2.21 (5V), J2.22 (5V), J2.23 (5V), U$9.A0, U$9.A1
unnamed: J2.8 (PWR_OK), LED7.A, U$7.P$1, U$12.P$15, U$12.P$16
unnamed: IC2.4 (KEY), JP4.2, JP7.3, R2.2, SW1.A, SW1.A' (P1)
unnamed: J2.1 (3.3V), J2.2 (3.3V), J2.12 (3.3V), J2.13 (3.3V), U$10.A0, U$10.A1
unnamed: J2.16 (PS_ON), JP7.2
unnamed: JP2.1, R3.1, U$13.1
unnamed: LED3.C, R6.2
unnamed: LED2.C, R5.2
unnamed: J2.10 (12V), J2.11 (12V), U$11.A0, U$11.A1
unnamed: LED1.C, R1.2
VCC: C12.2, IC2.5 (VDD), J2.9 (5V_STDBY), LED1.A, R2.1, U$7.P$8, U$12.P$1, U$12.P$2

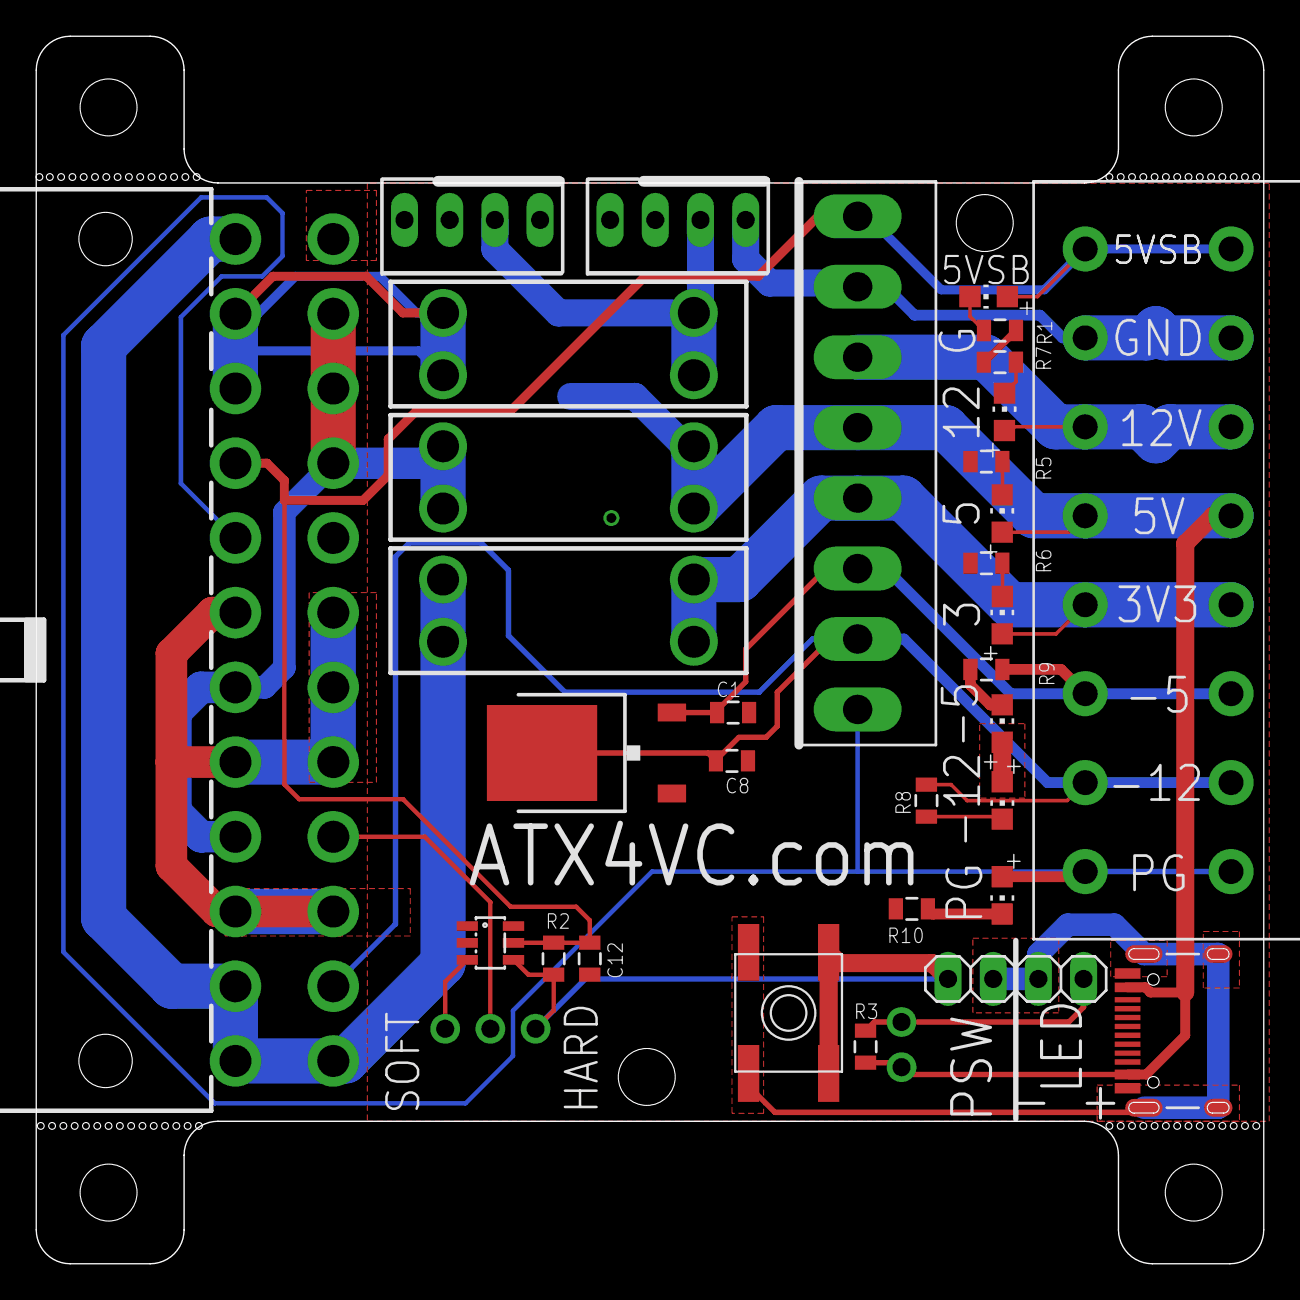
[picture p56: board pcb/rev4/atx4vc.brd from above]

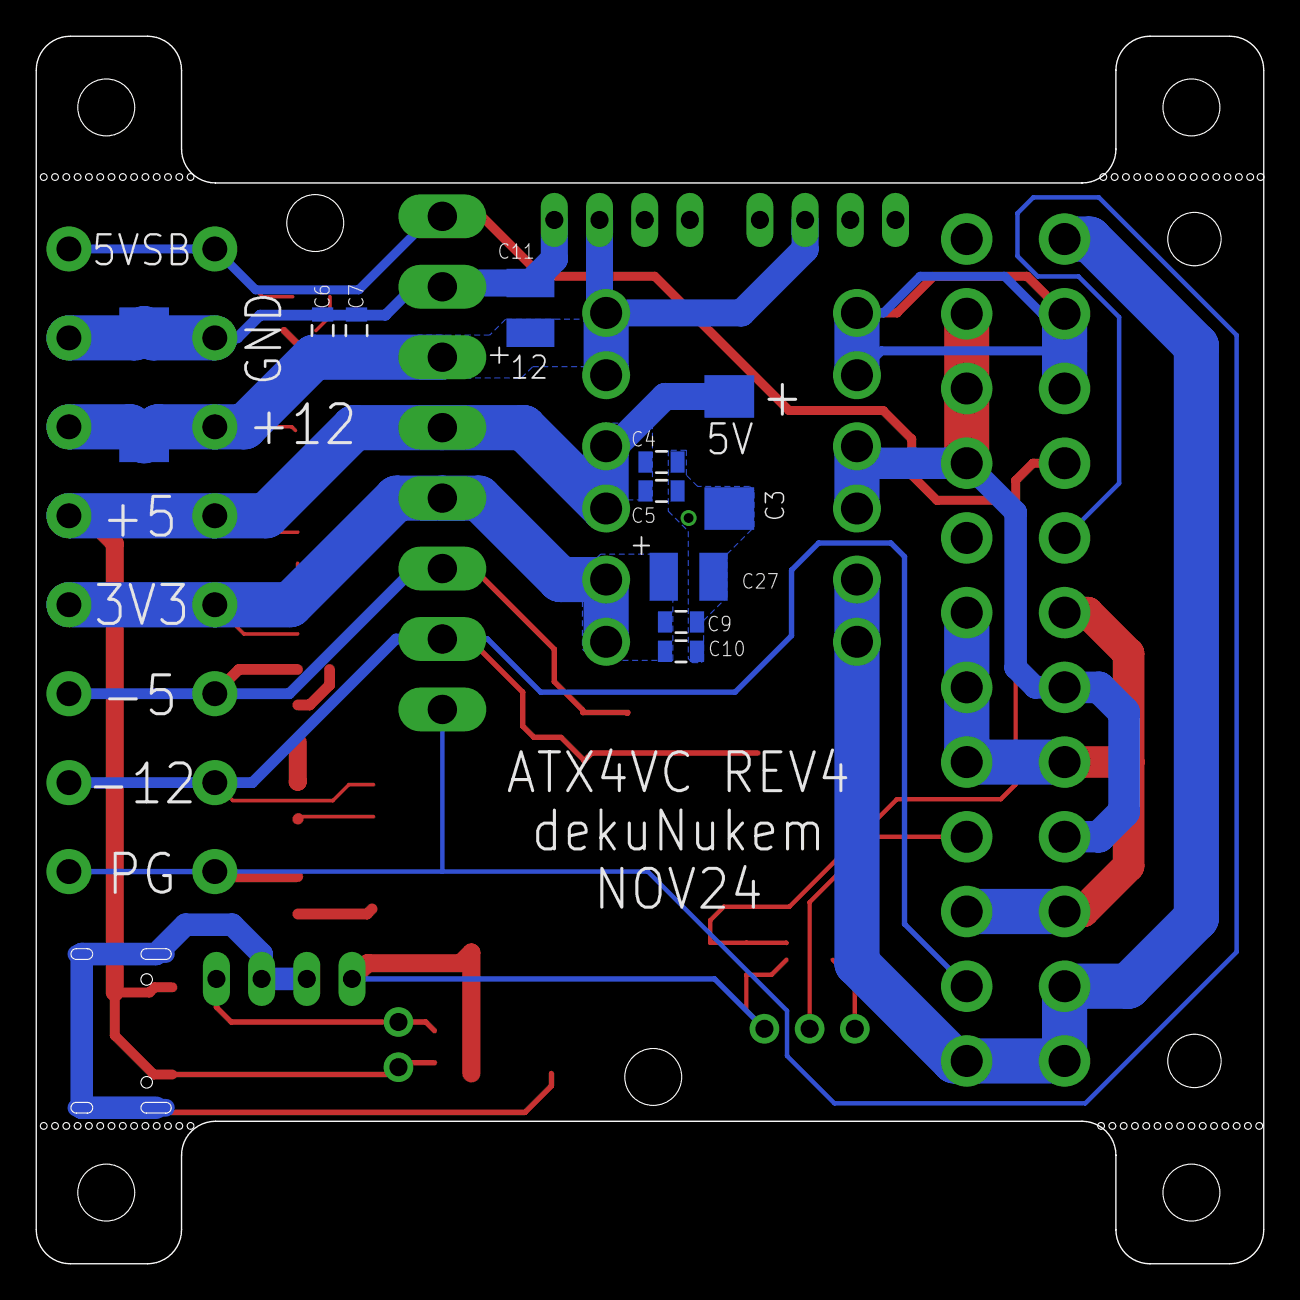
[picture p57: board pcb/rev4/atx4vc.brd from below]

Board: 2 copper layers, 69.0 x 69.0 mm, 51 parts (10 on the bottom side), 22 nets.

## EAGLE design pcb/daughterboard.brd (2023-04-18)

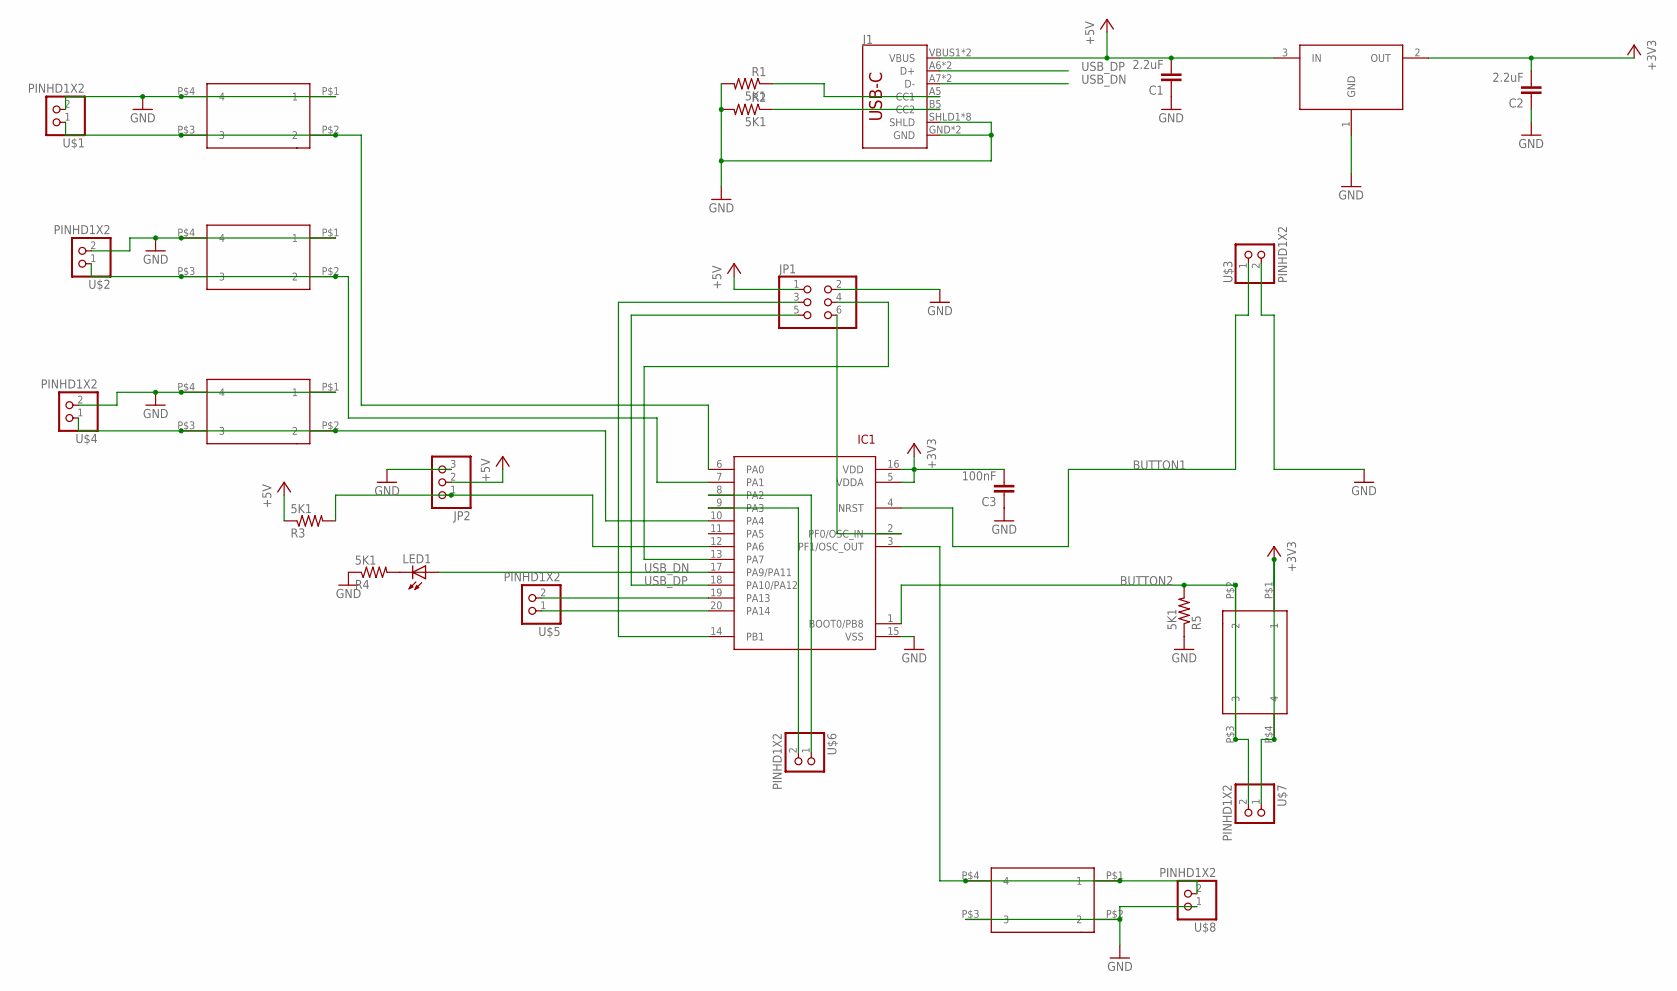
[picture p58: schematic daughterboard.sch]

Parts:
C1, C2: 2.2uF; 0805@1
C3: 100nF; 0805@1
IC1: STM32F042F4; TSSOP20
J1: USB_C16PIN; USB-C-16P
JP1: PINHD-2X3; 2X03
JP2: PINHD-1X3CB; 1X03-CLEANBIG
LED1: LEDCHIP-LED0805; CHIP-LED0805
R1, R2, R3, R4, R5: 5K1; 0805
SW1, SW2, SW3, SW4, SW5: 324_SW; 342_SWICH_FOOT
U1: XC6206_DEV; SOT23R_INFINEON
U$1, U$2, U$3, U$4, U$5, U$6, U$7, U$8: PINHD1X2; 1X02

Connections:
+3V3: C2.2, C3.2, IC1.5 (VDDA), IC1.16 (VDD), SW4.P$1 (1), SW4.P$4 (4), U1.2 (OUT), U$7.1
+5V: C1.2, J1.VBUS1 (VBUS), J1.VBUS2 (VBUS), JP1.1, JP2.2, R3.1, U1.3 (IN)
BUTTON1: IC1.4 (NRST), U$3.1
BUTTON2: IC1.1 (BOOT0/PB8), R5.2, SW4.P$2 (2), SW4.P$3 (3), U$7.2
GND: C1.1, C2.1, C3.1, IC1.15 (VSS), J1.GND, J1.GND2 (GND), J1.SHLD1 (SHLD), J1.SHLD2 (SHLD), J1.SHLD3 (SHLD), J1.SHLD4 (SHLD), J1.SHLD5 (SHLD), J1.SHLD6 (SHLD), J1.SHLD7 (SHLD), J1.SHLD8 (SHLD), JP1.2, JP2.3, R1.2, R2.2, R4.1, R5.1, SW1.P$1 (1), SW1.P$4 (4), SW2.P$1 (1), SW2.P$4 (4), SW3.P$1 (1), SW3.P$4 (4), SW5.P$2 (2), SW5.P$3 (3), U1.1 (GND), U$1.2, U$2.2, U$3.2, U$4.2, U$8.1
unnamed: IC1.13 (PA7), JP1.4
unnamed: IC1.14 (PB1), JP1.3
unnamed: IC1.19 (PA13), U$5.2
unnamed: IC1.20 (PA14), U$5.1
unnamed: IC1.12 (PA6), JP2.1, R3.2
unnamed: IC1.2 (PF0/OSC_IN), JP1.6
unnamed: IC1.8 (PA2), U$6.1
unnamed: IC1.9 (PA3), U$6.2
unnamed: IC1.10 (PA4), SW3.P$2 (2), SW3.P$3 (3), U$4.1
unnamed: IC1.7 (PA1), SW2.P$2 (2), SW2.P$3 (3), U$2.1
unnamed: IC1.6 (PA0), SW1.P$2 (2), SW1.P$3 (3), U$1.1
unnamed: IC1.3 (PF1/OSC_OUT), SW5.P$1 (1), SW5.P$4 (4), U$8.2
unnamed: LED1.C, R4.2
unnamed: J1.B5 (CC2), R2.1
unnamed: J1.A5 (CC1), R1.1
USB_DN: IC1.17 (PA9/PA11), J1.A7 (D-), J1.B7 (D-), LED1.A
USB_DP: IC1.18 (PA10/PA12), J1.A6 (D+), J1.B6 (D+), JP1.5

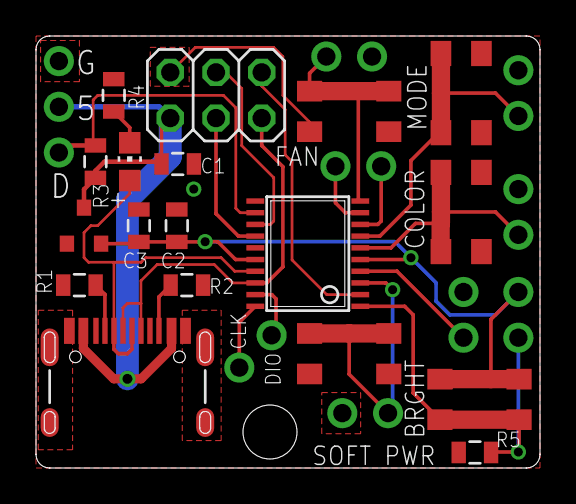
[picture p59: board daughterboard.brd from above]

Board: 2 copper layers, 28.0 x 24.0 mm, 27 parts (0 on the bottom side), 22 nets.

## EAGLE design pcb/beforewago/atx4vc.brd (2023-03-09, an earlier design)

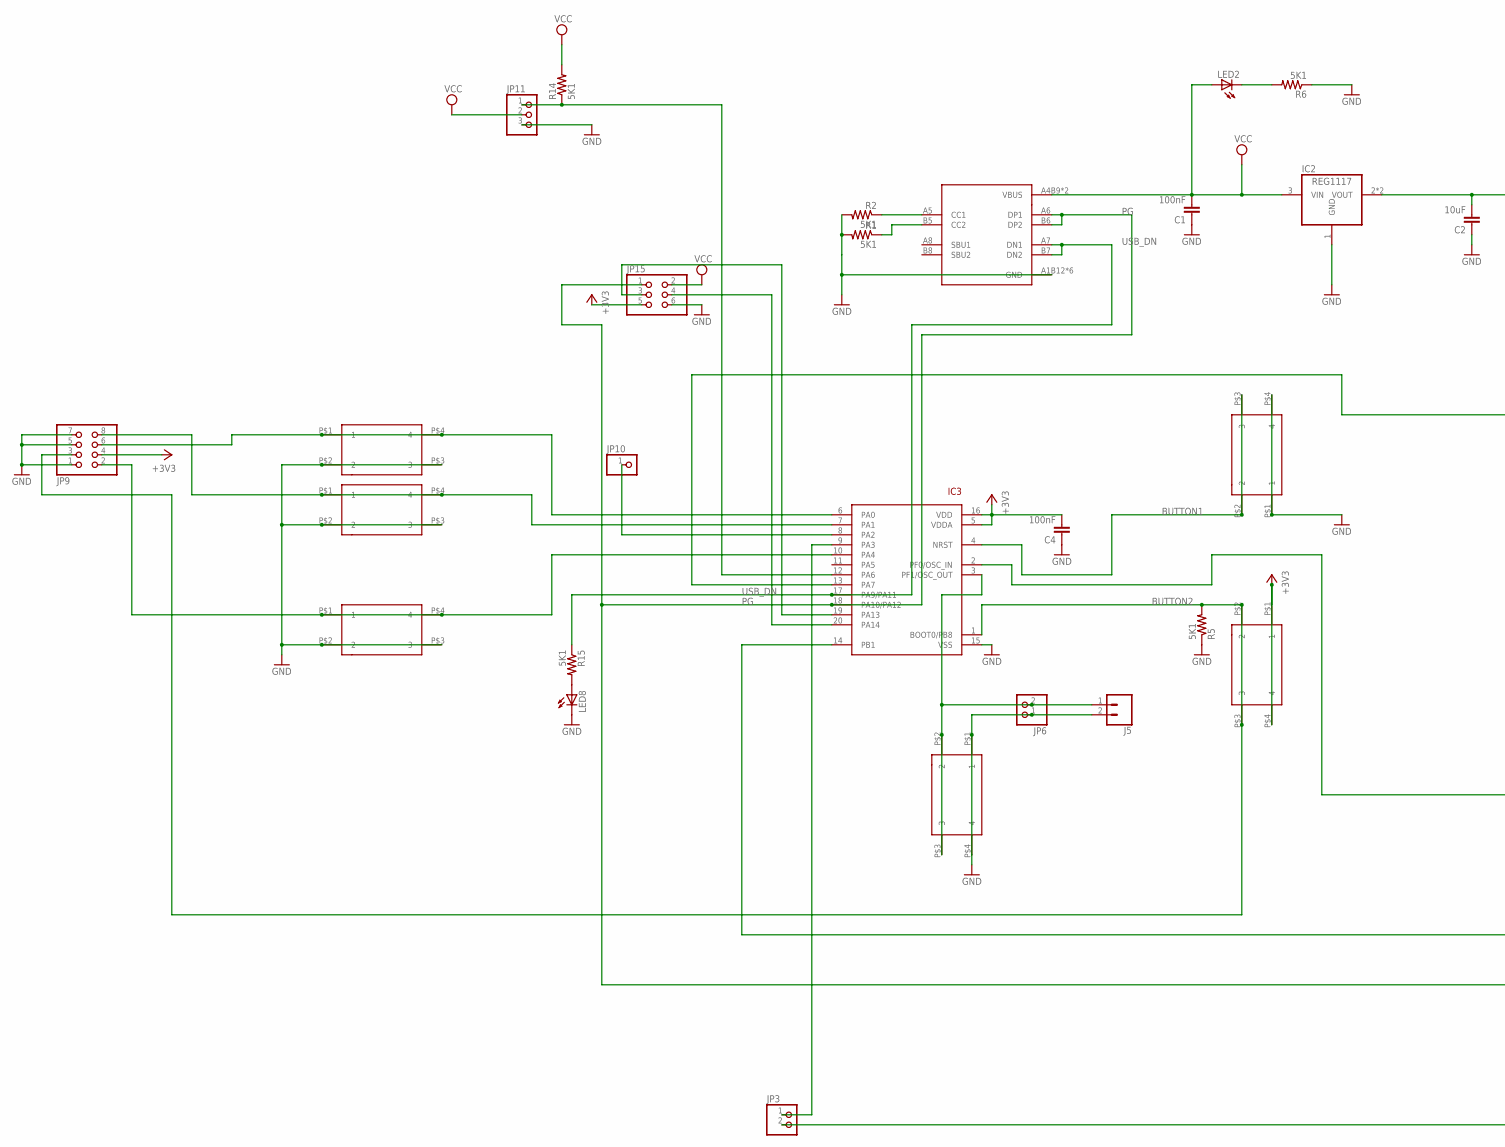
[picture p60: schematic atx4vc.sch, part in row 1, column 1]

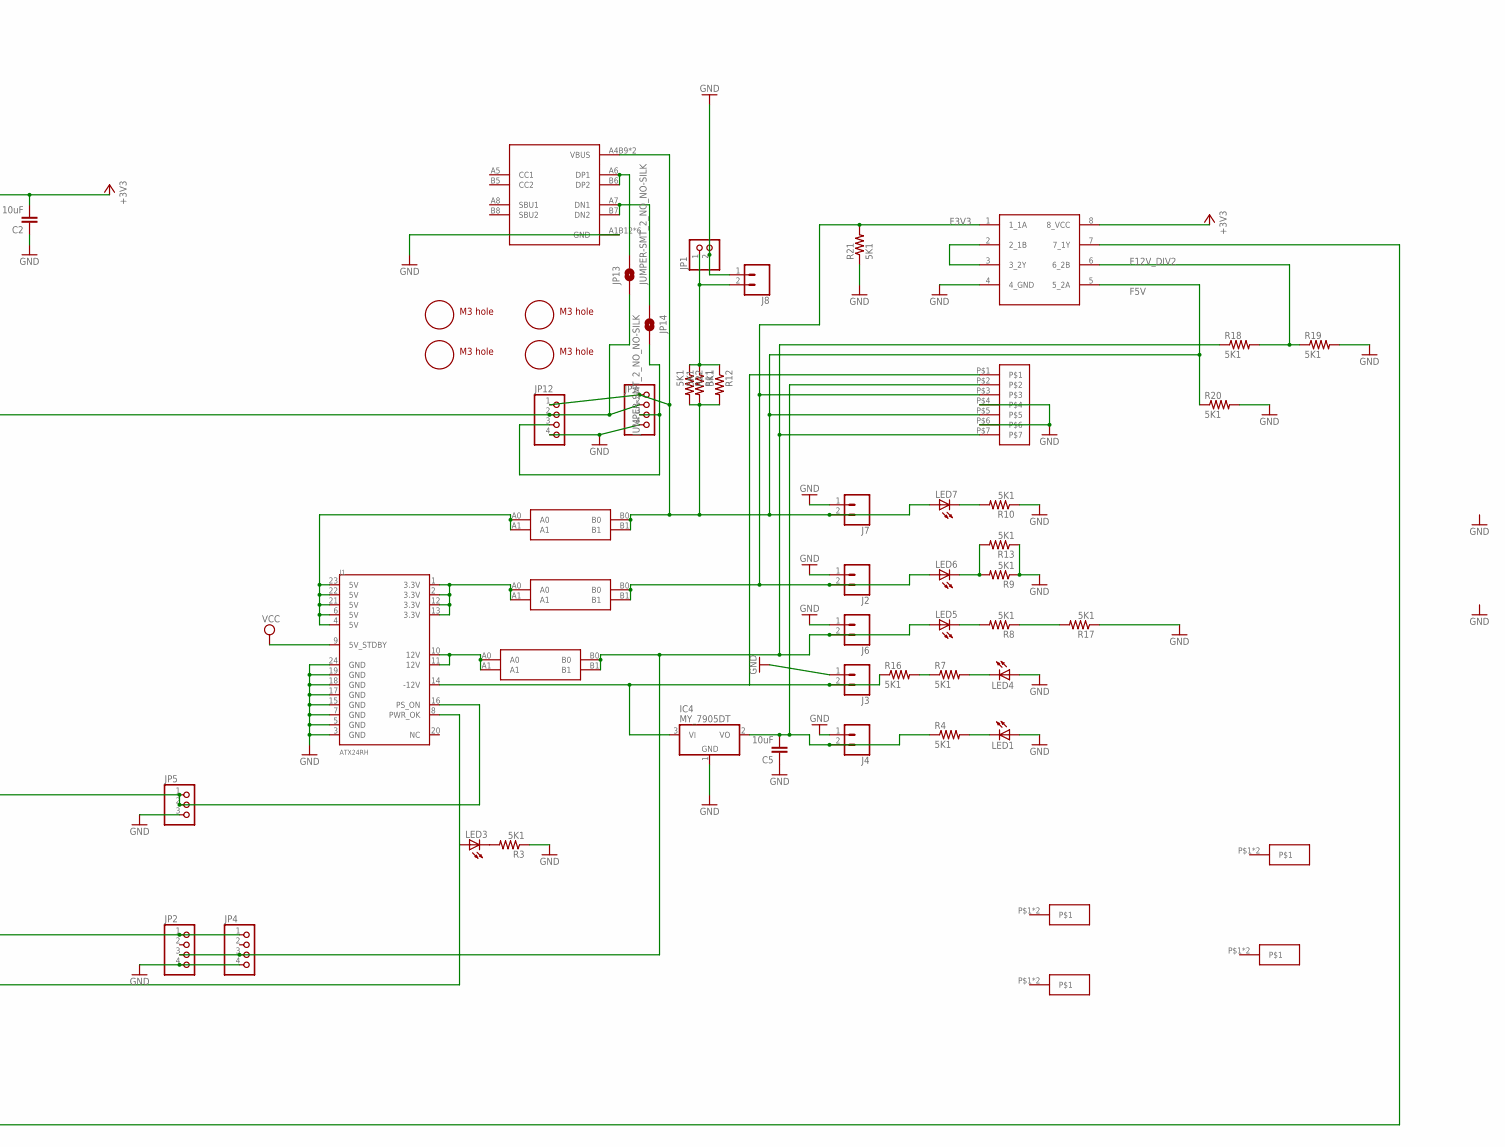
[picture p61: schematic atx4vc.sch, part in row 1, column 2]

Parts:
C1, C4: 100nF; 0805$1
C2, C5: 10uF; 0805$1
IC2: REG1117; SOT223
IC3: STM32F042F4; TSSOP20
IC4: MY_7905DT; ADAFRUIT_TO252
J1: ATX24RH; ATX24_RIGHT_ANGLE
J2, J3, J4, J5, J6, J8: CONN_023.5MM; SCREWTERMINAL-3.5MM-2
J7: CONN_023.5MM-NO_SILK; SCREWTERMINAL-3.5MM-2-NS
JP1, JP3, JP6: PINHD-1X2; 1X02
JP2, JP4: PINHD-1X4; 1X04
JP5: PINHD-1X3:1; 1X03
JP7, JP12: PINHD-1X6; 1X06
JP9: PINHD-2X4; 2X04
JP10: PINHD-1X1CB; 1X01-CLEANBIG
JP11: PINHD-1X3CB; 1X03-CLEANBIG
JP13, JP14: JUMPER-SMT_2_NO_NO-SILK; SMT-JUMPER_2_NO_NO-SILK
JP15: PINHD-2X3; 2X03
LED1, LED2, LED3, LED4, LED5, LED6, LED7, LED8: LEDCHIP-LED0805; CHIP-LED0805
R1, R2, R3, R4, R5, R6, R7, R8, R9, R10, R11, R12, R13, R14, R15, R16, R17, R18, R19, R20, R21, R22: 5K1; 0805
SW1, SW2, SW3, SW4, SW5, SW7: 324_SW; 342_SWICH_FOOT
U1, U2: USBC_16P; USBC_16P_FOOT
U$1, U$2, U$3, U$10: M3_MOUNTING_HOLE; M3_MOUNTING_HOLE_PACK
U$4: VH396; 396_7P
U$5, U$7, U$8: CAR_FUSE_HOLDER3IN1; FUSE_HOLDER_3IN1
U$6: 74LVC2G08; VSSOP08
U$9, U$11, U$12, U$13: WAGO257; WAGL257

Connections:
+3V3: C2.2, C4.2, IC2.2 (VOUT), IC2.4 (VOUT), IC3.5 (VDDA), IC3.16 (VDD), JP9.4, JP15.5, SW4.P$1 (1), SW4.P$4 (4), U$6.8 (8_VCC)
BUTTON1: IC3.4 (NRST), SW3.P$2 (2), SW3.P$3 (3)
BUTTON2: IC3.1 (BOOT0/PB8), JP9.3, R5.2, SW4.P$2 (2), SW4.P$3 (3)
F3V3: J2.2, LED6.A, R21.2, U$4.P$3, U$6.1 (1_1A), U$7.B0, U$7.B1
F5V: J7.2, JP7.1, JP12.1, LED7.A, R11.2, R12.2, R20.1, R22.2, U1.A4B9 (VBUS), U1.B4A9 (VBUS), U$4.P$5, U$6.5 (5_2A), U$8.B0, U$8.B1
F12V: J6.2, JP2.3, JP4.3, LED5.A, R18.1, U$4.P$7, U$5.B0, U$5.B1
F12V_DIV2: R18.2, R19.1, U$6.6 (6_2B)
GND: C1.1, C2.1, C4.1, C5.1, IC2.1 (GND), IC3.15 (VSS), IC4.1 (GND), J1.3 (GND), J1.5 (GND), J1.7 (GND), J1.15 (GND), J1.17 (GND), J1.18 (GND), J1.19 (GND), J1.24 (GND), J2.1, J3.1, J4.1, J5.2, J6.1, J7.1, J8.1, JP1.2, JP2.4, JP4.4, JP5.3, JP6.1, JP7.4, JP9.1, JP9.5, JP9.7, JP11.3, JP12.4, JP15.6, LED1.A, LED4.A, LED8.C, R1.2, R2.2, R3.1, R5.1, R6.1, R9.1, R10.1, R13.1, R17.1, R19.2, R20.2, R21.1, SW1.P$1 (1), SW1.P$4 (4), SW2.P$2 (2), SW2.P$3 (3), SW3.P$1 (1), SW3.P$4 (4), SW5.P$2 (2), SW5.P$3 (3), SW7.P$2 (2), SW7.P$3 (3), U1.A1B12 (GND), U1.B11A12 (GND), U1.P$13 (GND), U1.P$14 (GND), U1.P$15 (GND), U1.P$16 (GND), U2.A1B12 (GND), U2.B11A12 (GND), U2.P$13 (GND), U2.P$14 (GND), U2.P$15 (GND), U2.P$16 (GND), U$4.P$4, U$4.P$6, U$6.4 (4_GND)
unnamed: LED3.C, R3.2
unnamed: IC4.3 (VI), J1.14 (-12V), J3.2, R16.1, U$4.P$1
unnamed: IC3.20 (PA14), JP15.4
unnamed: IC3.19 (PA13), JP15.3
unnamed: LED1.C, R4.2
unnamed: IC3.12 (PA6), JP11.1, R14.1
unnamed: IC3.14 (PB1), JP2.1, JP4.1
unnamed: LED4.C, R7.2
unnamed: LED5.C, R8.2
unnamed: J1.4 (5V), J1.6 (5V), J1.21 (5V), J1.22 (5V), J1.23 (5V), U$8.A0, U$8.A1
unnamed: C5.2, IC4.2 (VO), J4.2, R4.1, U$4.P$2
unnamed: U$6.2 (2_1B), U$6.3 (3_2Y)
unnamed: IC3.6 (PA0), JP9.6, SW2.P$1 (1), SW2.P$4 (4)
unnamed: J1.1 (3.3V), J1.2 (3.3V), J1.12 (3.3V), J1.13 (3.3V), U$7.A0, U$7.A1
unnamed: J8.2, JP1.1, R11.1, R12.1, R22.1
unnamed: LED6.C, R9.2, R13.2
unnamed: LED8.A, R15.2
unnamed: LED7.C, R10.2
unnamed: J1.10 (12V), J1.11 (12V), U$5.A0, U$5.A1
unnamed: IC3.7 (PA1), JP9.8, SW5.P$1 (1), SW5.P$4 (4)
unnamed: IC3.8 (PA2), JP10.1
unnamed: JP3.2, U$6.7 (7_1Y)
unnamed: IC3.2 (PF0/OSC_IN), J1.16 (PS_ON), JP5.1, JP5.2
unnamed: IC3.3 (PF1/OSC_OUT), J5.1, JP6.2, SW1.P$2 (2), SW1.P$3 (3)
unnamed: IC3.10 (PA4), JP9.2, SW7.P$1 (1), SW7.P$4 (4)
unnamed: R7.1, R16.2
unnamed: LED2.C, R6.2
unnamed: R1.1, U2.B5 (CC2)
unnamed: R8.1, R17.2
unnamed: R2.1, U2.A5 (CC1)
unnamed: JP13.2, U1.A6 (DP1), U1.B6 (DP2)
unnamed: IC3.13 (PA7), JP7.2, JP12.2, JP13.1
unnamed: JP14.1, U1.A7 (DN1), U1.B7 (DN2)
unnamed: JP7.3, JP12.3, JP14.2
unnamed: IC3.9 (PA3), JP3.1
PG: IC3.18 (PA10/PA12), J1.8 (PWR_OK), JP15.1, LED3.A, U2.A6 (DP1), U2.B6 (DP2)
USB_DN: IC3.17 (PA9/PA11), R15.1, U2.A7 (DN1), U2.B7 (DN2)
VCC: C1.2, IC2.3 (VIN), J1.9 (5V_STDBY), JP11.2, JP15.2, LED2.A, R14.2, U2.A4B9 (VBUS), U2.B4A9 (VBUS)

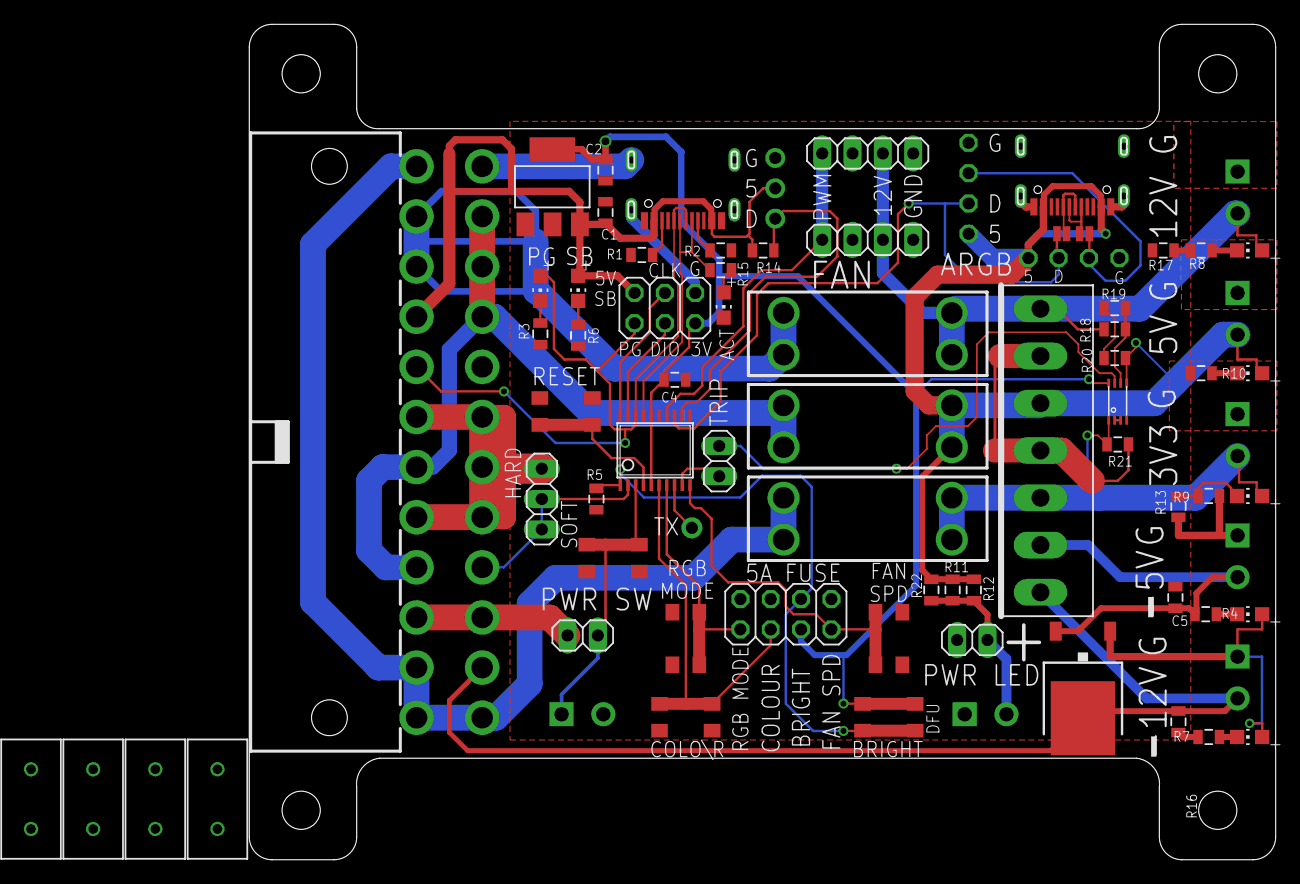
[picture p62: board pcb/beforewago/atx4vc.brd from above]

Board: 2 copper layers, 86.0 x 70.0 mm, 80 parts (0 on the bottom side), 46 nets.

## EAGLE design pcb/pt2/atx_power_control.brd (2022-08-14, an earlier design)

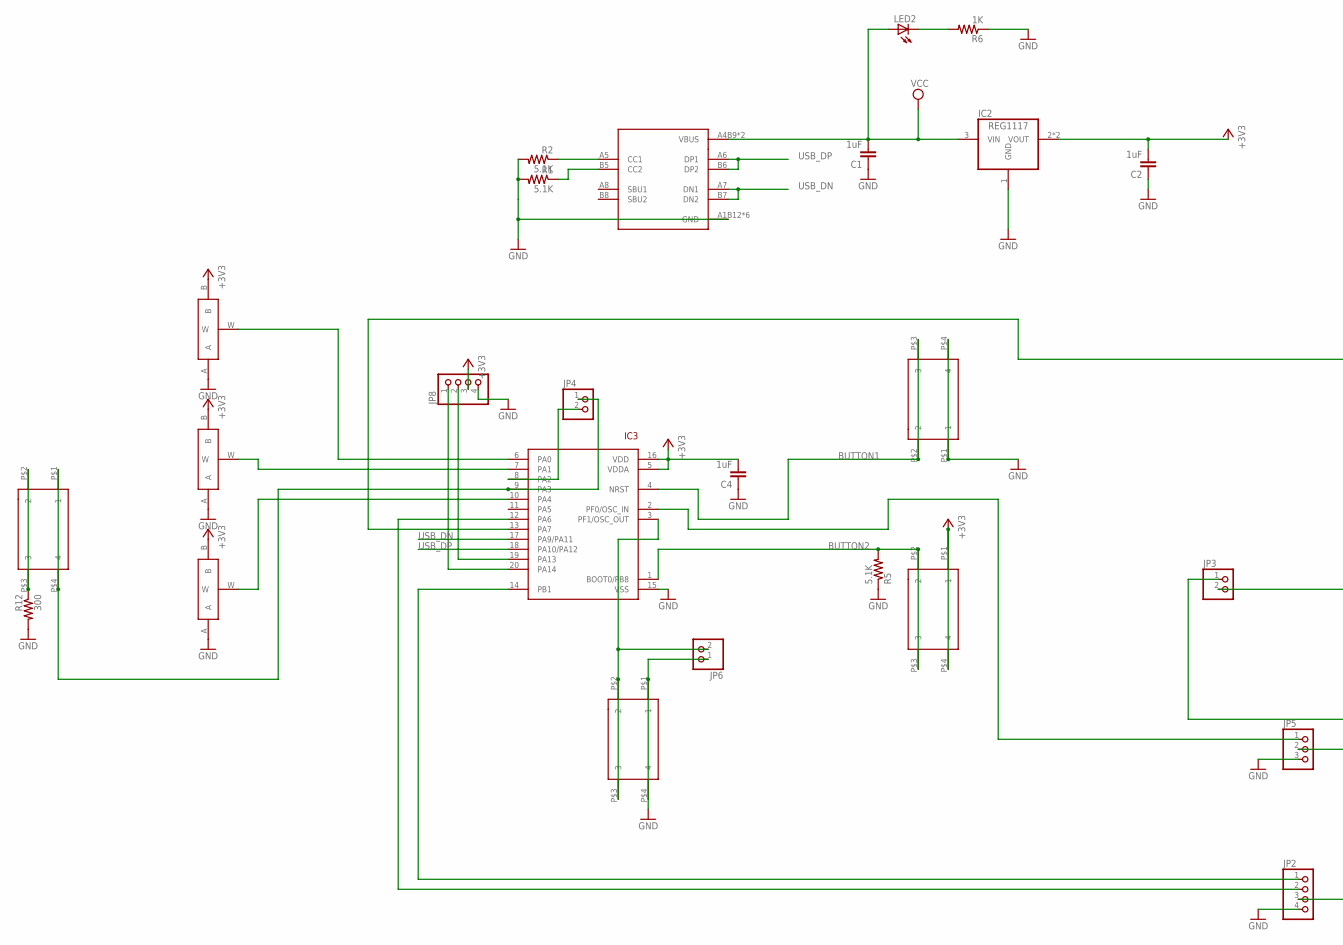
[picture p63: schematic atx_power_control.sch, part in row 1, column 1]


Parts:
C1, C2, C4, C5: 1uF; 0805@1
F1, F2, F3: FUSEX20MM; FUSE_5MM
IC2: REG1117; SOT223
IC3: STM32F042F4; TSSOP20
IC4: MY_7905DT; ADAFRUIT_TO252
J1: ATX24RH; ATX24_RIGHT_ANGLE
J2, J3, J4, J6, J7: CONN_023.5MM; SCREWTERMINAL-3.5MM-2
JP1, JP3, JP4, JP6: PINHD-1X2; 1X02
JP2, JP7, JP8: PINHD-1X4; 1X04
JP5: PINHD-1X3; 1X03
LED1, LED2, LED3, LED4, LED5, LED6, LED7: LEDCHIP-LED0805; CHIP-LED0805
R1, R2, R5: 5.1K; 0805
R3, R4, R6, R9, R10, R11: 1K; 0805
R7, R8: 5K; 0805
R12: 300; 0805
SW1, SW2, SW3, SW4: 324_SW; 342_SWICH_FOOT
U2: USBC_16P; USBC_16P_FOOT
U$1, U$2, U$3, U$10: M3_MOUNTING_HOLE; M3_MOUNTING_HOLE_PACK
U$4, U$5, U$6: 3386P

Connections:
+3V3: C2.2, C4.2, IC2.2 (VOUT), IC2.4 (VOUT), IC3.5 (VDDA), IC3.16 (VDD), JP8.3, SW4.P$1 (1), SW4.P$4 (4), U$4.B, U$5.B, U$6.B
BUTTON1: IC3.4 (NRST), SW3.P$2 (2), SW3.P$3 (3)
BUTTON2: IC3.1 (BOOT0/PB8), R5.2, SW4.P$2 (2), SW4.P$3 (3)
GND: C1.1, C2.1, C4.1, C5.1, IC2.1 (GND), IC3.15 (VSS), IC4.1 (GND), J1.3 (GND), J1.5 (GND), J1.7 (GND), J1.15 (GND), J1.17 (GND), J1.18 (GND), J1.19 (GND), J1.24 (GND), J2.1, J3.1, J4.1, J6.1, J7.1, JP2.4, JP5.3, JP6.1, JP7.3, JP7.4, JP8.4, LED1.A, LED4.A, R1.2, R2.2, R3.1, R5.1, R6.1, R8.1, R9.1, R10.1, R11.1, R12.2, SW1.P$1 (1), SW1.P$4 (4), SW3.P$1 (1), SW3.P$4 (4), U2.A1B12 (GND), U2.B11A12 (GND), U2.P$13 (GND), U2.P$14 (GND), U2.P$15 (GND), U2.P$16 (GND), U$4.A, U$5.A, U$6.A
unnamed: LED3.C, R3.2
unnamed: IC4.3 (VI), J1.14 (-12V), J3.2, R7.1
unnamed: IC3.20 (PA14), JP8.1
unnamed: IC3.19 (PA13), JP8.2
unnamed: LED1.C, R4.2
unnamed: IC3.12 (PA6), JP2.2
unnamed: IC3.14 (PB1), JP2.1
unnamed: LED4.C, R7.2
unnamed: LED5.C, R8.2
unnamed: F1.1, F1.2 (1), J1.4 (5V), J1.6 (5V), J1.21 (5V), J1.22 (5V), J1.23 (5V)
unnamed: C5.2, IC4.2 (VO), J4.2, R4.1
unnamed: F3.1, F3.2 (1), J1.1 (3.3V), J1.2 (3.3V), J1.12 (3.3V), J1.13 (3.3V)
unnamed: IC3.6 (PA0), U$4.W
unnamed: IC3.13 (PA7), JP7.2
unnamed: F1.3 (2), F1.4 (2), J7.2, JP7.1, LED7.A
unnamed: F2.1, F2.2 (1), J6.2, JP2.3, LED5.A
unnamed: JP1.2, R11.2
unnamed: LED6.C, R9.2
unnamed: F3.3 (2), F3.4 (2), J2.2, JP1.1, LED6.A
unnamed: LED7.C, R10.2
unnamed: F2.3 (2), F2.4 (2), J1.10 (12V), J1.11 (12V)
unnamed: IC3.7 (PA1), U$5.W
unnamed: IC3.10 (PA4), U$6.W
unnamed: IC3.2 (PF0/OSC_IN), JP5.1
unnamed: J1.16 (PS_ON), JP5.2
unnamed: IC3.3 (PF1/OSC_OUT), JP6.2, SW1.P$2 (2), SW1.P$3 (3)
unnamed: IC3.8 (PA2), JP4.2
unnamed: J1.8 (PWR_OK), JP3.1, LED3.A
unnamed: LED2.C, R6.2
unnamed: IC3.9 (PA3), JP4.1, SW2.P$1 (1), SW2.P$4 (4)
unnamed: R1.1, U2.B5 (CC2)
unnamed: R12.1, SW2.P$2 (2), SW2.P$3 (3)
unnamed: R2.1, U2.A5 (CC1)
USB_DN: IC3.17 (PA9/PA11), U2.A7 (DN1), U2.B7 (DN2)
USB_DP: IC3.18 (PA10/PA12), U2.A6 (DP1), U2.B6 (DP2)
VCC: C1.2, IC2.3 (VIN), J1.9 (5V_STDBY), JP3.2, LED2.A, U2.A4B9 (VBUS), U2.B4A9 (VBUS)

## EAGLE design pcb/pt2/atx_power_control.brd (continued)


Board: 2 copper layers, 86.0 x 70.0 mm, 55 parts (0 on the bottom side), 40 nets.

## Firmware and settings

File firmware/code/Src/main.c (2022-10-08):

/**
  ******************************************************************************
  * @file           : main.c
  * @brief          : Main program body
  ******************************************************************************
  ** This notice applies to any and all portions of this file
  * that are not between comment pairs USER CODE BEGIN and
  * USER CODE END. Other portions of this file, whether 
  * inserted by the user or by software development tools
  * are owned by their respective copyright owners.
  *
  * COPYRIGHT(c) 2022 STMicroelectronics
  *
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
  ******************************************************************************
  */
/* Includes ------------------------------------------------------------------*/
#include "main.h"
#include "stm32f0xx_hal.h"

/* USER CODE BEGIN Includes */
#include "neopixel.h"
#include "buttons.h"
#include <string.h>
#include "ee.h"
#include "animations.h"
#include <math.h>
#include "delay_us.h"
#include "my_1wire.h"
#include "ds18b20.h"

/* USER CODE END Includes */

IWDG_HandleTypeDef hiwdg;

SPI_HandleTypeDef hspi1;

TIM_HandleTypeDef htim2;
TIM_HandleTypeDef htim14;
TIM_HandleTypeDef htim17;

UART_HandleTypeDef huart2;

/* USER CODE BEGIN PV */

#define EEPROM_BUF_SIZE 8
uint8_t eeprom_buf[EEPROM_BUF_SIZE];

const char boot_message[] = "ATX4VC\ndekuNukem 2022";
const uint8_t version_major = 0;
const uint8_t version_minor = 0;
const uint8_t version_patch = 1;
uint8_t is_psu_on;
volatile uint32_t frame_interrupt_count;
uint8_t red_buf[NEOPIXEL_COUNT];
uint8_t green_buf[NEOPIXEL_COUNT];
uint8_t blue_buf[NEOPIXEL_COUNT];

hsvcolor global_hsv;
rgbcolor my_rgb;

uint8_t is_fan_auto_mode;

/* USER CODE END PV */

void SystemClock_Config(void);
static void MX_GPIO_Init(void);
static void MX_USART2_UART_Init(void);
static void MX_SPI1_Init(void);
static void MX_TIM17_Init(void);
static void MX_TIM14_Init(void);
static void MX_IWDG_Init(void);
static void MX_TIM2_Init(void);
static void MX_NVIC_Init(void);

void HAL_TIM_MspPostInit(TIM_HandleTypeDef *htim);
                                

/* USER CODE BEGIN PFP */

/* USER CODE END PFP */

/* USER CODE BEGIN 0 */

int fputc(int ch, FILE *f)
{
  HAL_UART_Transmit(&huart2, (unsigned char *)&ch, 1, 100);
  return ch;
}

int16_t ds18b20_result;

#define LED_BRIGHTNESS_STEP_COUNT 9
#define BREATHING_FRAME_COUNT 300
#define SIN_LOOKUP_SIZE 360
#define STARTUP_FADEIN_DURATION_FRAMES 60

const uint8_t sin_lookup[SIN_LOOKUP_SIZE] = {127, 129, 131, 134, 136, 138, 140, 142, 145, 147, 149, 151, 153, 156, 158, 160, 162, 164, 166, 168, 170, 173, 175, 177, 179, 181, 183, 185, 187, 189, 190, 192, 194, 196, 198, 200, 202, 203, 205, 207, 209, 210, 212, 214, 215, 217, 218, 220, 221, 223, 224, 226, 227, 228, 230, 231, 232, 234, 235, 236, 237, 238, 239, 240, 241, 242, 243, 244, 245, 246, 246, 247, 248, 248, 249, 250, 250, 251, 251, 252, 252, 252, 253, 253, 253, 254, 254, 254, 254, 254, 254, 254, 254, 254, 254, 254, 253, 253, 253, 252, 252, 252, 251, 251, 250, 250, 249, 248, 248, 247, 246, 246, 245, 244, 243, 242, 241, 240, 239, 238, 237, 236, 235, 234, 232, 231, 230, 228, 227, 226, 224, 223, 221, 220, 218, 217, 215, 214, 212, 210, 209, 207, 205, 203, 202, 200, 198, 196, 194, 192, 190, 189, 187, 185, 183, 181, 179, 177, 175, 173, 170, 168, 166, 164, 162, 160, 158, 156, 153, 151, 149, 147, 145, 142, 140, 138, 136, 134, 131, 129, 127, 125, 123, 120, 118, 116, 114, 112, 109, 107, 105, 103, 101, 98, 96, 94, 92, 90, 88, 86, 84, 81, 79, 77, 75, 73, 71, 69, 67, 65, 63, 62, 60, 58, 56, 54, 52, 51, 49, 47, 45, 44, 42, 40, 39, 37, 36, 34, 33, 31, 30, 28, 27, 26, 24, 23, 22, 20, 19, 18, 17, 16, 15, 14, 13, 12, 11, 10, 9, 8, 8, 7, 6, 6, 5, 4, 4, 3, 3, 2, 2, 2, 1, 1, 1, 0, 0, 0, 0, 0, 0, 0, 0, 0, 0, 0, 1, 1, 1, 2, 2, 2, 3, 3, 4, 4, 5, 6, 6, 7, 8, 8, 9, 10, 11, 12, 13, 14, 15, 16, 17, 18, 19, 20, 22, 23, 24, 26, 27, 28, 30, 31, 33, 34, 36, 37, 39, 40, 42, 44, 45, 47, 49, 51, 52, 54, 56, 58, 60, 62, 63, 65, 67, 69, 71, 73, 75, 77, 79, 81, 84, 86, 88, 90, 92, 94, 96, 98, 101, 103, 105, 107, 109, 112, 114, 116, 118, 120, 123, 125};

void animation_update(void)
{
  uint8_t current_animation = eeprom_buf[BUTTON_RGB_MODE] % ANIMATION_TYPE_COUNT;
  static double current_startup_percent = 0;
  static hsvcolor temp_global_hsv;
  temp_global_hsv.h = global_hsv.h;
  temp_global_hsv.s = global_hsv.s;
  if(frame_interrupt_count > STARTUP_FADEIN_DURATION_FRAMES)
  {
    temp_global_hsv.v = global_hsv.v;
  }
  else if(frame_interrupt_count <= 5)
  {
    temp_global_hsv.v = 0;
  }
  else
  {
    current_startup_percent = (double)frame_interrupt_count / STARTUP_FADEIN_DURATION_FRAMES;
    temp_global_hsv.v = (double)global_hsv.v * current_startup_percent;
  }

  if(current_animation == ANIMATION_SOLID_COLOR)
  {
    my_rgb = hsv2rgb(temp_global_hsv);
    memset(red_buf, my_rgb.r, NEOPIXEL_COUNT);
    memset(green_buf, my_rgb.g, NEOPIXEL_COUNT);
    memset(blue_buf, my_rgb.b, NEOPIXEL_COUNT);
  }
  else if(current_animation == ANIMATION_FLOWING_RAINBOW)
  {
    for (int i = 0; i < NEOPIXEL_COUNT; ++i)
    {
      hsvcolor this_hsv;
      this_hsv.h = i*12 + frame_interrupt_count;
      this_hsv.s = 255;
      this_hsv.v = temp_global_hsv.v;
      my_rgb = hsv2rgb(this_hsv);
      red_buf[i] = my_rgb.r;
      green_buf[i] = my_rgb.g;
      blue_buf[i] = my_rgb.b;
    }
  }
  else if(current_animation == ANIMATION_ROLLING_CROSSFADE)
  {
    uint8_t current_brightness = eeprom_buf[BUTTON_BRIGHTNESS] % LED_BRIGHTNESS_STEP_COUNT;
    for (int i = 0; i < NEOPIXEL_COUNT; ++i)
    {
      hsvcolor this_hsv;
      this_hsv.h = frame_interrupt_count/2;
      this_hsv.s = 255;
      if(current_brightness == 0 || temp_global_hsv.v == 0)
      {
        this_hsv.v = 0;
      }
      else
      {
        this_hsv.v = sin_lookup[((frame_interrupt_count*3/2 + i*10)) % SIN_LOOKUP_SIZE];
        this_hsv.v = (uint32_t)this_hsv.v * current_brightness / 8;
        if(frame_interrupt_count <= STARTUP_FADEIN_DURATION_FRAMES)
          this_hsv.v = (double)this_hsv.v * current_startup_percent;
      }
      my_rgb = hsv2rgb(this_hsv);
      red_buf[i] = my_rgb.r;
      green_buf[i] = my_rgb.g;
      blue_buf[i] = my_rgb.b;
    }
  }
  else if(current_animation == ANIMATION_CROSSFADE)
  {
    for (int i = 0; i < NEOPIXEL_COUNT; ++i)
    {
      hsvcolor this_hsv;
      this_hsv.h = frame_interrupt_count*2/5;
      this_hsv.s = 255;
      this_hsv.v = temp_global_hsv.v;
      my_rgb = hsv2rgb(this_hsv);
      red_buf[i] = my_rgb.r;
      green_buf[i] = my_rgb.g;
      blue_buf[i] = my_rgb.b;
    }
  }
  else if(current_animation == ANIMATION_ROLLING_DIM)
  {
    uint8_t current_brightness = eeprom_buf[BUTTON_BRIGHTNESS] % LED_BRIGHTNESS_STEP_COUNT;
    for (int i = 0; i < NEOPIXEL_COUNT; ++i)
    {
      hsvcolor this_hsv;
      this_hsv.h = temp_global_hsv.h;
      this_hsv.s = temp_global_hsv.s;
      if(current_brightness == 0 || temp_global_hsv.v == 0)
        this_hsv.v = 0;
      else
      {
        this_hsv.v = sin_lookup[((frame_interrupt_count*3/2 + i*10)) % SIN_LOOKUP_SIZE];
        this_hsv.v = (uint32_t)this_hsv.v * current_brightness / 8;
        if(frame_interrupt_count <= STARTUP_FADEIN_DURATION_FRAMES)
          this_hsv.v = (double)this_hsv.v * current_startup_percent;
      }
      my_rgb = hsv2rgb(this_hsv);
      red_buf[i] = my_rgb.r;
      green_buf[i] = my_rgb.g;
      blue_buf[i] = my_rgb.b;
    }
  }
  __disable_irq();
  neopixel_show(red_buf, green_buf, blue_buf);
  __enable_irq();
}

uint8_t animation_flag;
uint8_t ds18b20_update_flag;
// happens every 16ms
void HAL_TIM_PeriodElapsedCallback(TIM_HandleTypeDef *htim)
{
  frame_interrupt_count++;
  animation_flag = 1;
  // scan buttons every 64ms
  if(frame_interrupt_count % 4 == 0)
    scan_buttons();
  if(is_fan_auto_mode && frame_interrupt_count % 46 == 0)
    ds18b20_update_flag = 1;
}

#define FAN_PWM_FULL_POWER 501
#define FAN_SPEED_MANUAL_STEP_COUNT 8
#define FAN_SPEED_TOTAL_STEP_COUNT 9

#define DEG_C_LOOKUP_SIZE 64
const uint16_t deg_c_to_fan_timer_lookup[DEG_C_LOOKUP_SIZE] = {100, 100, 100, 100, 100, 100, 100, 100, 100, 100, 100, 100, 100, 100, 100, 100, 100, 100, 100, 100, 100, 100, 100, 100, 100, 115, 131, 147, 163, 179, 195, 211, 227, 243, 259, 275, 291, 307, 323, 339, 355, 371, 387, 403, 419, 435, 451, 467, 483, 499, 501, 501, 501, 501, 501, 501, 501, 501, 501, 501, 501, 501, 501, 501};
const uint16_t fan_speend_lookup[FAN_SPEED_MANUAL_STEP_COUNT] = {0, 20*5, 40*5, 55*5, 65*5, 80*5, 90*5, FAN_PWM_FULL_POWER};

uint16_t deg_c_to_fan_timer(int16_t deg_c)
{
  if(deg_c < 0)
    return 20*5; // 20%
  if(deg_c >= DEG_C_LOOKUP_SIZE)
    return FAN_PWM_FULL_POWER; // 100%
  return deg_c_to_fan_timer_lookup[deg_c];
}

#define LED_COLOR_STEP_COUNT 27
void set_led_color(uint8_t button_status)
{
  uint8_t color_index = button_status % LED_COLOR_STEP_COUNT;
  if(color_index == LED_COLOR_STEP_COUNT-1) // color_index 26 = white
  {
    global_hsv.h = 0;
    global_hsv.s = 0;
  }
  else
  {
    global_hsv.h = color_index * 10; // 0, 10, 20, ..., 250
    global_hsv.s = 255;
  }
}

const uint8_t led_brightness_lookup[LED_BRIGHTNESS_STEP_COUNT] = {0, 1, 2, 3, 4, 5, 6, 7, 8};
void set_led_brightness(uint8_t button_status)
{
  global_hsv.v = led_brightness_lookup[button_status % LED_BRIGHTNESS_STEP_COUNT] * 28; // change to 28 for full scale
}

void user_led_blink(uint8_t count, uint8_t duration_ms, uint8_t include_argb)
{
  uint8_t blink_brightness = global_hsv.v/4;
  if(blink_brightness < 16)
    blink_brightness = 16;
  for (int i = 0; i < count; ++i)
  {
    if(include_argb)
    {
      memset(red_buf, blink_brightness, NEOPIXEL_COUNT);
      memset(green_buf, blink_brightness, NEOPIXEL_COUNT);
      memset(blue_buf, blink_brightness, NEOPIXEL_COUNT);
      __disable_irq();
      neopixel_show(red_buf, green_buf, blue_buf);
      __enable_irq();
    }
    HAL_GPIO_WritePin(USER_LED_GPIO_Port, USER_LED_Pin, GPIO_PIN_SET);
    HAL_IWDG_Refresh(&hiwdg);
    HAL_Delay(duration_ms);
    HAL_IWDG_Refresh(&hiwdg);
    if(include_argb)
    {
      memset(red_buf, blink_brightness / 8, NEOPIXEL_COUNT);
      memset(green_buf, blink_brightness / 8, NEOPIXEL_COUNT);
      memset(blue_buf, blink_brightness / 8, NEOPIXEL_COUNT);
      __disable_irq();
      neopixel_show(red_buf, green_buf, blue_buf);
      __enable_irq();
    }
    HAL_GPIO_WritePin(USER_LED_GPIO_Port, USER_LED_Pin, GPIO_PIN_RESET);
    HAL_IWDG_Refresh(&hiwdg);
    HAL_Delay(duration_ms);
    HAL_IWDG_Refresh(&hiwdg);
  }
}

void set_fanspeed(void)
{
  uint8_t fan_index = eeprom_buf[BUTTON_FANSPEED] % FAN_SPEED_TOTAL_STEP_COUNT;
  printf("fan %d", fan_index);
  if(fan_index < FAN_SPEED_MANUAL_STEP_COUNT)
  {
    printf(" M\n");
    is_fan_auto_mode = 0;
    htim14.Instance->CCR1 = fan_speend_lookup[fan_index];
  }
  else
  {
    printf(" A\n");
    is_fan_auto_mode = 1;
  }
}

void restore_button_settings(void)
{
  set_fanspeed();
  // default value
  global_hsv.h = 127;
  global_hsv.s = 255;
  global_hsv.v = 8;
  set_led_color(eeprom_buf[BUTTON_COLOR]);
  set_led_brightness(eeprom_buf[BUTTON_BRIGHTNESS]);
}

uint32_t last_button_press;
void handle_button_press(uint8_t button_index)
{
  // debounce 245ms
  if(micros() - last_button_press <= 245000)
    return;
  last_button_press = micros();

  eeprom_buf[button_index]++;
  if(button_index == BUTTON_FANSPEED)
  {
    set_fanspeed();
    uint8_t fan_index = eeprom_buf[BUTTON_FANSPEED] % FAN_SPEED_TOTAL_STEP_COUNT;
    if(fan_index == FAN_SPEED_MANUAL_STEP_COUNT - 1)
      user_led_blink(3, 66, 1); // fastest manual speed, fast blink 3 times
    else if(fan_index >= FAN_SPEED_MANUAL_STEP_COUNT) 
      user_led_blink(5, 200, 1); // in auto mode, slow blink 5 times
    else
      user_led_blink(1, 66, 1); // button pressed, fast blink once
  }
  else if(button_index == BUTTON_COLOR)
  {
    set_led_color(eeprom_buf[button_index]);
    user_led_blink(1, 66, 0);
  }
  else if(button_index == BUTTON_BRIGHTNESS)
  {
    set_led_brightness(eeprom_buf[button_index]);
    user_led_blink(1, 66, 0);
    if(eeprom_buf[button_index] % LED_BRIGHTNESS_STEP_COUNT == LED_BRIGHTNESS_STEP_COUNT - 1)
      user_led_blink(2, 66, 1);
  }
  else if(button_index == BUTTON_POWER)
  {
    is_psu_on = (is_psu_on + 1) % 2;
    if(is_psu_on)
      frame_interrupt_count = 0;
    HAL_GPIO_WritePin(PWR_ON_GPIO_Port, PWR_ON_Pin, 1-is_psu_on);
    user_led_blink(1, 66, 0);
    return; // no need to save power button status
  }
  else if(button_index == BUTTON_RGB_MODE)
  {
    user_led_blink(1, 66, 0);
  }
  ee_format();
  ee_write(0, EEPROM_BUF_SIZE, eeprom_buf);
}

/* USER CODE END 0 */

/**
  * @brief  The application entry point.
  *
  * @retval None
  */
int main(void)
{
  /* MCU Configuration----------------------------------------------------------*/

  /* Reset of all peripherals, Initializes the Flash interface and the Systick. */
  HAL_Init();

  /* Configure the system clock */
  SystemClock_Config();

  /* Initialize all configured peripherals */
  MX_GPIO_Init();
  MX_USART2_UART_Init();
  MX_SPI1_Init();
  MX_TIM17_Init();
  MX_TIM14_Init();
  MX_IWDG_Init();
  MX_TIM2_Init();

  /* Initialize interrupts */
  MX_NVIC_Init();
  /* USER CODE BEGIN 2 */
  delay_us_init(&htim2);
  
  /*
    check POWER_GOOD signal immediately after boot
    if high, STM32 most likely just had a reset by IWDG
    in which case, activate PS_ON to keep it going
  */
  if(HAL_GPIO_ReadPin(ATX_PG_GPIO_Port, ATX_PG_Pin) == GPIO_PIN_SET)
    is_psu_on = 1;
  HAL_GPIO_WritePin(PWR_ON_GPIO_Port, PWR_ON_Pin, 1-is_psu_on);

  /* USER CODE END 2 */

  /* Infinite loop */
  /* USER CODE BEGIN WHILE */
  printf("%s\nv%d.%d.%d\n", boot_message, version_major, version_minor, version_patch);

  if(HAL_GPIO_ReadPin(BTN_COLOR_GPIO_Port, BTN_COLOR_Pin) == GPIO_PIN_RESET)
    printf("ee_format: %d\n", ee_format());

  memset(eeprom_buf, 0, EEPROM_BUF_SIZE);
  ee_read(0, EEPROM_BUF_SIZE, eeprom_buf);
  eeprom_buf[BUTTON_POWER] = 0;
  restore_button_settings();

  HAL_TIM_Base_Start_IT(&htim17);

  HAL_TIM_Base_Start(&htim14);
  HAL_TIM_PWM_Init(&htim14);
  HAL_TIM_PWM_Start(&htim14, TIM_CHANNEL_1);
  ds18b20_start_conversion();

  while (1)
  {
    HAL_IWDG_Refresh(&hiwdg);
    for (int i = 0; i < BUTTON_COUNT; ++i)
    {
      if(is_pressed(i))
      {
        handle_button_press(i);
        service_press(i);
      }
      // for compatibility with a flip switch
      if(i == BUTTON_POWER && is_released_but_not_serviced(i))
      {
        service_press(i);
        if(micros() - button_status[i].last_press_ts > 750000 && is_psu_on)
        {
          is_psu_on = 0;
          HAL_GPIO_WritePin(PWR_ON_GPIO_Port, PWR_ON_Pin, GPIO_PIN_SET);
        }
      }
    }
      
  /* USER CODE END WHILE */

  /* USER CODE BEGIN 3 */

    if(animation_flag && is_psu_on)
    {
      HAL_GPIO_WritePin(GPIOA, DEBUG_Pin, GPIO_PIN_SET);
      animation_update();
      animation_flag = 0;
      HAL_GPIO_WritePin(GPIOA, DEBUG_Pin, GPIO_PIN_RESET);
    }

    // if atx4vc did not turn psu on, but PG is still high,
    // it is in hard power mode 
    if(is_psu_on == 0 && HAL_GPIO_ReadPin(ATX_PG_GPIO_Port, ATX_PG_Pin))
    {
      HAL_Delay(250); // give PG some time to decay
      if(HAL_GPIO_ReadPin(ATX_PG_GPIO_Port, ATX_PG_Pin))
        is_psu_on = 1;
    }

    if(ds18b20_update_flag)
    {
      ds18b20_result = ds18b20_get_temp();
      printf("tp %d %d\n", ds18b20_result >> 4, deg_c_to_fan_timer(ds18b20_result >> 4));
      if(ds18b20_result == -1) // sensor unplugged, full power failsafe
        htim14.Instance->CCR1 = FAN_PWM_FULL_POWER;
      else
        htim14.Instance->CCR1 = deg_c_to_fan_timer(ds18b20_result >> 4);
      ds18b20_update_flag = 0;
      ds18b20_start_conversion();
    }
  }
  /* USER CODE END 3 */

}

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


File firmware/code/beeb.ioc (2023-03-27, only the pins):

Mcu.UserName=STM32F042F6Px
PA0.GPIO_Label=BTN_COLOR
PA0.Signal=GPIO_Input
PA1.GPIO_Label=BTN_RGB_MODE
PA1.Signal=GPIO_Input
PA10.GPIO_Label=ATX_PG
PA10.Signal=GPIO_Input
PA13.Signal=SYS_SWDIO
PA14.Signal=SYS_SWCLK
PA2.Signal=USART2_TX
PA3.GPIO_Label=DEBUG
PA3.Signal=GPIO_Output
PA4.GPIO_Label=BTN_FANSPEED
PA4.Signal=GPIO_Input
PA5.Signal=SPI1_SCK
PA6.GPIO_Label=ONEWIRE_DATA
PA6.Signal=GPIO_Output
PA7.Signal=SPI1_MOSI
PA9.GPIO_Label=USER_LED
PA9.Signal=GPIO_Output
PB1.Signal=S_TIM14_CH1
PB8.GPIO_Label=BTN_BRIGHTNESS
PB8.Signal=GPIO_Input
PF0-OSC_IN.GPIO_Label=PWR_ON
PF0-OSC_IN.Signal=GPIO_Output
PF1-OSC_OUT.GPIO_Label=BTN_POWER
PF1-OSC_OUT.Signal=GPIO_Input

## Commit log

2022-07-18 added plate and pcb files
    [atx_power_control.brd, atx_power_control.sch]
2022-07-18 working on PCB
    [Benchtop Power Supply-v13.brd, Benchtop Power Supply-v13.sch, SparkFun_Qwiic_Motor_Driver.brd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]
2022-07-18 pcb done sent to fab
    [atx_power_control.brd]
2022-07-25 adjusted pcb
    [atx_power_control.brd, atx_power_control.sch]
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2022-08-09 working on new ATX PCB
    [atx_power_control.brd, atx_power_control.sch]
2022-08-10 atx board finished
    [atx_power_control.brd, atx_power_control.sch]
2022-08-10 updated changelog, adjusted silkscreen
    [atx_power_control.brd]
2022-08-14 updated atx adaptor plate, removed terminal block GND thermals
    [atx_power_control.brd, atx_power_control.sch]
2022-08-14 updated atx board
    [atx_power_control.brd, atx_power_control.sch]
2022-08-15 removed pot and added buttons and header
    [atx_power_control.brd, atx_power_control.sch]
2022-08-19 updated plate
    [atx_power_control.brd]
2022-08-22 making backlight PCB
    [led.brd, led.sch]
2022-08-23 atx rgb done, updated atx psu board too
    [atx_power_control.brd, atx_power_control.sch, led.brd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]
2022-08-23 cleaned up files
    [atx_power_control.brd, atx_power_control.sch, led.brd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]
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2022-08-30 updated pcb
    [atx_power_control.brd, atx_power_control.sch]
2022-08-30 fixed led board silkscreen, changed ATX4VC to use PG signal
    [atx_power_control.brd, atx_power_control.sch, led.brd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]
2022-08-30 added UART RX header, brightness button shared with DFU button
    [atx_power_control.brd, atx_power_control.sch]
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2022-08-31 adjusted fuse holder on PCB
    [atx_power_control.brd]
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2022-09-01 added compatibilty with flip switch power
    [buttons.c, main.c, scrap.c]
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2022-09-01 added selector jumper for power-on detect
    [atx_power_control.brd, atx_power_control.sch]
2022-09-01 adjusted power button and power LED
    [atx_power_control.brd, atx_power_control.sch]
2022-09-03 optimised traces routing for current carrying
    [atx_power_control.brd, atx_power_control.sch]
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2022-09-03 updated PCB to use car fuse holder
    [atx_power_control.brd, atx_power_control.sch]
2022-09-03 moved bbc files to its own repo
    [atx_power_control.brd, atx_power_control.sch, led.brd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]
2022-09-04 added dual fan and ARGB headers, ready for new run
    [atx_power_control.brd, atx_power_control.sch]
2022-09-09 fixed fuse holder footprint
    [atx_power_control.brd, atx_power_control.sch]
2022-09-22 troubleshooting coolermaster RGB bug
    [atx_power_control.brd]
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2022-09-22 adjusted LED resistor value, optimised GND plane
    [atx_power_control.brd, atx_power_control.sch]
2022-09-26 moved ARGB header, removed GND thermals, jumper pad on USBC data lines, finishing touches
    [atx_power_control.brd, atx_power_control.sch]
2022-09-26 wired to softpower by default
    [atx_power_control.brd, atx_power_control.sch]
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2022-09-27 changed to current name
    [atx4vc.brd, atx4vc.sch]
2022-09-29 added new rolling dim animation, fixing a bug
    [buttons.c, main.c, scrap.c]
2022-09-29 fixed interrupt latency bug
    [beeb.ioc, main.c, scrap.c]
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2022-09-30 fixed animation timing issue
    [beeb.ioc, main.c, scrap.c]
2022-09-30 fixed power up animation detect
    [main.c]
2022-09-30 fixed power up fade in timing
    [main.c]
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2022-10-11 moved argb header to make more room
    [atx4vc.brd]
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2022-11-09 working on mac plus adaptor
    [macplus.brd, macplus.sch]
2022-11-09 mac plus adaptor pretty much done
    [macplus.brd, macplus.sch]
2022-11-11 working on mac SE adaptor
    [macse.brd, macse.sch]
2022-11-11 mac SE adaptor done
    [macse.brd, macse.sch]
2022-11-11 added mac SE power board
    [Breadboard Power Supply v10.brd, Breadboard Power Supply v10.sch, mac_se_power_switch.brd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]
2022-11-11 getting ready for a PCB run
    [macse.brd]
2022-11-19 adding power connector and fuse detect
    [atx4vc.brd, atx4vc.sch]
2022-11-23 updated mac plus atx adaptor
    [macplus.brd, macplus.sch]
2022-11-24 updating mac SE atx adaptor
    [mac_se_power_switch.brd, mac_se_power_switch.sch, macse.brd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]
2022-11-24 updated mac SE pcb
    [mac_se_power_switch.brd, macse.brd, macse.sch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]
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2022-11-26 updated silkscreen and switched to terminal block for power input
    [appleii.brd, appleii.sch]
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2022-12-12 moved picoPSU adaptor to its own repo at PicoRC
    [Breadboard Power Supply v10.brd, Breadboard Power Supply v10.sch, appleii.brd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]
2022-12-13 updated flip switch footprint
2023-03-09 updated fuse detect chip trace
    [atx4vc.brd, atx4vc.sch]
2023-03-09 switched to WAGO connectors
    [atx4vc.brd, atx4vc.sch]
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2023-03-27 working on seperate MCU version
    [nomcu.brd, nomcu.sch]
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2023-04-03 working on new version
    [nomcu.brd, nomcu.sch]
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2023-04-06 added 5VSB to terminal block, cleaned up files
    [atx4vc.brd, atx4vc.sch, atx_power_control.brd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]
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2023-04-11 fixed a wrong signal
    [daughterboard.brd, daughterboard.sch]
2023-04-11 added pullup on 1wire, gnd pour cleanup
    [daughterboard.brd, daughterboard.sch]
2023-04-11 moved pin headers to the outer edge
    [daughterboard.brd]
2023-04-11 freed up more space
    [atx4vc.brd, daughterboard.brd]
2023-04-18 finishing touches before production run
    [atx4vc.brd, atx4vc.sch, daughterboard.brd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]
2023-05-18 added PG on terminal block, moved things around
    [atx4vc.brd, atx4vc.sch]
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2023-08-14 adjust screw location, clean up traces
    [atx4vc.brd]
2023-11-27 added power LED resistor bypass
    [atx4vc.brd, atx4vc.sch]
2023-12-27 minor adjustments for next production run
    [atx4vc.brd, atx4vc.sch]
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2023-12-27 adjusted snapoff holes
    [atx4vc.brd]
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2024-06-02 rail silkscreen on bottom
    [atx4vc.brd]
2024-10-09 trying out power ic
    [atx4vc.brd, atx4vc.sch]
2024-10-14 soft power ic tested working
    [atx4vc.brd, atx4vc.sch]
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2026-06-30 clean up kicad PCB
    [atx4vc.kicad_pcb]
2026-07-16 adjusted power mode silkscreen
    [atx4vc.kicad_pcb]
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

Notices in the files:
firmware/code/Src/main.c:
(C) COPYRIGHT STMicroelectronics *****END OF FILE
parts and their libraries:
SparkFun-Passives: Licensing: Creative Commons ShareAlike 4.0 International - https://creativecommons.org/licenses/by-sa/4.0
